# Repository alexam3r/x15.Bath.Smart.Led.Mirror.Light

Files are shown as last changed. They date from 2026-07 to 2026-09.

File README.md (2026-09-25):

# Проект "Умное зеркало" (интеграция HA, Yandex Алиса)








Умное зеркало в ванной на **ESP32-S3 Zero** с адресной лентой **SK6812-RGBW** (168 светодиодов), управляемое через **Home Assistant** и **Алису** (Yandex Smart Home).

Прошивка (v1.5.1, модульная архитектура — см. [ARCHITECTURE.md](ARCHITECTURE.md)) оптимизирована для
low-latency анимации на двух ядрах, с автодетекцией движения (PIR) и аппаратной кнопкой.

---

## Возможности

- **2 режима работы**: solid (RGB, тёплый оранжевый по умолчанию) и Макияж (белый канал W).
- **6 временных эффектов** (запускаются поверх текущего режима): тёмная змейка (`dark`), радужная змейка
  (`rainbow`; с v1.4.2 шесть её цветов при каждом запуске идут в случайном порядке), волна с затемнением (`wave`), «пламя» (`flame`, v1.4.0–1.4.1) — участки по 10–12 светодиодов
  с мягкими краями по 3–4, каждый в своё время, плавно гаснут до 30 % (для глаза) за 3–5 секунд и возвращаются, ~20 секунд,
  «угли» (`embers`, v1.2.0, переделан в v1.3.0–1.3.1) — отдельные пятна
  по очереди, каждое в своё время, мягко гаснут до 10–30 % с плавным краем по 2 светодиода и возвращаются, ~20 секунд,
  и «метеор» (`comet`, v1.2.0) — белая голова с гаснущим хвостом облетает кольцо за 6 секунд. «Свеча»
  (`candle`) была в v1.2.0 и убрана в v1.3.0: её мерцание было почти незаметно. «Дыхание» (`breathe`,
  v1.2.0–v1.3.2) гасило всё кольцо разом; в v1.4.0 его заменило «пламя».
- **JSON Light `effect`** — одно поле в команде `set` принимает `solid, makeup, random, dark, rainbow, wave, flame, embers, comet`:
  базовые режимы и запуск эффектов не требуют отдельных топиков.
- **Аппаратная кнопка** (триггер Шмитта SN74LVC2G14): 1 клик — вкл/выкл, 2 клика — toggle Макияж, 3 клика — случайный эффект, удержание — плавное диммирование при горящем свете, а при выключенном — ночной режим (v1.5.0).
- **Сброс настроек при выключении** — цвет возвращается к тёплому (255, 140, 50), яркость к 100%, режим — solid.
  Автоматика, ночной режим и глитч при этом не сбрасываются и переживают даже программную перезагрузку
  (watchdog, сбой) — но не отключение питания (v1.2.1).
- **Плавные переходы цвета и яркости** (v1.2.0) — смена цвета, яркости или режима из HA/Алисы, переключателем
  Макияжа или двойным кликом идёт плавно за 0,5 с; диммирование кнопкой — как прежде, сразу.
- **PIR с фиксированным кулдауном 15 секунд** — после ручного выключения автоматика «спит», чтобы свет не зажёгся в спину выходящему человеку.
- **Blackout-окно 2 секунды после любого OFF** — PIR полностью игнорируется в первые секунды, чтобы ложные импульсы от «отлипающего» датчика или отражений не запустили slide-IN поверх идущего slide-OUT.
- **«Глухое» отключение PIR через MQTT** — отдельная команда `motion_disable/set` для Node-RED: «на ночь отключить реакцию на PIR». Не выводится в HA — независимый флаг, отдельный от обычной автоматики `motion/set`. Если в момент команды зеркало горит, оно само гаснет. Снимается командой `OFF` или удержанием кнопки (≥0.5 с). Любое включение (кнопка / MQTT / makeup-on) автоматически снимает disable.
- **Автоматика PIR (`motion/set`) — постоянный переключатель.** Состояние держится до явной команды
  `motion/set ON`/`OFF` (в HA — `switch`), а не «отскакивает» самопроизвольно через 15 секунд.
- **Таймер автовыключения 15 минут**, а в режиме Макияж — **45 минут** (v1.2.0): красятся дольше, чем принимают душ.
  PIR, который час подряд показывает движение без единой паузы, считается неисправным и перестаёт держать
  свет, пока не «отпустит» (v1.2.1).
  Если в ванной никого нет, свет гаснет; любое движение сбрасывает таймер в ноль, смена режима — тоже.
- **Предупреждение за минуту до автовыключения** (v1.2.0) — свет плавно притухает вдвое (для глаза, с v1.3.0) за 2 с: махните рукой,
  и он вернётся к полной яркости за 1 с, а таймер начнётся заново. Настройка яркости в HA при этом не меняется.
- **Глитч «сбой неона»** (v1.1.0) — примерно раз в минуту (случайно 45–90 с) случайный участок из 3–6 соседних
  светодиодов на 300–600 мс мерцает, как барахлящая неоновая трубка: гаснет, тлеет, вспыхивает; по краям
  — по 4–6 светодиодов плавного перехода к обычному свету, равномерного для глаза (v1.3.0; в v1.1.1 было 2–3).
  Только в solid,
  когда зеркало горит в покое (без эффекта, анимации и зажатой кнопки) и автоматика включена; состояние в HA
  не меняет. Выключается переключателем «Зеркало: глитч» (`glitch/set`).
- **Автоэффект через 4-5 минут простоя** (рандом в этом диапазоне после каждого запуска) — только в solid-режиме. В Макияже автоэффекты не запускаются; ручные (3 клик / кнопка HA) работают в обоих режимах.
- **`availability`** (LWT, retained) — Home Assistant показывает зеркало «недоступно», если оно пропало из сети (потеря питания/WiFi/MQTT).
- **`pir/state`** — отдельный retained-топик с сырым уровнем PIR (реальное движение); не путать с `motion/state` (флаг автоматики).
- **Диагностика в Home Assistant** (v1.2.0) — отдельный топик `diag` раз в минуту: аптайм, уровень WiFi,
  причина последней перезагрузки, свободная и минимальная свободная память, крупнейший свободный блок
  (v1.2.1), последний запущенный эффект (v1.2.2, приходит сразу при запуске), версия прошивки. Шесть
  диагностических сенсоров; в основной статус светильника не попадает, чтобы не дёргать его каждую секунду.
- **Serial-логи** — PIR rising-edge (не спамит на каждом тике цикла), mode transitions, авто-выключение, эффекты, однократно — запас стека `NetworkTask` после первого подключения к MQTT. Включаются флагом сборки `DEBUG_LOG_ENABLED` — окружение `esp32-s3-zero-debug` (1) или `esp32-s3-zero` (0, продакшен), см. `platformio.ini`.
- **Разделённые MQTT-топики** — `set` (JSON Light), `motion/set`, `motion_disable/set`, `makeup/set`, `effect/set`.
- **Network watchdog** — если Wi-Fi недоступен **более 5 минут**, ESP перезагружается, но только когда зеркало уже 30 секунд тёмное и никто не двигается: горящее зеркало не гаснет посреди использования, а перезагрузка сразу после выключения не зажжёт свет в спину уходящему. Пропажа одного MQTT-брокера (HA обновляется) перезагрузку не вызывает; если брокер недоступен больше 30 минут при живом Wi-Fi, зеркало переподключается к Wi-Fi — это лечит протухший адрес после замены роутера (v1.2.1). Локальная работа зеркала (PIR, кнопка, эффекты) при отсутствии сети не страдает.
- **Yandex Smart Home** — голосовое управление через Алису: «включи зеркало», «поставь режим макияж», «поставь таймер 45 минут», «выключи автоматику».

---

## Аппаратная часть

| Компонент | Кол-во / модель |
|---|---|
| MCU | ESP32-S3 Zero (4 MB Flash, USB-CDC) |
| LED-лента | SK6812 RGBW, 60 LED/m |
| Лента слева | 66 LED (PIN 4) |
| Лента справа | 102 LED (PIN 5) |
| Status LED | 1 × WS2812B на PIN 21 |
| PIR-датчик | HC-SR501 / AM312 на PIN 6 |
| Кнопка | Тактовая на PIN 7 (через SN74LVC2G14) |

### Схема подключения

```
                         ┌─────────────────┐
                         │   ESP32-S3 Zero │
                         │                 │
   SK6812 (left, 66) ────┤ GPIO 4   GPIO 5 ├──── SK6812 (right, 102)
                         │                 │
   PIR (HC-SR501) ───────┤ GPIO 6   GPIO 7 ├──── Кнопка → SN74LVC2G14 → GND
                         │                 │
   Status LED (WS2812B) ─┤ GPIO 21  USB-CDC├──── Serial / питание
                         │                 │
                         │    3V3   GND    │
                         └─────────────────┘
```

### Питание

- Ленты 5 В, ток до ~3.5 А при 168 LED на полной яркости белого.
- Рекомендуется отдельный источник 5 В × 5 А, общая земля с ESP32.
- Питание лент через MOSFET или силовой ключ с управлением от GPIO, если хотите гарантированно снимать питание в OFF.

---

## Софт

### Требования

- [PlatformIO](https://platformio.org/) (CLI или IDE)
- Python 3 (для тулчейна)

### Сборка и прошивка

```bash
git clone git@github.com:alexam3r/x15.Bath.Smart.Led.Mirror.Light.git
cd x15.Bath.Smart.Led.Mirror.Light/firmware
pio run -e esp32-s3-zero -t upload
pio device monitor  # serial-лог (115200 бод)
```

Окружения (`firmware/platformio.ini`):

| env | Назначение |
|---|---|
| `esp32-s3-zero` | продакшен, `DEBUG_LOG_ENABLED=0` |
| `esp32-s3-zero-debug` | то же + `DEBUG_LOG_ENABLED=1` (Serial-логи PIR/режимов/эффектов через USB-CDC) |
| `native` | unit-тесты ядра (`firmware/lib/MirrorCore`) на ПК, без железа: `pio test -e native` |

Подробности сборки (закреплённые версии платформы/библиотек, флаги) — [ARCHITECTURE.md, §9](ARCHITECTURE.md).

### Конфигурация — `firmware/src/secrets.h`

Содержит только креды WiFi/MQTT и базовый MQTT-топик. **Не коммитится** (в `.gitignore`) — шаблон:
`firmware/src/secrets.h.sample`.

```cpp
#pragma once
#include <stdint.h>
// Copy to secrets.h (gitignored) and fill in. Included ONLY by Network.cpp.
constexpr char     WIFI_SSID[]   = "YOUR_WIFI_SSID";
constexpr char     WIFI_PASS[]   = "YOUR_WIFI_PASSWORD";
constexpr char     MQTT_SERVER[] = "YOUR_MQTT_HOST";
constexpr uint16_t MQTT_PORT     = 1883;
constexpr char     MQTT_USER[]   = "YOUR_MQTT_USER";
constexpr char     MQTT_PASS[]   = "YOUR_MQTT_PASSWORD";
constexpr char     MQTT_BASE[]   = "home/flat8/bath/mirror";   // no trailing slash
```

Все MQTT-топики строятся из `MQTT_BASE` при старте (`Topics::init`) — отдельных `TOPIC_*`-констант больше
нет. Флаг `DEBUG_LOG_ENABLED` (Serial-логи) переехал из `secrets.h` в `platformio.ini`
(`build_flags` окружений `esp32-s3-zero` / `esp32-s3-zero-debug`) — в `secrets.h` его больше нет.

> Старый `secrets.h` от v27 соберётся только если в нём остались имена `WIFI_SSID`, `WIFI_PASS`,
> `MQTT_SERVER`, `MQTT_PORT`, `MQTT_USER`, `MQTT_PASS`, `MQTT_BASE` — остальные v27-константы
> (`HA_DISCOVERY_PREFIX`, `TOPIC_*`) не мешают компиляции, но бесполезны. Рекомендуется пересоздать файл
> из нового `secrets.h.sample`.

---

## MQTT-интерфейс

Базовый топик — `MQTT_BASE` из `secrets.h` (в production `home/flat8/bath/mirror`). Полная спецификация
(JSON-схемы `set`/`state`, порядок применения полей, все топики) — в
[ARCHITECTURE.md, §5 «MQTT-протокол»](ARCHITECTURE.md). Коротко:

### Команды (вход)

| Топик | Payload | Назначение |
|---|---|---|
| `set` | JSON: `state`, `brightness`, `color`, `effect` | Полное управление (HA JSON Light). `effect` принимает `solid, makeup, random, dark, rainbow, wave, flame, embers, comet` |
| `+/set` | wildcard | Подписка на любой из разделённых топиков |
| `motion/set` | switch-payload (`ON`/`OFF`/`1`/`0`/`TRUE`/`FALSE`, регистр не важен) | Включить/выключить PIR-автоматику. Состояние **постоянное** — держится до следующей команды. Повторный `ON`, когда автоматика уже включена, не отменяет 15-секундную паузу PIR |
| `motion_disable/set` | switch-payload | «Глухое» отключение PIR. НЕ в HA, для Node-RED; с кнопки — удержанием при выключенном свете (v1.5.0). Снимается `OFF`, удержанием кнопки (≥0.5 с) или включением света. Повторный `OFF`, когда ночной режим уже снят, ничего не меняет и не отменяет 15-секундную паузу PIR |
| `makeup/set` | switch-payload | Toggle режима Макияж (белый канал). Если свет был выключен — включает его |
| `effect/set` | любой | Запустить случайный эффект (аналог тройного клика кнопки) |
| `glitch/set` | switch-payload | Включить/выключить глитч «сбой неона» (v1.1.0). После отключения питания снова включён; программную перезагрузку переживает (v1.2.1) |

Невалидный JSON или мусорный switch-payload — команда отбрасывается, пишется в лог (в debug-сборке).

### Пример (Node-RED): отключить PIR на ночь

```bash
# 23:00 — «глухо» отключить PIR. Если в этот момент свет горит — погаснет сам.
mosquitto_pub -h 10.0.0.1 -t home/flat8/bath/mirror/motion_disable/set -m 'ON'

# утром — включить обратно либо этой командой, либо удержанием кнопки (≥0.5 с)
mosquitto_pub -h 10.0.0.1 -t home/flat8/bath/mirror/motion_disable/set -m 'OFF'
```

### Пример: JSON-команда «включить на 50 %» (тёплый)

```bash
mosquitto_pub -h 10.0.0.1 -t home/flat8/bath/mirror/set -m '{
  "state": "ON",
  "brightness": 128
}'
```

### Телеметрия (выход)

| Топик | retain | Назначение |
|---|---|---|
| `state` | да | JSON-статус: `state`, `brightness`, `color`, `color_mode`, `effect`, `automation`, `night_mode`, `glitch`, `fw`, + устаревшие совместимые поля (`brightness_pct`, `moveDetection`, `makeup`) |
| `motion/state` | да | `ON`/`OFF` — флаг автоматики (`switch` в HA) |
| `motion_disable/state` | **нет** | `ON`/`OFF` — «глухой» ночной режим. Только для Node-RED, не в HA. После включения питания — `OFF`; программную перезагрузку (watchdog, сбой) переживает (v1.2.1) |
| `makeup/state` | да | `ON`/`OFF` — режим Макияж |
| `pir/state` | да | `ON`/`OFF` — сырой уровень PIR (реальное движение), для `binary_sensor` |
| `availability` | да | `online`/`offline` — LWT; HA показывает «недоступно», если зеркало пропало из сети |
| `glitch/state` | да | `ON`/`OFF` — флаг глитча (`switch` в HA) |
| `diag` | да | JSON-диагностика (v1.2.0), раз в минуту: `uptime_s`, `rssi`, `reset_reason`, `free_heap`, `min_free_heap`, `max_alloc_heap`, `last_effect`, `fw` |

Все `*/state` публикуются целиком при (пере)подключении к MQTT, далее — только изменившиеся; основной
`state` дополнительно раз в 10 секунд (heartbeat).

---

## Home Assistant

HA MQTT Discovery в v1.0.0 **удалён** — зеркало ничего не публикует в `homeassistant/…/config`. Интеграция
настраивается вручную через YAML: [`ha_mirror.yaml`](ha_mirror.yaml) в корне репозитория. Файл можно положить
в `packages/` (`homeassistant: packages: !include_dir_named packages`) или скопировать его блок `mqtt:` в
`configuration.yaml`. Он описывает:

| Сущность | unique_id | Топики |
|---|---|---|
| light «Зеркало в душевой» — JSON Light: `brightness_scale: 255`, `supported_color_modes: [rgb]`, `effect_list: solid, makeup, random, dark, rainbow, wave, flame, embers, comet` | `mirror_bath_flat8` | `set` / `state` |
| switch «Зеркало: автодетекция движения» | `mirror_motion_switch` | `motion/set` / `motion/state` |
| switch «Зеркало: режим Макияж» | `mirror_makeup_switch` | `makeup/set` / `makeup/state` |
| switch «Зеркало: глитч» (v1.1.0) | `mirror_glitch_switch` | `glitch/set` / `glitch/state` |
| binary_sensor «Движение ванная» (`device_class: motion`) | `mirror_motion_bath_flat8` | `pir/state` |
| button «Зеркало: эффект» | `mirror_effect_button` | `effect/set` |
| sensor «Зеркало: прошивка» (диагностика, поле `fw`) | `mirror_firmware_version` | `state` |
| sensor «Зеркало: аптайм» (v1.2.0) | `mirror_uptime` | `diag` |
| sensor «Зеркало: WiFi» — RSSI, дБм (v1.2.0) | `mirror_wifi_rssi` | `diag` |
| sensor «Зеркало: причина перезагрузки» (v1.2.0) | `mirror_reset_reason` | `diag` |
| sensor «Зеркало: свободная память» (v1.2.0) | `mirror_free_heap` | `diag` |
| sensor «Зеркало: крупнейший блок памяти» (v1.2.1) | `mirror_max_alloc_heap` | `diag` |
| sensor «Зеркало: последний эффект» (v1.2.2) | `mirror_last_effect` | `diag` |

Все сущности зависят от `availability` (LWT). `unique_id` совпадают с прежним конфигом, поэтому история и
привязки в УДЯ сохраняются; «Движение ванная» теперь показывает реальный PIR, а не флаг автоматики.
Команды публикуются **без retain**: прошивка переподписывается на `set` и `+/set` после каждого
переподключения, и retained-команда выполнилась бы повторно. `transition` и `flash` отключены — прошивка
их не поддерживает.

> **Важно:** топик `motion_disable/state` и команда `motion_disable/set` **не выносятся в HA** — они нужны
> для Node-RED (ночная автоматика); с v1.5.0 ночной режим ставится и снимается ещё и удержанием кнопки при
> выключенном свете. Обычный переключатель PIR-автоматики в HA/Алисе — через
> `motion/set`, теперь **постоянный** (не самовосстанавливается через 15 с, как в v27).

---

## Интеграция с Алисой

Сущности ниже описаны в `ha_mirror.yaml` (см. «Home Assistant» выше). Кастомизация capabilities и
добавление объектов делается **только через UI** (ярлыки в Yandex Smart Home):

```
Settings → Devices & Services → Yandex Smart Home → Configure
```

| HA-сущность | Capability Яндекса |
|---|---|
| `light.mirror_bath_flat8` | `on_off`, `brightness` (0..100), `color_setting.rgb` |
| `switch.mirror_motion_switch` | `on_off` (PIR-автоматика) |
| `switch.mirror_makeup_switch` | `on_off` (режим Макияж — белый канал) |
| `switch.mirror_glitch_switch` | `on_off` (глитч «сбой неона»; по желанию, если добавить в УДЯ) |
| `button.mirror_effect_button` | (кнопка — сценарий «запустить случайный эффект») |

Таймеры автовыключения (15 мин) и кулдауна PIR (15 сек) — фиксированные, в УДЯ не выносятся. Эффекты запускаются через кнопку «Эффект» — одна кнопка, случайный.

### Примеры голосовых команд

- «Алиса, включи зеркало»
- «Алиса, выключи зеркало»
- «Алиса, яркость зеркала 40 процентов»
- «Алиса, сделай зеркало жёлтым» / «Алиса, цвет зеркала синий»
- «Алиса, включи макияж» / «выключи макияж»
- «Алиса, включи автоматику» / «выключи автоматику»
- «Алиса, запусти эффект на зеркале»

---

## Архитектура прошивки

Два ядра ESP32-S3 общаются только через две очереди FreeRTOS (`cmdQueue`, `snapQueue`) — без мьютексов и
`volatile`-глобалов. **Core 0** (`NetworkTask`) владеет WiFi/MQTT/status LED и физически не может тронуть
ленту: `Network.cpp` даже не включает заголовки `Mirror`/`LedDriver`, так что вызвать отрисовку с сетевого
ядра невозможно на уровне компиляции. **Core 1** (`loop()`) владеет кнопкой, PIR, конечным автоматом
`Mirror` и выводом на ленту (`LedDriver`, две `Adafruit_NeoPixel`). Чистая логика — `Mirror`, эффекты
(`dark`/`rainbow`/`wave` + slide power-анимация), MQTT-протокол, автоматика PIR — живёт в
`firmware/lib/MirrorCore`: без Arduino/FreeRTOS, тестируется на ПК (`pio test -e native`, 257 тестов, включая симуляцию долгой работы `test_soak`).
Network watchdog перезагружает ESP после 5 минут без WiFi — только когда зеркало уже 30 секунд тёмное и PIR молчит; простой одного MQTT перезагрузку не вызывает, а через 30 минут переподключает WiFi.

Полное описание — двухядерная модель, конечный автомат зеркала, MQTT-протокол, кольцо светодиодов,
реестр эффектов, структура модулей, критические правила — в **[ARCHITECTURE.md](ARCHITECTURE.md)**.

---

## Управление кнопкой

| Действие | Эффект |
|---|---|
| 1 короткий клик | Вкл (со slide-анимацией) / Выкл. При включении снимается ночной режим и 15-сек кулдаун, а с v1.5.0 заодно включается автоматика (`motion/set ON`) — зеркало, включённое рукой, погаснет по таймеру, а не будет гореть бесконечно |
| 2 коротких клика | Toggle режима «Макияж» (белый канал W). Если свет выключен — включает сразу в Макияже (и, как клик, включает автоматику) |
| 3 коротких клика | Случайный эффект (работает в обоих режимах) |
| Удержание ≥ 0.5 с | **Свет выключен (или гаснет):** включает/выключает ночной режим (`motion_disable`, v1.5.0) — датчик движения перестаёт/снова начинает зажигать свет. Свет не загорается, яркость не меняется; тёмное кольцо подтверждает: **одна** мягкая вспышка — ночной режим включён, **две** — снят (после снятия PIR ещё 15 с молчит, чтобы не зажечь свет тому, кто держит кнопку). Вместе с ночным режимом переключается и «Зеркало: автодетекция движения» в HA (v1.5.1): выключается при включении ночного режима, включается при снятии — в HA видно, зажигает ли датчик свет. **Свет горит:** плавное диммирование (пила 5↔255, шаг 5 каждые 30 мс). До v1.5.0 удержание при выключенном свете включало его |

Антидребезг — аппаратный, через триггер Шмитта SN74LVC2G14 (инвертированная логика, `BTN_PRESSED = HIGH`).

Удержание дольше 60 секунд считается залипанием кнопки (например, от влаги): диммирование останавливается до
отпускания, и зеркало гаснет по обычному таймеру (v1.2.1).

---

## Проверка на железе после прошивки

Чек-лист ручной проверки (выполняет владелец после прошивки):

> **Результат для v1.0.0:** 22.09.2026 прошивка собрана, прошита в зеркало и работает так же, как v27.
> **Результат для v1.0.1:** 22.09.2026 прошита в зеркало; новая скорость анимации включения/выключения проверена
> вживую — отличная.
> **Результат для v1.3.1:** 23.09.2026 прошита в зеркало (вместе со всем из v1.2.0–v1.3.0); владелец посмотрел
> эффекты и работу зеркала — «вроде всё гуд, пока оставляем так». Тег `v1.3.1`.
> **Результат для v1.4.1:** 24.09.2026 прошита в зеркало; «пламя» — «теперь лучше, flame оставляем так».

1. Нет мерцания ленты при активном WiFi/MQTT трафике (статика и все эффекты).
2. 1/2/3 клика, удержание (диммирование), удержание в ночном режиме (свет не включается — в т.ч. от PIR
   в ближайшие 15 с, даже если стоять перед зеркалом).
3. PIR: автовключение; после ручного выкл — 15 с тишины; после auto-off — 2 с blackout.
4. HA: вкл/выкл, яркость, цвет, каждый эффект из `effect_list`, `availability` при отключении питания.
5. Алиса: «включи зеркало», «включи макияж», «выключи автоматику».
6. Во время эффектов и диммирования при мигании статус-светодиода (мигает только на heartbeat `state` раз
   в 10 с; публикации по событиям его не трогают) нет сбоев кадра и перезагрузок (известный риск R12
   библиотеки NeoPixel).
7. Глитч (v1.1.1, края — v1.3.0): в solid примерно раз в минуту на полсекунды мерцают 3–6 соседних светодиодов
   с мягкими краями по 4–6 светодиодов, заметно плавными; в Макияже,
   во время эффекта и при зажатой кнопке его нет; переключатель «Зеркало: глитч» его выключает.
8. Переходы (v1.2.0): смена цвета и яркости из HA и переключение Макияжа идут плавно за полсекунды, без
   рывка и без мигания; диммирование удержанием кнопки — сразу, как раньше; включение из выключенного
   состояния сразу показывает нужный цвет (проверить двойным кликом, пока зеркало гаснет).
9. Затухание перед автовыключением (v1.2.0): если не двигаться, за минуту до выключения свет плавно уходит
   на половину; взмах рукой возвращает полную яркость и перезапускает таймер.
10. Таймер Макияжа (v1.2.0): в режиме Макияж свет держится 45 минут, а не 15.
11. Новые эффекты (v1.2.0): `breathe` — дыхание кольца (с v1.4.0 — `flame`, п. 23), `embers` — тление
    отдельных светодиодов, `comet` — белая голова с хвостом делает круг (`candle` убран в v1.3.0). Проверить и в solid, и в Макияже.
12. Диагностика (v1.2.0): в HA появились сенсоры аптайма, уровня WiFi, причины перезагрузки и свободной
    памяти; обновляются раз в минуту, причина перезагрузки после прошивки по USB — обычно `SW` или `POWERON`.
13. Повтор кадра (v1.2.1): лента теперь переотправляет кадр раз в 2 с и в статике — пункт 1 (нет мерцания)
    повторить на статичном свете и на выключенном зеркале, в том числе ночью в темноте.
14. Загрузка (v1.2.1): после нажатия кнопки сброса на плате лента гаснет сразу, без 3-секундной задержки.
15. Сеть (v1.2.1): выключить роутер при горящем зеркале — свет не гаснет, пока зеркало не выключат; через
    30 с после выключения (и 5 мин без WiFi) зеркало перезагружается и само не загорается. Выключить только
    брокер (остановить Mosquitto) — зеркало не перезагружается, работает локально, после запуска брокера
    само переподключается, и в HA сначала приходит настоящее состояние, потом «доступно».
16. Флаги (v1.2.1): включить `motion_disable` из Node-RED, перезагрузить зеркало программно (например,
    выключить роутер на 6 минут при тёмном зеркале) — ночной режим остался; выдернуть питание — сброшен.
17. Команды (v1.2.1): во время предупреждающего затухания сказать Алисе «яркость зеркала 80 %» — затухание
    снимается, таймер начинается заново; выбор `solid` в списке эффектов HA во время `embers` сразу его
    останавливает.
18. Сенсоры (v1.2.1): «причина перезагрузки» и «крупнейший блок памяти» — понаблюдать неделю: блок памяти
    не должен падать при стабильной свободной памяти, а причины `TASK_WDT`/`BROWNOUT` говорят о проблеме.
19. «Угли» (v1.3.1): отдельные пятна по 5 светодиодов в разное время мягко гаснут почти до темноты (10–30 %)
    с плавным краем, а не всё кольцо рябит; не похоже на выпавшие пиксели.
20. Глитч (v1.3.0): края — плавный градиент на 4–6 светодиодов с каждой стороны.
21. Шкала CIE (v1.3.0): дыхание (`breathe`, с v1.4.0 — `flame`), хвост метеора и затухание перед выключением — плавные на глаз
    и заметно глубже, чем раньше; смена цвета из HA идёт ровно, без «проскакивания» тёмной части.
22. Анимация включения/выключения (v1.3.2): мягкий край заметно длиннее (15 светодиодов вместо 10) и ровный
    на глаз — без резкой ступеньки у полного цвета; вся анимация ≈ 3,4 с; скорость бегущего края прежняя.
23. «Пламя» (v1.4.0, шире и глубже в v1.4.1): сначала обновить `ha_mirror.yaml` в HA (в списке эффектов
    `flame` вместо `breathe`) и перезагрузить MQTT. `flame` — около 20 с в разных местах кольца по очереди
    плавно гаснут почти до трети яркости и возвращаются участки по 10–12 светодиодов с мягкими краями по 3–4,
    около 4 одновременно, каждый в своём ритме; эффект хорошо заметен, всё кольцо разом не гаснет. Проверить
    и в solid, и в Макияже.
24. Радуга (v1.4.2): запустить `rainbow` несколько раз подряд — порядок цветов каждый раз другой, переходы
    между ними плавные и насыщенные, без серых провалов; длина, скорость, появление и исчезание — как раньше.
25. Ночной режим с кнопки (v1.5.0–1.5.1): при выключенном свете подержать кнопку — одна мягкая вспышка, свет
    не включается, датчик движения больше не зажигает зеркало (проверить, пройдясь перед ним через 20 с), в HA
    «Зеркало: автодетекция движения» выключилась. Подержать ещё раз — две вспышки, выключатель в HA включился,
    через 15 с датчик снова работает. Подержать сразу после выключения
    кликом, пока кольцо гаснет, — вспышка после того, как оно погасло. При горящем свете удержание, как и
    раньше, меняет яркость. Выключить в HA «Зеркало: автодетекция движения», включить свет кликом —
    выключатель в HA сам включается, и зеркало гаснет по таймеру.

---

## Структура репозитория

```
.
├── README.md                          # ← вы здесь (титульная страница GitHub)
├── ARCHITECTURE.md                    # спецификация модульной архитектуры v1
├── firmware/                          # PlatformIO-проект (корень сборки)
│   ├── platformio.ini                 # 3 окружения: esp32-s3-zero(-debug), native
│   ├── lib/MirrorCore/src/            # чистая логика (C++17, без Arduino/FreeRTOS) — тестируется на ПК
│   ├── src/                           # железо и сеть (Arduino/FreeRTOS)
│   │   ├── main.cpp                   # setup/loop, очереди, static-объекты Core 1
│   │   ├── Network.{h,cpp}            # NetworkTask: WiFi, MQTT, watchdog, публикация
│   │   ├── LedDriver.{h,cpp}          # 2 × Adafruit_NeoPixel, вывод на ленты
│   │   ├── StatusLed.{h,cpp}          # статусный WS2812 (Core 0)
│   │   ├── secrets.h                  # WiFi/MQTT credentials, MQTT_BASE (в .gitignore)
│   │   └── secrets.h.sample           # шаблон secrets.h (коммитится в репо)
│   └── test/                          # Unity-тесты MirrorCore, env:native
└── ha_mirror.yaml                     # HA YAML: MQTT JSON Light + switch/binary_sensor/button/sensor
```

Каталог `firmware/` самодостаточен — это корень PlatformIO-проекта. Команды сборки/прошивки выполняются из него:

```bash
cd firmware
pio run -e esp32-s3-zero -t upload
```

Дополнительные каталоги проекта (например, `Altium/` для схем и PCB) добавляются в корень репозитория независимо.

---

## История версий

- **v1.5.1** (текущая) — ночной режим с кнопки переключает и «Зеркало: автодетекция движения» в HA: удержание,
  включающее ночной режим (одна вспышка), выключает её, снимающее (две вспышки) — включает. В HA видно,
  зажигает ли датчик свет. 257 тестов.
- **v1.5.0** — ночной режим с кнопки: при выключенном свете удержание включает и выключает его
  (датчик движения перестаёт или снова начинает зажигать свет), тёмное кольцо подтверждает одной мягкой
  вспышкой (включён) или двумя (снят); удержание во время гашения работает так же. Клик, включающий свет,
  заодно включает автоматику — зеркало, включённое рукой, больше не горит до ручного выключения. Раньше
  удержание при выключенном свете включало его. 257 тестов.
- **v1.4.2** (тег `v1.4.2`) — радужная змейка при каждом запуске перемешивает шесть своих цветов (красный, жёлтый,
  зелёный, голубой, синий, фиолетовый) в случайном порядке; между ними цвет перетекает кратчайшим путём по
  цветовому кругу, всегда насыщенный. Остальное в эффекте прежнее. 245 тестов.
- **v1.4.1** (проверена на зеркале 24.09.2026 — «теперь лучше») — «пламя» было почти незаметно: блоки шире — ровное ядро 10–12 светодиодов плюс
  градиент по 3–4 с каждой стороны пропорционально ядру (16–20 всего вместо 10–15), — и глубже: до 30 % для
  глаза вместо 60 %. Около 4 блоков одновременно. 242 теста.
- **v1.4.0** — эффект «дыхание» (`breathe`) заменён на «пламя» (`flame`): вместо всего кольца разом
  «дышат» отдельные участки по 10–15 светодиодов с мягкими краями по 3 светодиода, каждый на своих часах, 4–5
  одновременно, до той же глубины 60 % для глаза за 3–5 с; эффект длится ~20 с. В `ha_mirror.yaml` — `flame`
  вместо `breathe`. 242 теста.
- **v1.3.2** — мягкий край анимации включения/выключения в шкале яркости для глаза CIE 1931 и в
  полтора раза длиннее: 15 светодиодов вместо 10, ровный на глаз градиент без «пустой» тёмной половины;
  анимация ≈ 3,4 с вместо ≈ 3,2 с при той же скорости 33 мс на светодиод. 241 тест.
- **v1.3.1** (тег `v1.3.1`, проверена на зеркале 23.09.2026 — «вроде всё гуд») — «угли» глубже: центр уголька гаснет до 10–30 % для глаза, с градиентным краем по
  2 светодиода с каждой стороны; пятна реже и не ближе 5 светодиодов друг к другу. 239 тестов.
- **v1.3.0** — по отзыву с зеркала: все новые градиенты считаются в
  шкале яркости для глаза CIE 1931 — плавно и заметно, а не «почти незаметно»; «свеча» убрана; «угли»
  переделаны: около каждого восьмого светодиода в своё время мягко гаснет до 30–50 % вместе с соседями;
  края глитча — 4–6 светодиодов; дыхание, затухание перед выключением и хвост метеора стали глубже. 239 тестов.
- **v1.2.2** (на железе — в составе v1.3.1) — сенсор «Зеркало: последний эффект»: имя последнего
  запущенного эффекта приходит в HA сразу при запуске и остаётся после его окончания — чтобы понять, какой
  эффект только что был на зеркале. 237 unit-тестов.
- **v1.2.1** (на железе — в составе v1.3.1) — ревизия надёжности для круглосуточной работы. Медленный
  MQTT-брокер больше не перезагружает зеркало (таймаут сокета 3 с меньше watchdog); watchdog на ядре 1 —
  зависание перезагружает, а не замораживает; общая блокировка RMT для ленты и статус-светодиода и повтор кадра
  раз в 2 с; лента гасится сразу при загрузке; «умный» сетевой watchdog (без WiFi 5 мин — перезагрузка только
  после 30 с тишины, без MQTT — переподключение WiFi через 30 мин); автоматика, ночной режим и глитч
  переживают программную перезагрузку; защита от залипших кнопки и PIR; команды из HA/Алисы снимают
  затухание; выбор `solid`/`makeup` останавливает эффект; потокобезопасный поиск брокера; сенсор
  крупнейшего блока памяти. 233 unit-теста, включая симуляцию долгой работы `test_soak`.
- **v1.2.0** (на железе — в составе v1.3.1) — плавные переходы цвета и яркости (0,5 с); затухание до
  50 % за минуту до автовыключения; 45 минут таймера в режиме Макияж; четыре новых эффекта — `breathe`,
  `embers`, `candle`, `comet`; диагностический топик `diag` и четыре сенсора в HA. 191 unit-тест.
- **v1.1.1** — у глитча мягкие края: по 2–3 светодиода с каждой стороны плавно переходят от
  мерцающего ядра к обычному свету (весь участок 7–12 светодиодов). 147 unit-тестов.
- **v1.1.0** — глитч «сбой неона»: примерно раз в минуту (45–90 с) 3–6 соседних светодиодов на
  300–600 мс мерцают, как барахлящий неон; только в solid и в покое, не меняет состояние в HA; переключатель
  `glitch/set` / `glitch/state` («Зеркало: глитч» в `ha_mirror.yaml`), поле `glitch` в `state`. 146 unit-тестов.
- **v1.0.1** (тег `v1.0.1`; проверена на железе 22.09.2026 — скорость анимации отличная) —
  анимация включения/выключения на ~20% медленнее и мягче: шаг 33 мс вместо 28
  (≈3,2 с вместо ≈2,7 с), мягкий край кольца 11 светодиодов вместо 9. В HA сенсор прошивки покажет `1.0.1`.
- **v1.0.0** (проверена на железе 22.09.2026 — работает так же, как v27) — порт прошивки
  v27 с монолитного `main.cpp` на модульную архитектуру (`firmware/lib/MirrorCore` — чистая тестируемая
  логика, `firmware/src` — железо и сеть, две очереди FreeRTOS вместо мьютекса и `volatile`-глобалов,
  129 unit-тестов на ПК; в v1.0.1 — 130). Нумерация версий начата
  заново с 1; визуальное поведение (скорости, размеры, цвета) сохранено.
  Намеренные изменения поведения: `effect` в JSON Light (`solid, makeup, random, dark, rainbow, wave, breathe, embers, comet`);
  цвет из HA/Алисы переключает в `solid`; `motion/set OFF` теперь постоянный (раньше автоматика сама
  возвращалась через 15 с); `motion/state` — теперь только флаг автоматики, реальное движение — новый
  `pir/state`; LWT `availability`; удержание кнопки из `OFF` включает свет со slide-анимацией; включение
  во время slide-out разворачивает анимацию с текущего радиуса; единообразный switch-payload
  (`ON/OFF/1/0/TRUE/FALSE`); `brightness: 0` = выключение; HA MQTT Discovery удалён (ручной
  `ha_mirror.yaml`); стабильный MQTT client id по MAC; в `state` добавлены `effect`, `automation`,
  `night_mode`, `fw` (полный список — ARCHITECTURE.md §11.1).
  Исправленные баги v27: удержание для снятия ночного режима больше не «утекает» в диммирование и не
  включает свет; Discovery-пакет (не помещавшийся в 256-байтный буфер PubSubClient) убран вместе с
  Discovery, буфер увеличен до 512; `motion/state` теперь переопубликовывается при каждом подключении;
  таймеры переведены на разность `now − start` (переживают переполнение `millis()` через 49,7 сут);
  единственная точка переходов состояния — конечный автомат `Mirror`; повторные `motion_disable/set OFF` и
  `motion/set ON` (когда ночной режим уже снят / автоматика уже включена) больше не отменяют 15-секундную
  паузу PIR (полный список — ARCHITECTURE.md §11.2).
- **v27** — упрощения: PIR-защита (blackout + rising-edge, реакция только на `MODE_OFF`), команда `motion_disable/set` для Node-RED без авто-возврата (снимается командой `OFF` или удержанием кнопки), Serial-логи через `DEBUG_LOG_ENABLED`, `secrets.h.sample` как публичный шаблон, **network watchdog** (Wi-Fi + MQTT, ребут через 5 мин суммарного downtime), motion_disable-семантика по 5 сценариям, антиспам PIR-лога.
- **v26** — NVS-конфиг, расширенный JSON, разделённые топики, HA Discovery, support Алисы.
- **v25** — двухядерная архитектура, `show()` вне мьютекса, `volatile` для shared-флагов, `scale8()`.
- **v24** — JSON Light, mutex-защита AppState.

---

## Лицензия

MIT. См. [LICENSE](LICENSE).

---

## Благодарности

- [Adafruit NeoPixel](https://github.com/adafruit/Adafruit_NeoPixel) — управление SK6812.
- [PubSubClient](https://github.com/knolleary/pubsubclient) — MQTT-клиент.
- [ArduinoJson](https://arduinojson.org/) v7 — парсинг JSON.
- [Espressif ESP-IDF](https://github.com/espressif/esp-idf) — базовый тулчейн.

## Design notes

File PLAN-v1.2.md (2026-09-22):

# План реализации v1.2.0 — новые эффекты и автоматика

> **Для агентов:** ОБЯЗАТЕЛЬНЫЙ СКИЛЛ — superpowers:subagent-driven-development (рекомендуется) или
> superpowers:executing-plans, задача за задачей. Шаги отмечаются чекбоксами (`- [ ]`).
>
> **Режим работы (требование владельца):** каждая задача — отдельный коммит со своим сообщением (на русском).
> После коммита каждой задачи — **пауза**: следующая задача начинается только после «продолжай» владельца.

**Цель:** добавить в прошивку зеркала четыре эффекта (`breathe`, `embers`, `candle`, `comet`), плавные переходы
цвета и яркости, предупреждающее затухание за минуту до автовыключения, 45-минутный таймер в режиме Макияж и
топик диагностики для Home Assistant — версия прошивки 1.2.0.

**Архитектура:** вся логика остаётся в `firmware/lib/MirrorCore` (чистый C++17, тесты на ПК). Эффекты — новые
классы `Effect` в реестре (класс + строка реестра + `effect_list`). Переходы и предупреждение — внутри
конечного автомата `Mirror`, через новый примитив `Ramp` (линейная интерполяция `uint8_t` по времени, переживает
переполнение `millis()`). Диагностика — только Core 0 (`Network.cpp`) плюс сериализация в `Protocol`.

**Стек:** PlatformIO, Arduino-ESP32 2.0.17 (espressif32@7.1.3), Adafruit NeoPixel 1.15.5, PubSubClient 2.8,
ArduinoJson 7.4.3, Unity (`pio test -e native`).

**Спецификация:** `ARCHITECTURE.md` (текущая реализация, §3–§8) + раздел «Дизайн» ниже (что меняется).

## Global Constraints

- MCU ESP32-S3 Zero, Flash 4 MB, `default.csv`; OTA и NVS **не делаем** (решение владельца: прошивка по проводу,
  сброс к дефолтам при выключении — желаемое поведение).
- C++17 (`-std=gnu++17`); ArduinoJson — только API v7 (`JsonDocument`, `isNull()`, `is<T>()`, `to<JsonObject>()`).
- `lib/MirrorCore` — без Arduino/FreeRTOS/Adafruit (кроме `Log.h` под `#ifdef ARDUINO`). Время — параметром `uint32_t now`.
- На Core 1 в горячем пути — никаких `String`, `new`, `malloc`; экземпляры эффектов статические.
- Лента — только Core 1; WiFi/MQTT/Status LED — только Core 0; обмен — только `cmdQueue`/`snapQueue`.
- Все интервалы времени — через `(uint32_t)(now − start)`.
- Шесть критических правил `start_prompt.md` §4 неприкосновенны (в этом плане ни одно не затрагивается,
  но проверка «`pio test -e native` зелёный + обе сборки без предупреждений в наших файлах» — после каждой задачи).
- Сообщения коммитов — **на русском**, завершаются строкой `Co-Authored-By: Claude Fable 5.1 <noreply@anthropic.com>`.
  Push — только по команде владельца.
- TDD: сначала падающий тест (увидеть RED), затем минимальная реализация, затем зелёный прогон.
- Комментарии в коде — на английском (как во всём `MirrorCore`); документация — на русском.
- Команды сборки (из `/home/coe/Projects/mirror/firmware`):
  `export PLATFORMIO_CORE_DIR=/home/coe/Projects/mirror/.tools/pio-core; P=/home/coe/Projects/mirror/.tools/venv/bin/pio`
  тесты: `$P test -e native` (фокус: `-f test_mirror`), сборки: `$P run -e esp32-s3-zero`, `$P run -e esp32-s3-zero-debug`.

---

## Дизайн (что решено и почему)

| № владельца | Что | Решение |
|---|---|---|
| 6 | Плавный переход цвета/яркости | Любое изменение базового цвета, яркости или режима из команды (HA/Алиса), переключателя Макияжа или двойного клика — линейный переход за `TRANSITION_MS = 500` мс шагом 20 мс. Диммирование удержанием кнопки — мгновенное (оно и так ступенчатое каждые 30 мс). Включение из `OFF` — новый цвет сразу, без перехода (slide-анимация играет уже в нём). Эффекты видят текущий (переходный) цвет. В `state` отдаётся целевое значение сразу. |
| 9 | Затухание перед автовыключением | За `AUTO_OFF_WARN_MS = 60` с до автовыключения яркость рендера плавно (2 с) снижается до `WARN_DIM_LEVEL = 128` (50 %). Любая активность (PIR, кнопка, команда, которая и сейчас сбрасывает таймер) — возврат к полной за 1 с и таймер заново. Действует и во время эффекта (эффект рендерится притушенным). Только при включённой автоматике (как и само автовыключение). Настройка `brightness` и `state` в HA не меняются. |
| 8 | Макияж — 45 минут | `AUTO_OFF_MAKEUP_MS = 45` мин вместо 15. Предупреждение — за минуту до соответствующего лимита. Смена режима (solid ↔ makeup) считается активностью, иначе переключение из Макияжа на 30-й минуте в solid мгновенно выключило бы свет. |
| 1 | `breathe` — «дыхание» | Временный эффект: 3 цикла по 4 с (шаг 20 мс, 600 кадров), яркость всего кольца по косинусу от 100 % до 60 % (`BREATHE_MIN_LEVEL = 153`) и обратно. |
| 2 | `embers` — «угли» | Временный эффект ≈ 20 с (шаг 60 мс, 333 кадра, плавный вход/выход 2 с): у каждого светодиода свой уровень 40–100 %, каждый шаг 13 случайных светодиодов получают новую цель, движение к цели ≤ 6/шаг. |
| 3 | `candle` — «свеча» | Временный эффект ≈ 20 с (шаг 40 мс, 500 кадров, вход/выход 1 с): всё кольцо дрожит по яркости 89–100 % (`CANDLE_MIN_LEVEL = 227`), с вероятностью 1/20 — провал до 80–89 %, движение к цели ≤ 8/шаг. Владелец просил «в список эффектов» — поэтому временный, а не фоновый слой. |
| 5 | `comet` — «метеор» | Временный эффект: белая голова `{255,255,255,255}` с хвостом 40 светодиодов (квадратичное затухание), один оборот + хвост (208 шагов по 30 мс ≈ 6,2 с), вход/выход 20 шагов. Пиксель = `lerp(base, white, t)` — добавляет света и в solid, и в Макияже (там растёт RGB поверх W). |
| — | Реестр и `random` | Все четыре входят в `kEffects[]`, `effect_list` HA и в `random` (автоэффект раз в 4–5 мин выбирает из всех семи). |
| 13 | Диагностика | Отдельный retained-топик `<base>/diag` раз в `DIAG_PERIOD_MS = 60` с и при подключении: `{"uptime_s","rssi","reset_reason","free_heap","min_free_heap","fw"}`. Не в `state`: `uptime` меняется каждую секунду и не должен дёргать JSON Light. В `ha_mirror.yaml` — четыре диагностических сенсора. |
| — | Версия | `FW_VERSION = "1.2.0"` ставится в Задаче 1; тег `v1.2.0` — после проверки на железе, по команде владельца. |
| 12, 4, 7, 10, 11 | — | Не делаем (решение владельца). |

**Отклонённая альтернатива:** делать переходы и предупреждение через модификацию `brightness_`/`r_,g_,b_`. Нет —
это цели, которые уходят в HA; для рендера нужны отдельные «показанные» значения, иначе HA будет видеть промежуточные
цвета, а таймеры — путаться.

---

## Файлы

| Файл | Задачи | Ответственность |
|---|---|---|
| `firmware/lib/MirrorCore/src/Ramp.h` (новый) | 1 | Линейная интерполяция `uint8_t` по времени |
| `firmware/lib/MirrorCore/src/ColorMath.{h,cpp}` | 1 | `lerp8`, `lerp(Rgbw, Rgbw, t)` |
| `firmware/lib/MirrorCore/src/Config.h` | 1–8 | Константы `TRANSITION_*`, `AUTO_OFF_WARN_*`, `AUTO_OFF_MAKEUP_MS`, `BREATHE_*`, `EMBERS_*`, `CANDLE_*`, `COMET_*`, `DIAG_*`, `FW_VERSION` |
| `firmware/lib/MirrorCore/src/Mirror.{h,cpp}` | 1, 2, 3 | Переходы, предупреждение, лимит автовыключения по режиму |
| `firmware/lib/MirrorCore/src/Types.h` | 4–7 | Новые значения `EffectId` |
| `firmware/lib/MirrorCore/src/effects/{Breathe,Embers,Candle,Comet}.{h,cpp}` (новые) | 4–7 | Эффекты |
| `firmware/lib/MirrorCore/src/effects/EffectRegistry.cpp` | 4–7 | Строки реестра |
| `firmware/lib/MirrorCore/src/Topics.{h,cpp}`, `Protocol.{h,cpp}` | 8 | `diag`-топик, `DiagInfo`, `buildDiagJson`, `resetReasonName` |
| `firmware/src/Network.cpp` | 8 | Сбор и публикация диагностики |
| `firmware/test/test_ramp/test_main.cpp` (новый) | 1 | Ramp, lerp |
| `firmware/test/test_mirror/test_main.cpp` | 1–3 | Переходы, предупреждение, 45 мин |
| `firmware/test/test_effects/test_main.cpp` | 4–7 | Новые эффекты, реестр |
| `firmware/test/test_protocol/test_main.cpp` | 1, 4–8 | `fw`, имена эффектов, `diag` |
| `ha_mirror.yaml` | 4–8 | `effect_list`, сенсоры диагностики |
| `README.md`, `ARCHITECTURE.md` | каждая задача — свой абзац; 9 — сводка | Документация |

---

### Задача 1: `Ramp`, `lerp` и плавные переходы цвета/яркости (пункт 6)

**Файлы:**
- Создать: `firmware/lib/MirrorCore/src/Ramp.h`, `firmware/test/test_ramp/test_main.cpp`
- Изменить: `firmware/lib/MirrorCore/src/ColorMath.h`, `ColorMath.cpp`, `Config.h`, `Mirror.h`, `Mirror.cpp`,
  `firmware/test/test_mirror/test_main.cpp`, `firmware/test/test_protocol/test_main.cpp`, `README.md`, `ARCHITECTURE.md`

**Интерфейсы:**
- Производит: `struct Ramp { void start(uint8_t from, uint8_t to, uint32_t now, uint32_t durMs); void set(uint8_t v); uint8_t value(uint32_t now); bool running(uint32_t now) const; bool active; }`,
  `uint8_t lerp8(uint8_t a, uint8_t b, uint8_t t)`, `Rgbw lerp(Rgbw a, Rgbw b, uint8_t t)`,
  в `Mirror`: приватные `Rgbw targetColor() const`, `void retarget(uint32_t now, bool smooth)`, `void finishFrame()`,
  поля `shownColor_`, `shownBrightness_`, `fromColor_`, `fromBrightness_`, `Ramp trans_`, `lastTransStepMs_`.
  `baseColor()` теперь возвращает **показанный** цвет `shownColor_`.
- Константы: `cfg::TRANSITION_MS = 500`, `cfg::TRANSITION_STEP_MS = 20`, `cfg::FW_VERSION = "1.2.0"`.

- [ ] **Шаг 1: тесты `Ramp` и `lerp` (RED)**

`firmware/test/test_ramp/test_main.cpp`:

```cpp
// Ramp (linear uint8_t interpolation over time, overflow-safe) and lerp helpers.
#include <unity.h>

#include "ColorMath.h"
#include "Ramp.h"

void setUp(void) {}
void tearDown(void) {}

static void test_lerp8_endpoints_and_midpoint(void) {
    TEST_ASSERT_EQUAL_UINT8(10, lerp8(10, 200, 0));
    TEST_ASSERT_EQUAL_UINT8(200, lerp8(10, 200, 255));
    TEST_ASSERT_EQUAL_UINT8(105, lerp8(10, 200, 128));   // 10 + 190*128/255 = 105
    TEST_ASSERT_EQUAL_UINT8(100, lerp8(200, 0, 128));    // downwards: 200 - 200*128/255 = 100
}

static void test_lerp_rgbw_per_channel(void) {
    const Rgbw a{255, 140, 50, 0};
    const Rgbw b{0, 0, 255, 255};
    const Rgbw m = lerp(a, b, 255);
    TEST_ASSERT_TRUE(b == m);
    const Rgbw h = lerp(a, b, 128);
    TEST_ASSERT_EQUAL_UINT8(lerp8(255, 0, 128), h.r);
    TEST_ASSERT_EQUAL_UINT8(lerp8(0, 255, 128), h.w);
}

static void test_ramp_interpolates_linearly(void) {
    Ramp r;
    r.start(0, 200, 1000, 400);
    TEST_ASSERT_EQUAL_UINT8(0, r.value(1000));
    TEST_ASSERT_EQUAL_UINT8(100, r.value(1200));
    TEST_ASSERT_EQUAL_UINT8(150, r.value(1300));
    TEST_ASSERT_TRUE(r.running(1300));
}

static void test_ramp_retires_at_end_and_holds_target(void) {
    Ramp r;
    r.start(200, 50, 0, 100);
    TEST_ASSERT_EQUAL_UINT8(50, r.value(100));
    TEST_ASSERT_FALSE(r.active);
    TEST_ASSERT_EQUAL_UINT8(50, r.value(5000));
    r.set(77);
    TEST_ASSERT_EQUAL_UINT8(77, r.value(6000));
    TEST_ASSERT_FALSE(r.running(6000));
}

static void test_ramp_survives_millis_wraparound(void) {
    Ramp r;
    const uint32_t t0 = 0xFFFFFF00u;
    r.start(0, 100, t0, 512);
    TEST_ASSERT_EQUAL_UINT8(50, r.value(t0 + 256));  // crosses 0
    TEST_ASSERT_EQUAL_UINT8(100, r.value(t0 + 512));
}

int main(void) {
    UNITY_BEGIN();
    RUN_TEST(test_lerp8_endpoints_and_midpoint);
    RUN_TEST(test_lerp_rgbw_per_channel);
    RUN_TEST(test_ramp_interpolates_linearly);
    RUN_TEST(test_ramp_retires_at_end_and_holds_target);
    RUN_TEST(test_ramp_survives_millis_wraparound);
    return UNITY_END();
}
```

- [ ] **Шаг 2: убедиться, что RED** — `$P test -e native -f test_ramp` → ошибка компиляции `Ramp.h: No such file`.

- [ ] **Шаг 3: реализация `Ramp` и `lerp`**

`firmware/lib/MirrorCore/src/Ramp.h`:

```cpp
// Ramp — linear interpolation of a uint8_t value over a time span, using
// (now - startMs) so it survives the 49.7-day millis() wraparound. value()
// retires the ramp (active = false) once the span has elapsed and holds `to`
// from then on, like Countdown::update() (Ruling R7).
#pragma once

#include <cstdint>

struct Ramp {
    uint8_t  from = 0, to = 0;
    uint32_t startMs = 0, durMs = 0;
    bool     active = false;

    void start(uint8_t f, uint8_t t, uint32_t now, uint32_t dur) {
        from = f; to = t; startMs = now; durMs = dur; active = (dur > 0 && f != t);
        if (!active) from = t;
    }
    void set(uint8_t v) { from = to = v; active = false; }

    uint8_t value(uint32_t now) {
        if (!active) return to;
        const uint32_t elapsed = (uint32_t)(now - startMs);
        if (elapsed >= durMs) { active = false; return to; }
        return static_cast<uint8_t>(from + (static_cast<int32_t>(to) - from) * static_cast<int32_t>(elapsed) /
                                              static_cast<int32_t>(durMs));
    }
    bool running(uint32_t now) const { return active && (uint32_t)(now - startMs) < durMs; }
};
```

В `ColorMath.h` после `scale`:

```cpp
// a + (b - a) * t / 255: lerp8(a, b, 0) == a, lerp8(a, b, 255) == b.
uint8_t lerp8(uint8_t a, uint8_t b, uint8_t t);

// lerp8 applied independently to each of r, g, b, w.
Rgbw lerp(Rgbw a, Rgbw b, uint8_t t);
```

В `ColorMath.cpp`:

```cpp
uint8_t lerp8(uint8_t a, uint8_t b, uint8_t t) {
    return static_cast<uint8_t>(a + (static_cast<int32_t>(b) - a) * t / 255);
}

Rgbw lerp(Rgbw a, Rgbw b, uint8_t t) {
    return Rgbw{lerp8(a.r, b.r, t), lerp8(a.g, b.g, t), lerp8(a.b, b.b, t), lerp8(a.w, b.w, t)};
}
```

- [ ] **Шаг 4: GREEN** — `$P test -e native -f test_ramp` → 5/5.

- [ ] **Шаг 5: тесты переходов в `Mirror` (RED)**

В `firmware/test/test_mirror/test_main.cpp` (перед `int main`; `#include "Ramp.h"` не нужен):

```cpp
// --- Transitions (v1.2.0): colour/brightness/mode changes from commands
// fade over cfg::TRANSITION_MS; button dimming stays immediate. -------------

static bool channelBetween(uint8_t v, uint8_t lo, uint8_t hi) { return v >= lo && v <= hi; }

static void test_color_command_transitions_over_500ms(void) {
    Mirror m(zeroRandom);
    uint32_t now = 0;
    m.begin(now);
    powerOnSettled(m, now);

    m.apply(lightColor(0, 0, 255), now);
    TEST_ASSERT_EQUAL_UINT8(0, m.snapshot().r);  // state reports the target at once
    run(m, now, cfg::TRANSITION_MS / 2);
    const Rgbw mid = m.frame()[0];
    TEST_ASSERT_TRUE_MESSAGE(channelBetween(mid.r, 110, 145), "red did not fade halfway at 250 ms");
    TEST_ASSERT_TRUE_MESSAGE(channelBetween(mid.b, 110, 145), "blue did not rise halfway at 250 ms");
    run(m, now, cfg::TRANSITION_MS / 2 + 50);
    TEST_ASSERT_TRUE(allPixelsEqual(m.frame(), Rgbw{0, 0, 255, 0}));
}

static void test_brightness_command_transitions(void) {
    Mirror m(zeroRandom);
    uint32_t now = 0;
    m.begin(now);
    powerOnSettled(m, now);

    m.apply(lightBrightness(55), now);
    TEST_ASSERT_EQUAL_UINT8(55, m.snapshot().brightness);
    run(m, now, cfg::TRANSITION_MS / 2);
    TEST_ASSERT_TRUE(channelBetween(m.frame()[0].r, scale8(255, 140), scale8(255, 170)));
    run(m, now, cfg::TRANSITION_MS / 2 + 50);
    TEST_ASSERT_TRUE(allPixelsEqual(m.frame(), scale(kSolidDefault, 55)));
}

static void test_makeup_toggle_transitions(void) {
    Mirror m(zeroRandom);
    uint32_t now = 0;
    m.begin(now);
    powerOnSettled(m, now);

    m.onButton(click(2), now);  // solid -> makeup
    run(m, now, cfg::TRANSITION_MS / 2);
    const Rgbw mid = m.frame()[0];
    TEST_ASSERT_TRUE(channelBetween(mid.r, 110, 145));
    TEST_ASSERT_TRUE(channelBetween(mid.w, 110, 145));
    run(m, now, cfg::TRANSITION_MS / 2 + 50);
    TEST_ASSERT_TRUE(allPixelsEqual(m.frame(), kMakeupColor));
}

static void test_hold_dimming_stays_immediate(void) {
    Mirror m(zeroRandom);
    uint32_t now = 0;
    m.begin(now);
    powerOnSettled(m, now);

    m.onButton(holdStart(), now);
    now += 30;
    m.onButton(holdTick(), now);
    m.tick(now);
    TEST_ASSERT_EQUAL_UINT8(cfg::DEFAULT_BRIGHTNESS - cfg::DIM_STEP, m.frame()[0].r);
    m.onButton(holdEnd(), now);
}

static void test_power_on_from_off_uses_new_colour_at_once(void) {
    Mirror m(zeroRandom);
    uint32_t now = 0;
    m.begin(now);
    m.apply(makeupCmd(true), now);  // from OFF: base = makeup and power on, no fade
    run(m, now, cfg::SLIDE_STEP_MS * 12);
    bool sawLit = false;
    for (uint16_t i = 0; i < Frame::kSize; ++i) {
        const Rgbw p = m.frame()[i];
        if (p.w > 0) sawLit = true;
        TEST_ASSERT_EQUAL_UINT8_MESSAGE(0, p.r, "slide-in painted the old solid colour");
    }
    TEST_ASSERT_TRUE(sawLit);
}
```

И в `main()`: `RUN_TEST` для пяти тестов. Обновить существующие тесты, которые проверяют кадр сразу после
команды (теперь нужно дождаться перехода): в `test_click2_toggles_base_when_on`, `test_color_switches_to_solid`,
`test_frame_brightness_applied`, `test_glitch_cancelled_by_color_change` заменить `run(m, now, 10);` перед
`allPixelsEqual` на `run(m, now, cfg::TRANSITION_MS + 50);`. В `test_glitch_cancelled_by_color_change` также
оставить проверку `glitchSeenUntil(..., blue)` после перехода. Если после запуска упадут другие тесты с тем же
симптомом (кадр проверяется до 500 мс после команды/клика) — тот же приём.

В `firmware/test/test_protocol/test_main.cpp` заменить оба `\"fw\":\"1.1.1\"` на `\"fw\":\"1.2.0\"`.

- [ ] **Шаг 6: убедиться, что RED** — `$P test -e native -f test_mirror -f test_protocol` → новые тесты и `fw` падают.

- [ ] **Шаг 7: реализация в `Mirror`**

`Config.h` — в блок `// --- Timers (ms)` добавить:

```cpp
// --- Transitions (v1.2.0) ---------------------------------------------------
// Colour/brightness/mode changes from commands fade linearly; button dimming
// is applied at once (it is already stepped every DIM_PERIOD_MS).
constexpr uint32_t TRANSITION_MS      = 500;
constexpr uint32_t TRANSITION_STEP_MS = 20;
```

и `FW_VERSION[] = "1.2.0"`.

`Mirror.h`: `#include "Ramp.h"`; приватные методы `Rgbw targetColor() const; void retarget(uint32_t now, bool smooth); void finishFrame();`;
поля после `holdLocked_`:

```cpp
    // Shown (rendered) base colour/brightness — follow the targets r_/g_/b_/
    // base_/brightness_ through a TRANSITION_MS ramp (v1.2.0).
    Rgbw     shownColor_{cfg::DEFAULT_R, cfg::DEFAULT_G, cfg::DEFAULT_B, 0};
    uint8_t  shownBrightness_ = cfg::DEFAULT_BRIGHTNESS;
    Rgbw     fromColor_{cfg::DEFAULT_R, cfg::DEFAULT_G, cfg::DEFAULT_B, 0};
    uint8_t  fromBrightness_ = cfg::DEFAULT_BRIGHTNESS;
    Ramp     trans_;
    uint32_t lastTransStepMs_ = 0;
```

`Mirror.cpp`:

```cpp
Rgbw Mirror::targetColor() const {
    return base_ == BaseMode::Makeup ? Rgbw{0, 0, 0, 255} : Rgbw{r_, g_, b_, 0};
}

Rgbw Mirror::baseColor() const { return shownColor_; }

// Called after any change of the targets. smooth=true fades from the shown
// values while lit; otherwise (or when OFF/SLIDE_OFF) the targets apply at once.
void Mirror::retarget(uint32_t now, bool smooth) {
    const Rgbw target = targetColor();
    const bool lit = (power_ == PowerState::On || power_ == PowerState::SlideOn);
    if (smooth && lit && (!(target == shownColor_) || brightness_ != shownBrightness_)) {
        fromColor_ = shownColor_;
        fromBrightness_ = shownBrightness_;
        trans_.start(0, 255, now, cfg::TRANSITION_MS);
        lastTransStepMs_ = now;
    } else {
        shownColor_ = target;
        shownBrightness_ = brightness_;
        trans_.set(255);
    }
    staticDirty_ = true;
}

// Every render ends here: brightness applied to the whole frame, frame flagged.
void Mirror::finishFrame() {
    frame_.scale(shownBrightness_);
    frameDirty_ = true;
}
```

Правки по месту:
- удалить старое `baseColor()` (с тернарником) — его логика переехала в `targetColor()`;
- `applyDefaults()`: в конец добавить `shownColor_ = targetColor(); shownBrightness_ = brightness_; trans_.set(255);`;
- `powerOn()`: перед `power_ = PowerState::SlideOn;` добавить `if (power_ == PowerState::Off) retarget(now, false);`
  (из OFF — новый цвет сразу; из SLIDE_OFF показанный цвет уже актуален);
- `apply(Light)`: после трёх блоков (`brightness`, `color`, `effect Solid/Makeup`) и **до** `powerOff/powerOn` заменить
  три `staticDirty_ = true;` на одно `retarget(now, true);` (вызывать только если что-то из трёх изменилось —
  завести `bool changed = false;` и ставить `true` в каждом блоке);
- `apply(Makeup)`: вместо `staticDirty_ = true;` — `retarget(now, true);` (при `powerOn` из OFF `retarget(now,false)`
  внутри `powerOn` уже применит цвет; поэтому в ветке `flag` вызвать `retarget` **после** `powerOn`, он увидит `lit` и
  `target == shownColor_` → просто пометит `staticDirty_`);
- `onButton` `Click(2)` при включённом: вместо `staticDirty_ = true;` — `retarget(now, true);`;
- `onButton` `HoldTick`: вместо `staticDirty_ = true;` — `retarget(now, false);`;
- `tick()`: сразу после `gate_.tick(now);` добавить

```cpp
    if (trans_.active && (uint32_t)(now - lastTransStepMs_) >= cfg::TRANSITION_STEP_MS) {
        lastTransStepMs_ = now;
        const uint8_t t = trans_.value(now);  // retires itself at 255
        shownColor_ = lerp(fromColor_, targetColor(), t);
        shownBrightness_ = lerp8(fromBrightness_, brightness_, t);
        staticDirty_ = true;
    }
```

- все четыре места `frame_.scale(brightness_); frameDirty_ = true;` (slide, effect, static fill, `tickGlitch` ×2) заменить
  на `finishFrame();`.

- [ ] **Шаг 8: GREEN** — `$P test -e native` → все тесты зелёные (ожидается 147 + 10 новых = 157).
  Обе сборки `$P run -e esp32-s3-zero`, `-e esp32-s3-zero-debug` — без предупреждений в наших файлах.

- [ ] **Шаг 9: документация** — `ARCHITECTURE.md`: в §4.2 после таблицы абзац «Переходы (v1.2.0)» (текст из
  строки 6 таблицы «Дизайн»), в §8.1 упомянуть `Ramp.h`; `README.md`: в «Возможности» пункт «Плавные переходы цвета и
  яркости (0,5 с) при командах из HA/Алисы, переключении Макияжа и двойном клике; диммирование кнопкой — как прежде».

- [ ] **Шаг 10: коммит и пауза**

```bash
git add firmware/lib/MirrorCore/src/Ramp.h firmware/lib/MirrorCore/src/ColorMath.h firmware/lib/MirrorCore/src/ColorMath.cpp \
  firmware/lib/MirrorCore/src/Config.h firmware/lib/MirrorCore/src/Mirror.h firmware/lib/MirrorCore/src/Mirror.cpp \
  firmware/test/test_ramp/test_main.cpp firmware/test/test_mirror/test_main.cpp firmware/test/test_protocol/test_main.cpp \
  README.md ARCHITECTURE.md
git commit -m "feat: плавные переходы цвета и яркости (v1.2.0, п.6)

Изменение цвета, яркости или режима из команды HA/Алисы, переключателя
Макияжа или двойного клика теперь переходит плавно за 500 мс (шаг 20 мс).
Диммирование удержанием кнопки — мгновенное. Включение из OFF — новый цвет
сразу. Эффекты видят текущий переходный цвет; state отдаёт цель сразу.
Новый примитив Ramp (интерполяция по времени, переживает переполнение
millis) и lerp8/lerp в ColorMath. Версия прошивки 1.2.0.

Co-Authored-By: Claude Fable 5.1 <noreply@anthropic.com>"
```

**ПАУЗА — ждать «продолжай».**

---

### Задача 2: затухание за минуту до автовыключения (пункт 9)

**Файлы:**
- Изменить: `Config.h`, `Mirror.h`, `Mirror.cpp`, `firmware/test/test_mirror/test_main.cpp`, `README.md`, `ARCHITECTURE.md`

**Интерфейсы:**
- Потребляет: `Ramp`, `finishFrame()` из Задачи 1.
- Производит: константы `cfg::AUTO_OFF_WARN_MS = 60000`, `cfg::WARN_DIM_LEVEL = 128`, `cfg::WARN_FADE_IN_MS = 2000`,
  `cfg::WARN_FADE_OUT_MS = 1000`; в `Mirror`: `uint32_t autoOffLimit() const` (пока всегда `AUTO_OFF_MS`; Задача 3
  сделает его зависимым от режима), поля `bool warning_`, `Ramp warn_`, `uint8_t warnLevel_`, `uint32_t lastWarnStepMs_`;
  `finishFrame()` теперь масштабирует на `scale8(shownBrightness_, warnLevel_)`.

- [ ] **Шаг 1: тесты (RED)**

```cpp
// --- Pre-auto-off warning (v1.2.0): a minute before auto-off the rendered
// brightness fades to 50 %; any activity restores it and restarts the timer.

static void test_warning_dims_to_half_one_minute_before_auto_off(void) {
    Mirror m(zeroRandom);
    uint32_t now = 0;
    m.begin(now);
    powerOnSettled(m, now);  // activity at the click (t=0)

    run(m, now, cfg::AUTO_OFF_MS - cfg::AUTO_OFF_WARN_MS - 10 - now);
    TEST_ASSERT_TRUE_MESSAGE(allPixelsEqual(m.frame(), kSolidDefault), "dimmed too early");
    run(m, now, 10 + cfg::WARN_FADE_IN_MS + 100);
    TEST_ASSERT_TRUE_MESSAGE(allPixelsEqual(m.frame(), scale(kSolidDefault, cfg::WARN_DIM_LEVEL)),
                              "not dimmed to 50 % two seconds into the warning");
    TEST_ASSERT_EQUAL_UINT8(cfg::DEFAULT_BRIGHTNESS, m.snapshot().brightness);  // HA setting untouched
    TEST_ASSERT_TRUE(PowerState::On == m.power());
}

static void test_activity_during_warning_restores_and_postpones(void) {
    Mirror m(zeroRandom);
    uint32_t now = 0;
    m.begin(now);
    powerOnSettled(m, now);
    run(m, now, cfg::AUTO_OFF_MS - cfg::AUTO_OFF_WARN_MS + 5000 - now);
    TEST_ASSERT_FALSE(allPixelsEqual(m.frame(), kSolidDefault));  // warning running

    const uint32_t pirAt = now;
    m.onPir(true, now);
    m.onPir(false, now);
    run(m, now, cfg::WARN_FADE_OUT_MS + 100);
    TEST_ASSERT_TRUE_MESSAGE(allPixelsEqual(m.frame(), kSolidDefault), "brightness not restored after activity");

    run(m, now, cfg::AUTO_OFF_MS - cfg::AUTO_OFF_WARN_MS - 5000);  // well past the old auto-off moment
    TEST_ASSERT_TRUE_MESSAGE(PowerState::On == m.power(), "auto-off timer was not restarted");
    TEST_ASSERT_TRUE(allPixelsEqual(m.frame(), kSolidDefault));
    (void)pirAt;
}

static void test_no_warning_when_automation_off(void) {
    Mirror m(zeroRandom);
    uint32_t now = 0;
    m.begin(now);
    powerOnSettled(m, now);
    m.apply(automationCmd(false), now);
    run(m, now, cfg::AUTO_OFF_MS + 60000);
    TEST_ASSERT_TRUE(PowerState::On == m.power());
    TEST_ASSERT_TRUE(allPixelsEqual(m.frame(), kSolidDefault));
}

static void test_warning_scales_a_running_effect(void) {
    Mirror m(zeroRandom);
    uint32_t now = 0;
    m.begin(now);
    powerOnSettled(m, now);
    run(m, now, cfg::AUTO_OFF_MS - cfg::AUTO_OFF_WARN_MS + cfg::WARN_FADE_IN_MS + 500 - now);
    m.apply(randomEffectCmd(), now);  // zeroRandom: dark snake, head at 0 moving +1
    run(m, now, cfg::SNAKE_STEP_MS + 5);
    // Pixel 100 is >= 60 LEDs behind the head for the first ~40 steps -> plain base, dimmed.
    TEST_ASSERT_TRUE(scale(kSolidDefault, cfg::WARN_DIM_LEVEL) == m.frame()[100]);
}
```

`RUN_TEST` ×4.

- [ ] **Шаг 2: убедиться, что RED** — `$P test -e native -f test_mirror`: 4 падения (кадр не притушен).

- [ ] **Шаг 3: реализация**

`Config.h` рядом с `AUTO_OFF_MS`:

```cpp
// --- Pre-auto-off warning (v1.2.0) ----------------------------------------
// AUTO_OFF_WARN_MS before auto-off the rendered brightness ramps to
// WARN_DIM_LEVEL (50 %) over WARN_FADE_IN_MS; activity ramps it back over
// WARN_FADE_OUT_MS and restarts the timer.
constexpr uint32_t AUTO_OFF_WARN_MS = 60UL * 1000;
constexpr uint8_t  WARN_DIM_LEVEL   = 128;
constexpr uint32_t WARN_FADE_IN_MS  = 2000;
constexpr uint32_t WARN_FADE_OUT_MS = 1000;
```

`Mirror.h`: метод `uint32_t autoOffLimit() const;` и поля

```cpp
    bool     warning_       = false;  // inside the last AUTO_OFF_WARN_MS before auto-off
    Ramp     warn_;
    uint8_t  warnLevel_     = 255;    // render multiplier (255 = no warning)
    uint32_t lastWarnStepMs_ = 0;
```

`Mirror.cpp`:

```cpp
uint32_t Mirror::autoOffLimit() const { return cfg::AUTO_OFF_MS; }

void Mirror::markActivity(uint32_t now) {
    lastActivity_ = lastIdle_ = now;
    if (warning_) {
        warning_ = false;
        warn_.start(warn_.value(now), 255, now, cfg::WARN_FADE_OUT_MS);
        lastWarnStepMs_ = now;
    }
}

void Mirror::finishFrame() {
    frame_.scale(scale8(shownBrightness_, warnLevel_));
    frameDirty_ = true;
}
```

В `applyDefaults()` добавить `warning_ = false; warn_.set(255); warnLevel_ = 255;`.
В `tick()` блок автоматики заменить на:

```cpp
    if (gate_.automationActive() && power_ == PowerState::On) {
        const uint32_t idle = (uint32_t)(now - lastActivity_);
        const uint32_t limit = autoOffLimit();
        if (idle > limit) {
            MLOG("[%lu] AUTO-OFF (idle %lu ms)\n", (unsigned long)now, (unsigned long)idle);
            powerOff(false, now);
        } else {
            if (!warning_ && idle > limit - cfg::AUTO_OFF_WARN_MS) {
                warning_ = true;
                warn_.start(warnLevel_, cfg::WARN_DIM_LEVEL, now, cfg::WARN_FADE_IN_MS);
                lastWarnStepMs_ = now;
                MLOG("[%lu] AUTO-OFF WARNING (dim to 50%%)\n", (unsigned long)now);
            }
            if (effect_ == EffectId::None && base_ == BaseMode::Solid &&
                (uint32_t)(now - lastIdle_) > nextAutoEffectMs_) {
                startRandomEffect(now);
            }
        }
    }
    if (warn_.active && (uint32_t)(now - lastWarnStepMs_) >= cfg::TRANSITION_STEP_MS) {
        lastWarnStepMs_ = now;
        warnLevel_ = warn_.value(now);
        staticDirty_ = true;
    }
```

(Внимание: `warnLevel_` обновляется только пока `warn_.active`; когда ramp закончился, `value()` уже вернул конечное
значение на последнем шаге — но последний шаг мог не совпасть с концом. Поэтому после `if` добавить
`if (!warn_.active) warnLevel_ = warn_.to;` — гарантирует точные 128/255.)

- [ ] **Шаг 4: GREEN** — `$P test -e native` (все), обе сборки.

- [ ] **Шаг 5: документация** — `ARCHITECTURE.md` §4.4: пункт «Предупреждение перед автовыключением (v1.2.0)»;
  `README.md` «Возможности»: «За минуту до автовыключения свет плавно притухает до 50 % — махни рукой, и он вернётся,
  а таймер начнётся заново».

- [ ] **Шаг 6: коммит и пауза**

```bash
git add firmware/lib/MirrorCore/src/Config.h firmware/lib/MirrorCore/src/Mirror.h firmware/lib/MirrorCore/src/Mirror.cpp \
  firmware/test/test_mirror/test_main.cpp README.md ARCHITECTURE.md
git commit -m "feat: затухание за минуту до автовыключения (п.9)

За 60 с до автовыключения яркость плавно (2 с) снижается до 50 %. Любая
активность (PIR, кнопка, команда) возвращает полную яркость за 1 с и
запускает таймер заново. Действует и во время эффектов; только при
включённой автоматике. Настройка brightness в HA не меняется.

Co-Authored-By: Claude Fable 5.1 <noreply@anthropic.com>"
```

**ПАУЗА — ждать «продолжай».**

---

### Задача 3: 45 минут до автовыключения в режиме Макияж (пункт 8)

**Файлы:** `Config.h`, `Mirror.cpp`, `firmware/test/test_mirror/test_main.cpp`, `README.md`, `ARCHITECTURE.md`

**Интерфейсы:** `cfg::AUTO_OFF_MAKEUP_MS = 45 * 60 * 1000`; `autoOffLimit()` возвращает его при `base_ == Makeup`;
любое изменение `base_` вызывает `markActivity(now)`.

- [ ] **Шаг 1: тесты (RED)**

```cpp
// --- Makeup keeps the light for 45 min (v1.2.0) ------------------------------

static void test_makeup_auto_off_after_45_minutes(void) {
    Mirror m(zeroRandom);
    uint32_t now = 0;
    m.begin(now);
    powerOnSettled(m, now);
    m.apply(makeupCmd(true), now);
    run(m, now, cfg::AUTO_OFF_MS + 5UL * 60 * 1000);          // 20 min: solid would be off by now
    TEST_ASSERT_TRUE_MESSAGE(PowerState::On == m.power(), "makeup switched off before 45 min");
    run(m, now, cfg::AUTO_OFF_MAKEUP_MS - (cfg::AUTO_OFF_MS + 5UL * 60 * 1000) - 60000);
    TEST_ASSERT_TRUE(PowerState::On == m.power());            // 44 min
    run(m, now, 60000 + 100 + kSlideMs);
    TEST_ASSERT_TRUE_MESSAGE(PowerState::Off == m.power(), "makeup did not auto-off after 45 min");
}

static void test_makeup_warning_at_44_minutes(void) {
    Mirror m(zeroRandom);
    uint32_t now = 0;
    m.begin(now);
    powerOnSettled(m, now);
    m.apply(makeupCmd(true), now);
    run(m, now, cfg::AUTO_OFF_MAKEUP_MS - cfg::AUTO_OFF_WARN_MS - 10 - now);
    TEST_ASSERT_TRUE(allPixelsEqual(m.frame(), kMakeupColor));
    run(m, now, 10 + cfg::WARN_FADE_IN_MS + 100);
    TEST_ASSERT_TRUE(allPixelsEqual(m.frame(), scale(kMakeupColor, cfg::WARN_DIM_LEVEL)));
}

static void test_leaving_makeup_restarts_the_idle_timer(void) {
    Mirror m(zeroRandom);
    uint32_t now = 0;
    m.begin(now);
    powerOnSettled(m, now);
    m.apply(makeupCmd(true), now);
    run(m, now, 30UL * 60 * 1000);                              // 30 min idle in makeup
    m.apply(makeupCmd(false), now);                             // back to solid (15 min limit)
    run(m, now, cfg::AUTO_OFF_MS - 60000);
    TEST_ASSERT_TRUE_MESSAGE(PowerState::On == m.power(), "mode change did not count as activity");
    run(m, now, 60000 + 100 + kSlideMs);
    TEST_ASSERT_TRUE(PowerState::Off == m.power());
}
```

- [ ] **Шаг 2: RED** — первый и третий тесты падают (выключается через 15 мин / сразу).

- [ ] **Шаг 3: реализация** — `Config.h`: `constexpr uint32_t AUTO_OFF_MAKEUP_MS = 45UL * 60 * 1000;  // 45 min in makeup`
  под `AUTO_OFF_MS`. `Mirror.cpp`: `uint32_t Mirror::autoOffLimit() const { return base_ == BaseMode::Makeup ? cfg::AUTO_OFF_MAKEUP_MS : cfg::AUTO_OFF_MS; }`.
  В `apply(Light)` (ветки `effect Solid/Makeup` и `color` — там, где `base_` присваивается), `apply(Makeup)` и
  `onButton Click(2)` — если `base_` реально изменился, вызвать `markActivity(now);` (в `Click(2)` `onButton` уже
  вызывает `markActivity` в начале — там ничего не добавлять).

- [ ] **Шаг 4: GREEN** — все тесты, обе сборки.

- [ ] **Шаг 5: документация** — `ARCHITECTURE.md` §4.4 «Автовыключение: 15 мин в solid, **45 мин в Макияже**;
  смена режима — активность»; `README.md` «Возможности» и таблица кнопки/таймеров.

- [ ] **Шаг 6: коммит и пауза**

```bash
git add firmware/lib/MirrorCore/src/Config.h firmware/lib/MirrorCore/src/Mirror.cpp \
  firmware/test/test_mirror/test_main.cpp README.md ARCHITECTURE.md
git commit -m "feat: в режиме Макияж свет держится 45 минут (п.8)

Таймер автовыключения в Макияже — 45 мин вместо 15 (предупреждение за
минуту до него). Смена режима solid <-> makeup считается активностью,
чтобы переход в solid после долгого Макияжа не гасил свет мгновенно.

Co-Authored-By: Claude Fable 5.1 <noreply@anthropic.com>"
```

**ПАУЗА — ждать «продолжай».**

---

### Задача 4: эффект `breathe` — «дыхание» (пункт 1)

**Файлы:**
- Создать: `firmware/lib/MirrorCore/src/effects/Breathe.h`, `Breathe.cpp`
- Изменить: `Config.h`, `Types.h`, `effects/EffectRegistry.cpp`, `firmware/test/test_effects/test_main.cpp`,
  `firmware/test/test_protocol/test_main.cpp`, `ha_mirror.yaml`, `README.md`, `ARCHITECTURE.md`

**Интерфейсы:**
- Производит: `class Breathe : public Effect`, `EffectId::Breathe`, имя `"breathe"`,
  `cfg::BREATHE_STEP_MS = 20`, `cfg::BREATHE_CYCLE_STEPS = 200`, `cfg::BREATHE_CYCLES = 3`, `cfg::BREATHE_MIN_LEVEL = 153`.
- Правило реестра (§7): новый эффект = класс + строка `kEffects[]` + значение `EffectId` + имя в `effect_list`.

- [ ] **Шаг 1: тесты (RED)** — в `firmware/test/test_effects/test_main.cpp` добавить `#include "effects/Breathe.h"` и:

```cpp
// --- Breathe (v1.2.0): whole ring, cosine 100 % -> 60 % -> 100 %, 3 cycles ---

static bool ringUniform(const Frame& f) {
    for (uint16_t i = 1; i < Frame::kSize; ++i) {
        if (!(f[i] == f[0])) return false;
    }
    return true;
}

static void test_breathe_finishes_after_600_steps(void) {
    Breathe fx;
    Frame f;
    EffectContext ctx{kSolid, zeroRandom};
    fx.begin(ctx);
    TEST_ASSERT_EQUAL_UINT16(cfg::BREATHE_STEP_MS, fx.stepIntervalMs());
    int calls = 0;
    while (fx.step(f, ctx)) {
        ++calls;
        TEST_ASSERT_TRUE_MESSAGE(calls < 1000, "breathe did not finish");
    }
    TEST_ASSERT_EQUAL_INT(cfg::BREATHE_CYCLE_STEPS * cfg::BREATHE_CYCLES, calls + 1);
}

static void test_breathe_starts_full_and_dips_to_60_percent_at_half_cycle(void) {
    Breathe fx;
    Frame f;
    EffectContext ctx{kSolid, zeroRandom};
    fx.begin(ctx);
    fx.step(f, ctx);  // step 0
    TEST_ASSERT_TRUE(ringUniform(f));
    TEST_ASSERT_TRUE(kSolid == f[0]);
    for (int i = 0; i < cfg::BREATHE_CYCLE_STEPS / 2; ++i) fx.step(f, ctx);  // renders step 100
    TEST_ASSERT_TRUE(scale(kSolid, cfg::BREATHE_MIN_LEVEL) == f[0]);
    for (int i = 0; i < cfg::BREATHE_CYCLE_STEPS / 2; ++i) fx.step(f, ctx);  // renders step 200: full again
    TEST_ASSERT_TRUE(kSolid == f[0]);
}

static void test_breathe_never_below_60_percent(void) {
    Breathe fx;
    Frame f;
    EffectContext ctx{kMakeup, zeroRandom};
    fx.begin(ctx);
    const uint8_t floorW = scale8(255, cfg::BREATHE_MIN_LEVEL);
    while (fx.step(f, ctx)) {
        TEST_ASSERT_TRUE(f[0].w >= floorW);
        TEST_ASSERT_EQUAL_UINT8(0, f[0].r);
    }
}
```

В `test_registry_names_roundtrip` расширить массивы: `ids[] = {Dark, Rainbow, Wave, Breathe}`,
`expectedNames[] = {"dark","rainbow","wave","breathe"}`, цикл до 4. В `test_random_effect_covers_all` —
`cyclingRandom` уже берёт `% bound`, менять его не надо; поднять число итераций цикла с 3 до **4** (число записей
реестра) и добавить флаг `sawBreathe` с проверкой. `RUN_TEST` ×3. В `test_protocol` `test_light_effect_names` добавить блок
`{"effect": "breathe"}` → `Temporary` + `EffectId::Breathe`.

- [ ] **Шаг 2: RED** — ошибка компиляции `effects/Breathe.h`.

- [ ] **Шаг 3: реализация**

`Config.h` (после блока Wave):

```cpp
// --- Breathe effect (v1.2.0) -------------------------------------------------
// Whole ring, cosine brightness 100 % -> BREATHE_MIN_LEVEL -> 100 %,
// BREATHE_CYCLES cycles of BREATHE_CYCLE_STEPS steps.
constexpr uint32_t BREATHE_STEP_MS     = 20;
constexpr uint16_t BREATHE_CYCLE_STEPS = 200;  // 4 s
constexpr uint8_t  BREATHE_CYCLES      = 3;
constexpr uint8_t  BREATHE_MIN_LEVEL   = 153;  // 60 %
```

`Types.h`: `enum class EffectId : uint8_t { None = 0, Dark, Rainbow, Wave, Breathe };`

`effects/Breathe.h`:

```cpp
// Breathe (v1.2.0): the whole ring slowly dims to 60 % and back, three times.
#pragma once

#include <cstdint>

#include "Effect.h"

class Breathe : public Effect {
public:
    void begin(const EffectContext& ctx) override;
    uint16_t stepIntervalMs() const override;
    bool step(Frame& out, const EffectContext& ctx) override;

private:
    uint16_t step_ = 0;
};
```

`effects/Breathe.cpp`:

```cpp
#include "Breathe.h"

#include <cmath>

#include "../ColorMath.h"
#include "../Config.h"
#include "../Frame.h"

namespace {
constexpr uint16_t kTotalSteps = cfg::BREATHE_CYCLE_STEPS * cfg::BREATHE_CYCLES;
constexpr float kTwoPi = 6.28318530718f;
}  // namespace

void Breathe::begin(const EffectContext&) { step_ = 0; }

uint16_t Breathe::stepIntervalMs() const { return static_cast<uint16_t>(cfg::BREATHE_STEP_MS); }

bool Breathe::step(Frame& out, const EffectContext& ctx) {
    const float phase = kTwoPi * static_cast<float>(step_ % cfg::BREATHE_CYCLE_STEPS) /
                        static_cast<float>(cfg::BREATHE_CYCLE_STEPS);
    const float k = (1.0f + std::cos(phase)) * 0.5f;  // 1 at the cycle start, 0 halfway
    const uint8_t level = static_cast<uint8_t>(cfg::BREATHE_MIN_LEVEL + (255 - cfg::BREATHE_MIN_LEVEL) * k + 0.5f);
    out.fill(scale(ctx.base, level));
    ++step_;
    return step_ < kTotalSteps;
}
```

`EffectRegistry.cpp`: `#include "Breathe.h"`, `Breathe s_breathe;`, строка `{EffectId::Breathe, "breathe", &s_breathe},`.

`ha_mirror.yaml`: в `effect_list` добавить `- breathe`.

- [ ] **Шаг 4: GREEN** — `$P test -e native`, обе сборки.

- [ ] **Шаг 5: документация** — `ARCHITECTURE.md` §4.2 таблица эффектов: строка `breathe`; `README.md`: «4 временных
  эффекта» → перечислить; `effect_list` в описании MQTT.

- [ ] **Шаг 6: коммит и пауза**

```bash
git add firmware/lib/MirrorCore/src/effects/Breathe.h firmware/lib/MirrorCore/src/effects/Breathe.cpp \
  firmware/lib/MirrorCore/src/effects/EffectRegistry.cpp firmware/lib/MirrorCore/src/Config.h firmware/lib/MirrorCore/src/Types.h \
  firmware/test/test_effects/test_main.cpp firmware/test/test_protocol/test_main.cpp ha_mirror.yaml README.md ARCHITECTURE.md
git commit -m "feat: эффект breathe — «дыхание» (п.1)

Всё кольцо плавно (по косинусу) притухает до 60 % и возвращается, три
цикла по 4 с. Временный эффект: в реестре, в effect_list и в random.

Co-Authored-By: Claude Fable 5.1 <noreply@anthropic.com>"
```

**ПАУЗА — ждать «продолжай».**

---

### Задача 5: эффект `embers` — «угли» (пункт 2)

**Файлы:** создать `effects/Embers.{h,cpp}`; изменить `Config.h`, `Types.h`, `EffectRegistry.cpp`,
`test_effects`, `test_protocol`, `ha_mirror.yaml`, `README.md`, `ARCHITECTURE.md`.

**Интерфейсы:** `class Embers : public Effect`, `EffectId::Embers`, `"embers"`,
`cfg::EMBERS_STEP_MS = 60`, `cfg::EMBERS_STEPS = 333`, `cfg::EMBERS_FADE_STEPS = 33`, `cfg::EMBERS_CHANGES_PER_STEP = 13`,
`cfg::EMBERS_MIN_LEVEL = 102`, `cfg::EMBERS_SLEW = 6`.

- [ ] **Шаг 1: тесты (RED)**

```cpp
// --- Embers (v1.2.0): per-pixel smouldering 40..100 %, ~20 s -----------------

// rnd(TOTAL_LEDS) walks 0,1,2,... so every pixel gets a target eventually;
// rnd(level range) is always 0 -> target = EMBERS_MIN_LEVEL.
static uint32_t s_emberIdx = 0;
static uint32_t emberRandom(uint32_t bound) {
    if (bound == cfg::TOTAL_LEDS) return (s_emberIdx++) % cfg::TOTAL_LEDS;
    return 0;
}

static void test_embers_finishes_after_333_steps_and_starts_on_base(void) {
    Embers fx;
    Frame f;
    EffectContext ctx{kSolid, zeroRandom};
    fx.begin(ctx);
    TEST_ASSERT_EQUAL_UINT16(cfg::EMBERS_STEP_MS, fx.stepIntervalMs());
    TEST_ASSERT_TRUE(fx.step(f, ctx));                       // step 0: alpha 0 -> plain base
    for (uint16_t i = 0; i < Frame::kSize; ++i) TEST_ASSERT_TRUE(kSolid == f[i]);
    int calls = 1;
    while (fx.step(f, ctx)) {
        ++calls;
        TEST_ASSERT_TRUE_MESSAGE(calls < 1000, "embers did not finish");
    }
    TEST_ASSERT_EQUAL_INT(cfg::EMBERS_STEPS, calls + 1);
}

static void test_embers_pixel_slews_toward_its_target(void) {
    Embers fx;
    Frame f;
    EffectContext ctx{kSolid, zeroRandom};  // only pixel 0 ever gets a target (102)
    fx.begin(ctx);
    for (int i = 0; i <= cfg::EMBERS_FADE_STEPS; ++i) fx.step(f, ctx);  // full alpha from here
    uint8_t prev = f[0].r;
    for (int i = 0; i < 40; ++i) {
        fx.step(f, ctx);
        TEST_ASSERT_TRUE_MESSAGE(f[0].r <= prev && prev - f[0].r <= cfg::EMBERS_SLEW,
                                  "pixel 0 did not move down smoothly (<= EMBERS_SLEW per step)");
        prev = f[0].r;
        TEST_ASSERT_TRUE(kSolid == f[1]);  // untouched pixels stay base
    }
    TEST_ASSERT_TRUE(scale(kSolid, cfg::EMBERS_MIN_LEVEL) == f[0]);  // reached 40 %
}

static void test_embers_levels_stay_within_40_and_100_percent(void) {
    s_emberIdx = 0;
    Embers fx;
    Frame f;
    EffectContext ctx{kMakeup, emberRandom};
    fx.begin(ctx);
    const uint8_t floorW = scale8(255, cfg::EMBERS_MIN_LEVEL);
    while (fx.step(f, ctx)) {
        for (uint16_t i = 0; i < Frame::kSize; ++i) {
            TEST_ASSERT_TRUE(f[i].w >= floorW && f[i].w <= 255);
        }
    }
}
```

Реестр/протокол: `Embers` в `ids`/`expectedNames`, `sawEmbers`, `% 5`; `{"effect": "embers"}` в `test_light_effect_names`.

- [ ] **Шаг 2: RED.**

- [ ] **Шаг 3: реализация**

`Config.h`:

```cpp
// --- Embers effect (v1.2.0) --------------------------------------------------
// Each pixel smoulders at its own level in [EMBERS_MIN_LEVEL, 255]; every
// step EMBERS_CHANGES_PER_STEP random pixels get a new target and all move
// toward theirs by at most EMBERS_SLEW. ~20 s with a 2 s fade in/out.
constexpr uint32_t EMBERS_STEP_MS          = 60;
constexpr uint16_t EMBERS_STEPS            = 333;
constexpr uint16_t EMBERS_FADE_STEPS       = 33;
constexpr uint8_t  EMBERS_CHANGES_PER_STEP = 13;
constexpr uint8_t  EMBERS_MIN_LEVEL        = 102;  // 40 %
constexpr uint8_t  EMBERS_SLEW             = 6;
```

`Types.h`: `..., Breathe, Embers };`

`effects/Embers.h`:

```cpp
// Embers (v1.2.0): the ring smoulders — each pixel drifts between 40 % and
// 100 % of the base colour at its own pace.
#pragma once

#include <cstdint>

#include "../Config.h"
#include "Effect.h"

class Embers : public Effect {
public:
    void begin(const EffectContext& ctx) override;
    uint16_t stepIntervalMs() const override;
    bool step(Frame& out, const EffectContext& ctx) override;

private:
    uint16_t step_ = 0;
    uint8_t  level_[cfg::TOTAL_LEDS];
    uint8_t  target_[cfg::TOTAL_LEDS];
};
```

`effects/Embers.cpp`:

```cpp
#include "Embers.h"

#include "../ColorMath.h"
#include "../Frame.h"

namespace {
// Fade-in/out weight of the effect for this step, 0..255.
uint8_t fadeAlpha(uint16_t step, uint16_t total, uint16_t fade) {
    if (step < fade) return static_cast<uint8_t>(step * 255 / fade);
    if (step > total - fade) return static_cast<uint8_t>((total - step) * 255 / fade);
    return 255;
}
}  // namespace

void Embers::begin(const EffectContext&) {
    step_ = 0;
    for (uint16_t i = 0; i < cfg::TOTAL_LEDS; ++i) level_[i] = target_[i] = 255;
}

uint16_t Embers::stepIntervalMs() const { return static_cast<uint16_t>(cfg::EMBERS_STEP_MS); }

bool Embers::step(Frame& out, const EffectContext& ctx) {
    const uint8_t alpha = fadeAlpha(step_, cfg::EMBERS_STEPS, cfg::EMBERS_FADE_STEPS);

    for (uint8_t n = 0; n < cfg::EMBERS_CHANGES_PER_STEP; ++n) {
        const uint16_t i = static_cast<uint16_t>(ctx.random(cfg::TOTAL_LEDS));
        target_[i] = static_cast<uint8_t>(cfg::EMBERS_MIN_LEVEL + ctx.random(255 - cfg::EMBERS_MIN_LEVEL + 1));
    }
    for (uint16_t i = 0; i < cfg::TOTAL_LEDS; ++i) {
        if (level_[i] < target_[i]) level_[i] = static_cast<uint8_t>(level_[i] + ((target_[i] - level_[i] < cfg::EMBERS_SLEW) ? (target_[i] - level_[i]) : cfg::EMBERS_SLEW));
        else if (level_[i] > target_[i]) level_[i] = static_cast<uint8_t>(level_[i] - ((level_[i] - target_[i] < cfg::EMBERS_SLEW) ? (level_[i] - target_[i]) : cfg::EMBERS_SLEW));
        out[i] = scale(ctx.base, lerp8(255, level_[i], alpha));
    }
    ++step_;
    return step_ < cfg::EMBERS_STEPS;
}
```

Реестр: `Embers s_embers;`, `{EffectId::Embers, "embers", &s_embers},`. `ha_mirror.yaml`: `- embers`.

- [ ] **Шаг 4: GREEN** — все тесты, обе сборки (RAM +336 Б статически — ожидаемо, зафиксировать в отчёте).

- [ ] **Шаг 5: документация** — таблица эффектов в `ARCHITECTURE.md` §4.2, README.

- [ ] **Шаг 6: коммит и пауза**

```bash
git add firmware/lib/MirrorCore/src/effects/Embers.h firmware/lib/MirrorCore/src/effects/Embers.cpp \
  firmware/lib/MirrorCore/src/effects/EffectRegistry.cpp firmware/lib/MirrorCore/src/Config.h firmware/lib/MirrorCore/src/Types.h \
  firmware/test/test_effects/test_main.cpp firmware/test/test_protocol/test_main.cpp ha_mirror.yaml README.md ARCHITECTURE.md
git commit -m "feat: эффект embers — «угли» (п.2)

Каждый светодиод тлеет на своём уровне 40–100 % своего цвета: каждые 60 мс
13 случайных получают новую цель и все плавно к ней движутся; ~20 с с
плавным входом и выходом по 2 с. В реестре, effect_list и random.

Co-Authored-By: Claude Fable 5.1 <noreply@anthropic.com>"
```

**ПАУЗА — ждать «продолжай».**

---

### Задача 6: эффект `candle` — «свеча» (пункт 3)

**Файлы:** создать `effects/Candle.{h,cpp}`; изменить `Config.h`, `Types.h`, `EffectRegistry.cpp`, `test_effects`,
`test_protocol`, `ha_mirror.yaml`, `README.md`, `ARCHITECTURE.md`.

**Интерфейсы:** `class Candle : public Effect`, `EffectId::Candle`, `"candle"`,
`cfg::CANDLE_STEP_MS = 40`, `cfg::CANDLE_STEPS = 500`, `cfg::CANDLE_FADE_STEPS = 25`, `cfg::CANDLE_MIN_LEVEL = 227`,
`cfg::CANDLE_DIP_LEVEL = 204`, `cfg::CANDLE_DIP_CHANCE = 20`, `cfg::CANDLE_SLEW = 8`, `cfg::CANDLE_RETARGET_STEPS = 3`.

- [ ] **Шаг 1: тесты (RED)**

```cpp
// --- Candle (v1.2.0): the whole ring trembles 89..100 %, rare dips to 80 % ---

static void test_candle_finishes_after_500_steps_on_base(void) {
    Candle fx;
    Frame f;
    EffectContext ctx{kSolid, zeroRandom};
    fx.begin(ctx);
    TEST_ASSERT_EQUAL_UINT16(cfg::CANDLE_STEP_MS, fx.stepIntervalMs());
    TEST_ASSERT_TRUE(fx.step(f, ctx));
    TEST_ASSERT_TRUE(kSolid == f[0]);  // alpha 0 at step 0
    int calls = 1;
    while (fx.step(f, ctx)) ++calls;
    TEST_ASSERT_EQUAL_INT(cfg::CANDLE_STEPS, calls + 1);
}

// zeroRandom: rnd(CANDLE_DIP_CHANCE) == 0 -> every retarget is a dip to
// CANDLE_DIP_LEVEL, so the ring settles at 80 % and stays there.
static void test_candle_dips_smoothly_and_uniformly(void) {
    Candle fx;
    Frame f;
    EffectContext ctx{kSolid, zeroRandom};
    fx.begin(ctx);
    for (int i = 0; i <= cfg::CANDLE_FADE_STEPS; ++i) fx.step(f, ctx);  // full alpha
    uint8_t prev = f[0].r;
    for (int i = 0; i < 20; ++i) {
        fx.step(f, ctx);
        TEST_ASSERT_TRUE(ringUniform(f));
        TEST_ASSERT_TRUE_MESSAGE(f[0].r <= prev && prev - f[0].r <= cfg::CANDLE_SLEW, "dip is not smooth");
        prev = f[0].r;
    }
    TEST_ASSERT_TRUE(scale(kSolid, cfg::CANDLE_DIP_LEVEL) == f[0]);
}

// rnd(CANDLE_DIP_CHANCE) == 1 -> never a dip: level stays within 89..100 %.
static uint32_t noDipRandom(uint32_t bound) { return bound == cfg::CANDLE_DIP_CHANCE ? 1 : 0; }

static void test_candle_without_dips_stays_above_89_percent(void) {
    Candle fx;
    Frame f;
    EffectContext ctx{kMakeup, noDipRandom};
    fx.begin(ctx);
    const uint8_t floorW = scale8(255, cfg::CANDLE_MIN_LEVEL);
    while (fx.step(f, ctx)) {
        TEST_ASSERT_TRUE(f[0].w >= floorW);
        TEST_ASSERT_TRUE(ringUniform(f));
    }
}
```

Реестр/протокол: `Candle`, `"candle"`, `sawCandle`, `% 6`; `{"effect": "candle"}`.

- [ ] **Шаг 2: RED.**

- [ ] **Шаг 3: реализация**

`Config.h`:

```cpp
// --- Candle effect (v1.2.0) --------------------------------------------------
// The whole ring trembles between CANDLE_MIN_LEVEL and 255; every
// CANDLE_RETARGET_STEPS a new target, with a 1/CANDLE_DIP_CHANCE chance of a
// dip down to CANDLE_DIP_LEVEL; movement <= CANDLE_SLEW per step.
constexpr uint32_t CANDLE_STEP_MS        = 40;
constexpr uint16_t CANDLE_STEPS          = 500;  // ~20 s
constexpr uint16_t CANDLE_FADE_STEPS     = 25;   // 1 s
constexpr uint8_t  CANDLE_MIN_LEVEL      = 227;  // 89 %
constexpr uint8_t  CANDLE_DIP_LEVEL      = 204;  // 80 %
constexpr uint8_t  CANDLE_DIP_CHANCE     = 20;
constexpr uint8_t  CANDLE_SLEW           = 8;
constexpr uint8_t  CANDLE_RETARGET_STEPS = 3;
```

`Types.h`: `..., Embers, Candle };`

`effects/Candle.h`:

```cpp
// Candle (v1.2.0): the whole ring trembles like a candle flame — mostly
// 89..100 % of the base colour, with rare dips towards 80 %.
#pragma once

#include <cstdint>

#include "Effect.h"

class Candle : public Effect {
public:
    void begin(const EffectContext& ctx) override;
    uint16_t stepIntervalMs() const override;
    bool step(Frame& out, const EffectContext& ctx) override;

private:
    uint16_t step_   = 0;
    uint8_t  level_  = 255;
    uint8_t  target_ = 255;
};
```

`effects/Candle.cpp`:

```cpp
#include "Candle.h"

#include "../ColorMath.h"
#include "../Config.h"
#include "../Frame.h"

namespace {
uint8_t fadeAlpha(uint16_t step, uint16_t total, uint16_t fade) {
    if (step < fade) return static_cast<uint8_t>(step * 255 / fade);
    if (step > total - fade) return static_cast<uint8_t>((total - step) * 255 / fade);
    return 255;
}
}  // namespace

void Candle::begin(const EffectContext&) {
    step_ = 0;
    level_ = target_ = 255;
}

uint16_t Candle::stepIntervalMs() const { return static_cast<uint16_t>(cfg::CANDLE_STEP_MS); }

bool Candle::step(Frame& out, const EffectContext& ctx) {
    const uint8_t alpha = fadeAlpha(step_, cfg::CANDLE_STEPS, cfg::CANDLE_FADE_STEPS);

    if (step_ % cfg::CANDLE_RETARGET_STEPS == 0) {
        if (ctx.random(cfg::CANDLE_DIP_CHANCE) == 0) {
            target_ = static_cast<uint8_t>(cfg::CANDLE_DIP_LEVEL + ctx.random(cfg::CANDLE_MIN_LEVEL - cfg::CANDLE_DIP_LEVEL));
        } else {
            target_ = static_cast<uint8_t>(cfg::CANDLE_MIN_LEVEL + ctx.random(255 - cfg::CANDLE_MIN_LEVEL + 1));
        }
    }
    if (level_ < target_) level_ = static_cast<uint8_t>(level_ + ((target_ - level_ < cfg::CANDLE_SLEW) ? (target_ - level_) : cfg::CANDLE_SLEW));
    else if (level_ > target_) level_ = static_cast<uint8_t>(level_ - ((level_ - target_ < cfg::CANDLE_SLEW) ? (level_ - target_) : cfg::CANDLE_SLEW));

    out.fill(scale(ctx.base, lerp8(255, level_, alpha)));
    ++step_;
    return step_ < cfg::CANDLE_STEPS;
}
```

(Дублирование `fadeAlpha` с `Embers.cpp` — после GREEN вынести в `effects/Effect.h` как `inline uint8_t fadeAlpha(...)`
и использовать из обоих файлов; это рефакторинг при зелёных тестах.)

Реестр: `Candle s_candle;`, `{EffectId::Candle, "candle", &s_candle},`. `ha_mirror.yaml`: `- candle`.

- [ ] **Шаг 4: GREEN**, рефакторинг `fadeAlpha`, снова GREEN, обе сборки.

- [ ] **Шаг 5: документация.**

- [ ] **Шаг 6: коммит и пауза**

```bash
git add firmware/lib/MirrorCore/src/effects/Candle.h firmware/lib/MirrorCore/src/effects/Candle.cpp \
  firmware/lib/MirrorCore/src/effects/Embers.cpp firmware/lib/MirrorCore/src/effects/Effect.h \
  firmware/lib/MirrorCore/src/effects/EffectRegistry.cpp firmware/lib/MirrorCore/src/Config.h firmware/lib/MirrorCore/src/Types.h \
  firmware/test/test_effects/test_main.cpp firmware/test/test_protocol/test_main.cpp ha_mirror.yaml README.md ARCHITECTURE.md
git commit -m "feat: эффект candle — «свеча» (п.3)

Всё кольцо дрожит по яркости 89–100 %, изредка (1/20) проваливаясь до
80–89 %, движение к цели ≤ 8 за шаг 40 мс; ~20 с с плавным входом и
выходом. Общий fadeAlpha вынесен в Effect.h. В реестре, effect_list и random.

Co-Authored-By: Claude Fable 5.1 <noreply@anthropic.com>"
```

**ПАУЗА — ждать «продолжай».**

---

### Задача 7: эффект `comet` — «метеор» (пункт 5)

**Файлы:** создать `effects/Comet.{h,cpp}`; изменить `Config.h`, `Types.h`, `EffectRegistry.cpp`, `test_effects`,
`test_protocol`, `ha_mirror.yaml`, `README.md`, `ARCHITECTURE.md`.

**Интерфейсы:** `class Comet : public Effect`, `EffectId::Comet`, `"comet"`,
`cfg::COMET_STEP_MS = 30`, `cfg::COMET_TAIL = 40`, `cfg::COMET_FADE_STEPS = 20`. Использует `lerp` из Задачи 1 и
`fadeAlpha` из Задачи 6.

- [ ] **Шаг 1: тесты (RED)**

```cpp
// --- Comet (v1.2.0): white head, 40-LED quadratic tail, one lap ---------------

static const Rgbw kWhite{255, 255, 255, 255};

static void test_comet_finishes_after_209_steps_and_starts_on_base(void) {
    Comet fx;
    Frame f;
    EffectContext ctx{kSolid, zeroRandom};  // start 0, direction +1
    fx.begin(ctx);
    TEST_ASSERT_EQUAL_UINT16(cfg::COMET_STEP_MS, fx.stepIntervalMs());
    TEST_ASSERT_TRUE(fx.step(f, ctx));
    for (uint16_t i = 0; i < Frame::kSize; ++i) TEST_ASSERT_TRUE(kSolid == f[i]);  // alpha 0
    int calls = 1;
    while (fx.step(f, ctx)) ++calls;
    TEST_ASSERT_EQUAL_INT(cfg::TOTAL_LEDS + cfg::COMET_TAIL + 1, calls);
}

static void test_comet_head_is_white_with_quadratic_tail(void) {
    Comet fx;
    Frame f;
    EffectContext ctx{kSolid, zeroRandom};
    fx.begin(ctx);
    for (int i = 0; i <= 100; ++i) fx.step(f, ctx);  // renders step 100: head at pixel 100, full alpha
    TEST_ASSERT_TRUE(kWhite == f[100]);
    // 20 LEDs behind the head: t = ((40-20)/40)^2 = 0.25 -> lerp(base, white, 64)
    TEST_ASSERT_TRUE(lerp(kSolid, kWhite, 64) == f[80]);
    TEST_ASSERT_TRUE(kSolid == f[60]);   // 40 behind: tail end
    TEST_ASSERT_TRUE(kSolid == f[101]);  // ahead of the head
}

static void test_comet_adds_light_in_makeup(void) {
    Comet fx;
    Frame f;
    EffectContext ctx{kMakeup, zeroRandom};
    fx.begin(ctx);
    for (int i = 0; i <= 100; ++i) fx.step(f, ctx);
    TEST_ASSERT_TRUE(kWhite == f[100]);
    TEST_ASSERT_TRUE(f[90].r > 0 && f[90].w == 255);  // RGB rises on top of the white channel
}
```

Реестр/протокол: `Comet`, `"comet"`, `sawComet`, `% 7`; `{"effect": "comet"}`.

- [ ] **Шаг 2: RED.**

- [ ] **Шаг 3: реализация**

`Config.h`:

```cpp
// --- Comet effect (v1.2.0) ---------------------------------------------------
// A white head with a COMET_TAIL-LED quadratic tail travels once around the
// ring (TOTAL_LEDS + COMET_TAIL steps), fading in/out over COMET_FADE_STEPS.
constexpr uint32_t COMET_STEP_MS    = 30;
constexpr uint16_t COMET_TAIL       = 40;
constexpr uint16_t COMET_FADE_STEPS = 20;
```

`Types.h`: `..., Candle, Comet };`

`effects/Comet.h`:

```cpp
// Comet (v1.2.0): a bright white head with a fading tail flies once around
// the ring. Pixels are lerped from the base towards white, so it adds light
// in solid and in makeup alike.
#pragma once

#include <cstdint>

#include "Effect.h"

class Comet : public Effect {
public:
    void begin(const EffectContext& ctx) override;
    uint16_t stepIntervalMs() const override;
    bool step(Frame& out, const EffectContext& ctx) override;

private:
    uint16_t step_     = 0;
    uint16_t startPos_ = 0;
    int8_t   direction_ = 1;
};
```

`effects/Comet.cpp`:

```cpp
#include "Comet.h"

#include "../ColorMath.h"
#include "../Config.h"
#include "../Frame.h"

namespace {
constexpr uint16_t kTotalSteps = cfg::TOTAL_LEDS + cfg::COMET_TAIL;  // 208
constexpr Rgbw kWhite{255, 255, 255, 255};
}  // namespace

void Comet::begin(const EffectContext& ctx) {
    startPos_  = static_cast<uint16_t>(ctx.random(cfg::TOTAL_LEDS));
    direction_ = (ctx.random(2) == 0) ? 1 : -1;
    step_      = 0;
}

uint16_t Comet::stepIntervalMs() const { return static_cast<uint16_t>(cfg::COMET_STEP_MS); }

bool Comet::step(Frame& out, const EffectContext& ctx) {
    const uint8_t alpha = fadeAlpha(step_, kTotalSteps, cfg::COMET_FADE_STEPS);

    int head = static_cast<int>(startPos_) + static_cast<int>(step_) * direction_;
    while (head < 0) head += cfg::TOTAL_LEDS;
    while (head >= static_cast<int>(cfg::TOTAL_LEDS)) head -= cfg::TOTAL_LEDS;

    for (uint16_t i = 0; i < cfg::TOTAL_LEDS; ++i) {
        int dist = (direction_ == 1) ? (head - static_cast<int>(i)) : (static_cast<int>(i) - head);
        if (dist < 0) dist += cfg::TOTAL_LEDS;
        if (dist >= static_cast<int>(cfg::COMET_TAIL)) {
            out[i] = ctx.base;
            continue;
        }
        const uint16_t back = static_cast<uint16_t>(cfg::COMET_TAIL - dist);         // TAIL at the head, 1 at the end
        const uint8_t t = static_cast<uint8_t>(255UL * back * back / (cfg::COMET_TAIL * cfg::COMET_TAIL));
        out[i] = lerp(ctx.base, kWhite, scale8(t, alpha));
    }
    ++step_;
    return step_ <= kTotalSteps;
}
```

Реестр: `Comet s_comet;`, `{EffectId::Comet, "comet", &s_comet},`. `ha_mirror.yaml`: `- comet`.

- [ ] **Шаг 4: GREEN**, обе сборки.

- [ ] **Шаг 5: документация.**

- [ ] **Шаг 6: коммит и пауза**

```bash
git add firmware/lib/MirrorCore/src/effects/Comet.h firmware/lib/MirrorCore/src/effects/Comet.cpp \
  firmware/lib/MirrorCore/src/effects/EffectRegistry.cpp firmware/lib/MirrorCore/src/Config.h firmware/lib/MirrorCore/src/Types.h \
  firmware/test/test_effects/test_main.cpp firmware/test/test_protocol/test_main.cpp ha_mirror.yaml README.md ARCHITECTURE.md
git commit -m "feat: эффект comet — «метеор» (п.5)

Белая голова с хвостом из 40 светодиодов (квадратичное затухание) один
раз облетает кольцо (~6 с, шаг 30 мс). Пиксели смешиваются к белому,
поэтому эффект добавляет свет и в solid, и в Макияже.
В реестре, effect_list и random.

Co-Authored-By: Claude Fable 5.1 <noreply@anthropic.com>"
```

**ПАУЗА — ждать «продолжай».**

---

### Задача 8: диагностика в HA (пункт 13)

**Файлы:**
- Изменить: `Config.h`, `Topics.h`, `Topics.cpp`, `Protocol.h`, `Protocol.cpp`, `firmware/src/Network.cpp`,
  `firmware/test/test_protocol/test_main.cpp`, `ha_mirror.yaml`, `README.md`, `ARCHITECTURE.md`

**Интерфейсы:**
- Производит: `struct DiagInfo { uint32_t uptimeS; int8_t rssi; uint8_t resetReason; uint32_t freeHeap; uint32_t minFreeHeap; };`,
  `const char* resetReasonName(uint8_t code)`, `size_t buildDiagJson(const DiagInfo&, char* buf, size_t cap)`,
  `Topics::diag`, `cfg::DIAG_PERIOD_MS = 60000`, `cfg::DIAG_JSON_CAP = 192`.
- Network: `publishDiag()` при подключении и раз в `DIAG_PERIOD_MS`; `uptimeS` считается по секундам.

- [ ] **Шаг 1: тесты (RED)** — в `test_protocol`:

```cpp
// --- Diagnostics topic (v1.2.0) ---------------------------------------------

static void test_diag_topic_built_from_base(void) {
    Topics t;
    t.init(kBase);
    TEST_ASSERT_EQUAL_STRING("home/flat8/bath/mirror/diag", t.diag);
    TEST_ASSERT_TRUE(Route::Unknown == routeTopic("home/flat8/bath/mirror/diag", kBase));
}

static void test_reset_reason_names(void) {
    TEST_ASSERT_EQUAL_STRING("POWERON", resetReasonName(1));
    TEST_ASSERT_EQUAL_STRING("SW", resetReasonName(3));
    TEST_ASSERT_EQUAL_STRING("PANIC", resetReasonName(4));
    TEST_ASSERT_EQUAL_STRING("TASK_WDT", resetReasonName(6));
    TEST_ASSERT_EQUAL_STRING("BROWNOUT", resetReasonName(9));
    TEST_ASSERT_EQUAL_STRING("UNKNOWN", resetReasonName(0));
    TEST_ASSERT_EQUAL_STRING("UNKNOWN", resetReasonName(99));
}

static void test_diag_json(void) {
    DiagInfo d;
    d.uptimeS = 3723;
    d.rssi = -61;
    d.resetReason = 1;
    d.freeHeap = 231000;
    d.minFreeHeap = 198000;
    char buf[cfg::DIAG_JSON_CAP];
    const size_t n = buildDiagJson(d, buf, sizeof(buf));
    TEST_ASSERT_TRUE(n > 0);
    TEST_ASSERT_EQUAL_STRING(
        "{\"uptime_s\":3723,\"rssi\":-61,\"reset_reason\":\"POWERON\","
        "\"free_heap\":231000,\"min_free_heap\":198000,\"fw\":\"1.2.0\"}",
        buf);
    char small[16];
    TEST_ASSERT_EQUAL_UINT32(0, buildDiagJson(d, small, sizeof(small)));
}
```

- [ ] **Шаг 2: RED** — ошибки компиляции (`DiagInfo`, `diag`).

- [ ] **Шаг 3: реализация**

`Config.h` (блок Network): `constexpr uint32_t DIAG_PERIOD_MS = 60UL * 1000;` и `constexpr size_t DIAG_JSON_CAP = 192;`.
`Topics.h`: поле `char diag[96];`; `Topics.cpp`: `std::snprintf(diag, sizeof(diag), "%s/diag", base);`.
`Protocol.h`:

```cpp
// Diagnostics published on <base>/diag (v1.2.0), gathered on Core 0 only.
struct DiagInfo {
    uint32_t uptimeS = 0;
    int8_t   rssi = 0;
    uint8_t  resetReason = 0;  // esp_reset_reason_t value
    uint32_t freeHeap = 0;
    uint32_t minFreeHeap = 0;
};
const char* resetReasonName(uint8_t code);  // "POWERON", "SW", "PANIC", ... "UNKNOWN"
size_t buildDiagJson(const DiagInfo& d, char* buf, size_t cap);  // 0 if it doesn't fit
```

`Protocol.cpp`:

```cpp
const char* resetReasonName(uint8_t code) {
    switch (code) {  // esp_reset_reason_t (ESP-IDF 4.4)
        case 1: return "POWERON";
        case 2: return "EXT";
        case 3: return "SW";
        case 4: return "PANIC";
        case 5: return "INT_WDT";
        case 6: return "TASK_WDT";
        case 7: return "WDT";
        case 8: return "DEEPSLEEP";
        case 9: return "BROWNOUT";
        case 10: return "SDIO";
        default: return "UNKNOWN";
    }
}

size_t buildDiagJson(const DiagInfo& d, char* buf, size_t cap) {
    JsonDocument doc;
    doc["uptime_s"] = d.uptimeS;
    doc["rssi"] = d.rssi;
    doc["reset_reason"] = resetReasonName(d.resetReason);
    doc["free_heap"] = d.freeHeap;
    doc["min_free_heap"] = d.minFreeHeap;
    doc["fw"] = cfg::FW_VERSION;
    if (measureJson(doc) >= cap) return 0;
    return serializeJson(doc, buf, cap);
}
```

`Network.cpp` (анонимное пространство имён): переменные `uint32_t uptimeS = 0, lastUptimeTick = 0, lastDiagPublish = 0;`;

```cpp
void publishDiag() {
    DiagInfo d;
    d.uptimeS = uptimeS;
    d.rssi = static_cast<int8_t>(WiFi.RSSI());
    d.resetReason = static_cast<uint8_t>(esp_reset_reason());
    d.freeHeap = ESP.getFreeHeap();
    d.minFreeHeap = ESP.getMinFreeHeap();
    char buf[cfg::DIAG_JSON_CAP];
    if (buildDiagJson(d, buf, sizeof(buf)) == 0) {
        MLOG("diag json did not fit\n");
        return;
    }
    mqtt.publish(topics.diag, buf, true);
}
```

В цикле задачи, сразу после `const uint32_t now = millis();`: `while ((uint32_t)(now - lastUptimeTick) >= 1000) { lastUptimeTick += 1000; ++uptimeS; }`
(инициализировать `lastUptimeTick = millis()` перед циклом). После `publishAll(latest);` при подключении —
`publishDiag(); lastDiagPublish = connectedAt;`. В ветке «connected» после heartbeat:
`if ((uint32_t)(now - lastDiagPublish) >= cfg::DIAG_PERIOD_MS) { publishDiag(); lastDiagPublish = now; }`.
Заголовок `#include <esp_system.h>` для `esp_reset_reason()`.

`ha_mirror.yaml` — в `sensor:` добавить:

```yaml
    # --- Диагностика (топик diag, раз в минуту и при подключении) ---
    - name: "Зеркало: аптайм"
      unique_id: mirror_uptime
      state_topic: "home/flat8/bath/mirror/diag"
      value_template: "{{ value_json.uptime_s }}"
      availability_topic: "home/flat8/bath/mirror/availability"
      device_class: duration
      unit_of_measurement: "s"
      state_class: measurement
      entity_category: diagnostic
      icon: "mdi:timer-outline"
      device: *mirror_device

    - name: "Зеркало: WiFi"
      unique_id: mirror_wifi_rssi
      state_topic: "home/flat8/bath/mirror/diag"
      value_template: "{{ value_json.rssi }}"
      availability_topic: "home/flat8/bath/mirror/availability"
      device_class: signal_strength
      unit_of_measurement: "dBm"
      state_class: measurement
      entity_category: diagnostic
      device: *mirror_device

    - name: "Зеркало: причина перезагрузки"
      unique_id: mirror_reset_reason
      state_topic: "home/flat8/bath/mirror/diag"
      value_template: "{{ value_json.reset_reason }}"
      availability_topic: "home/flat8/bath/mirror/availability"
      entity_category: diagnostic
      icon: "mdi:restart-alert"
      device: *mirror_device

    - name: "Зеркало: свободная память"
      unique_id: mirror_free_heap
      state_topic: "home/flat8/bath/mirror/diag"
      value_template: "{{ value_json.free_heap }}"
      availability_topic: "home/flat8/bath/mirror/availability"
      device_class: data_size
      unit_of_measurement: "B"
      state_class: measurement
      entity_category: diagnostic
      icon: "mdi:memory"
      device: *mirror_device
```

Проверить YAML: `python3 -c "import yaml;yaml.safe_load(open('ha_mirror.yaml',encoding='utf-8'))"`.

- [ ] **Шаг 4: GREEN** — все тесты, обе сборки (Network.cpp — без предупреждений).

- [ ] **Шаг 5: документация** — `ARCHITECTURE.md` §5.1 строка `<base>/diag`, §5.4 «Диагностика» с JSON; `README.md`:
  таблица телеметрии, таблица HA (4 сенсора), «Возможности».

- [ ] **Шаг 6: коммит и пауза**

```bash
git add firmware/lib/MirrorCore/src/Config.h firmware/lib/MirrorCore/src/Topics.h firmware/lib/MirrorCore/src/Topics.cpp \
  firmware/lib/MirrorCore/src/Protocol.h firmware/lib/MirrorCore/src/Protocol.cpp firmware/src/Network.cpp \
  firmware/test/test_protocol/test_main.cpp ha_mirror.yaml README.md ARCHITECTURE.md
git commit -m "feat: диагностика в Home Assistant (п.13)

Новый retained-топик <base>/diag (при подключении и раз в минуту):
аптайм, уровень WiFi (RSSI), причина последней перезагрузки, свободная
и минимальная свободная куча, версия прошивки. Четыре диагностических
сенсора в ha_mirror.yaml. Собирается только на Core 0.

Co-Authored-By: Claude Fable 5.1 <noreply@anthropic.com>"
```

**ПАУЗА — ждать «продолжай».**

---

### Задача 9: сводная документация и релиз v1.2.0

**Файлы:** `ARCHITECTURE.md` (шапка: статус v1.2.0; §4.2 итоговая таблица из 7 эффектов; §9.1 таблица размеров;
§11.1 пункты 15–20), `README.md` (история версий v1.2.0, чек-лист проверки на железе: пункты 8–12 — переходы,
затухание перед автовыключением, 45 мин в Макияже, каждый новый эффект, сенсоры диагностики), `ha_mirror.yaml`
(шапка «прошивка v1.2.0»).

- [ ] **Шаг 1:** обновить документы, снять размеры Flash/RAM с обеих сборок, `$P test -e native` — итоговое число тестов
  в README.
- [ ] **Шаг 2: коммит**

```bash
git add ARCHITECTURE.md README.md ha_mirror.yaml
git commit -m "docs: сводка v1.2.0 — эффекты, переходы, автоматика, диагностика

Co-Authored-By: Claude Fable 5.1 <noreply@anthropic.com>"
```

- [ ] **Шаг 3:** слияние в `main`, push и тег `v1.2.0` — **только по команде владельца**, после проверки на железе
  (чек-лист README).

---

## Самопроверка плана

- **Покрытие:** пункты владельца 1 (Задача 4), 2 (5), 3 (6), 5 (7), 6 (1), 8 (3), 9 (2), 13 (8); 12 — уже реализовано
  (сброс к дефолтам при выключении, §4.1); 4, 7, 10, 11 — отклонены.
- **Согласованность имён:** `finishFrame()` вводится в Задаче 1 и меняется в Задаче 2; `autoOffLimit()` — Задача 2,
  уточняется в 3; `fadeAlpha` — дублируется в 5, выносится в `Effect.h` в 6, используется в 7; `lerp`/`lerp8` — Задача 1,
  используются в 5, 6, 7; `powerOnSettled`, `run`, `allPixelsEqual`, `kSolidDefault`, `kMakeupColor` — уже есть в
  `test_mirror`; `ringUniform` вводится в Задаче 4 и используется в 6; `kWhite` — Задача 7.
- **Тесты реестра:** `cyclingRandom` в `test_effects` берёт `% bound`, поэтому сам подстраивается; в
  `test_random_effect_covers_all` после каждой задачи 4–7 растёт число итераций (4, 5, 6, 7) и флагов `saw*`.
- **Плейсхолдеров нет.**

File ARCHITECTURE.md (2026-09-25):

# ARCHITECTURE — Smart Mirror RGBW, прошивка v1.5.1

> Статус: **реализован и проверен на железе.** Ветка `refactor/v1` слита в `main` 21.09.2026; 22.09.2026 прошивка
> v1.0.0 собрана, прошита в зеркало и работает так же, как v27.
>
> v1.0.1 (22.09.2026): анимация включения/выключения на ~20% медленнее и с мягким краем на ~20% длиннее (§4.1).
>
> v1.1.0 (22.09.2026): глитч «сбой неона» — короткое мерцание 3–6 светодиодов примерно раз в минуту (§4.6).
>
> v1.1.1 (22.09.2026): у глитча мягкие края — по 2–3 светодиода плавного перехода к обычному свету (§4.6).
>
> v1.2.0 (22.09.2026; на железе — в составе v1.3.1): плавные переходы цвета и яркости (§4.2), затухание за
> минуту до автовыключения и 45 мин в Макияже (§4.4), четыре новых эффекта `breathe`, `embers`, `candle`,
> `comet` (§4.2) и диагностический топик `<base>/diag` (§5.4).
>
> v1.2.1 (23.09.2026; на железе — в составе v1.3.1): ревизия надёжности для круглосуточной работы — watchdog
> на Core 1, общая блокировка RMT и повтор кадра (§3.3, §3.5), «умный» сетевой watchdog и потокобезопасный
> поиск брокера (§3.4), флаги в RTC-памяти, защита от залипших кнопки и PIR, команды как активность (§4.3,
> §4.4) и ряд мелких исправлений; постоянная симуляция долгой работы `test_soak` (§9.1).
>
> v1.2.2 (23.09.2026): в диагностике — последний запущенный эффект (`last_effect`, §5.4), чтобы владелец мог
> понять, какой из новых эффектов что показывает, и решить, править их или убрать.
>
> v1.3.0 (23.09.2026; на железе — в составе v1.3.1): по отзыву владельца — все новые градиенты считаются в
> шкале восприятия CIE 1931 (§6.1), `candle` убран, `embers` переделан в редкие угольки с мягкими соседями,
> края глитча 4–6 светодиодов (§4.2, §4.6).
>
> v1.3.1 (23.09.2026, **проверена на железе**, тег `v1.3.1`): угольки `embers` глубже — до 10–30 % для глаза — и с
> градиентным краем по 2 светодиода. Прошита вместе со всем из v1.2.0–v1.3.0; владелец: «вроде всё гуд, пока
> оставляем так».
>
> v1.3.2 (23.09.2026): мягкий край анимации включения/выключения — в шкале восприятия CIE 1931 и в полтора
> раза длиннее: 15 светодиодов вместо 10 (`SLIDE_EDGE` = 16 вместо 11), анимация ≈ 3,4 с вместо ≈ 3,2 с
> (§4.1, §6.1).
>
> v1.4.0 (24.09.2026): эффект `breathe` заменён на `flame` — вместо всего кольца разом «дышат» отдельные участки
> по 10–15 светодиодов с мягкими краями, каждый на своих часах, до той же глубины 60 % для глаза, ≈ 20 с
> (§4.2). В `effect_list` HA — `flame` вместо `breathe`.
>
> v1.4.1 (24.09.2026, **проверена на железе**): `flame` был почти незаметен — блоки шире и глубже: ровное ядро
> 10–12 светодиодов и градиент по 3–4 с каждой стороны пропорционально ядру (16–20 всего), ядро гаснет до 30 %
> для глаза вместо 60 % (§4.2). Владелец: «теперь лучше, flame оставляем так».
>
> v1.4.2 (24.09.2026): радужная змейка `rainbow` при каждом запуске перемешивает шесть опорных цветов в случайном
> порядке; между ними цвет идёт кратчайшим путём по цветовому кругу. Остальное — как в v27 (§4.2).
>
> v1.5.0 (25.09.2026): ночной режим с кнопки — удержание при выключенном свете включает и выключает его, тёмное
> кольцо подтверждает одной или двумя вспышками; включение света кликом заодно включает автоматику, чтобы
> зеркало, включённое рукой, не горело бесконечно (§4.3, §4.4).
>
> v1.5.1 (25.09.2026): ночной режим с кнопки переключает и автоматику — выключает её вместе с ним и включает
> при снятии, чтобы выключатель «автодетекция движения» в HA показывал, зажигает ли датчик свет (§4.3).
>
> v1.0.0 — порт прошивки v27 (Gemini-эпоха) с монолитного `main.cpp` на модульную архитектуру.
> Нумерация версий начинается заново с 1. Визуальное поведение (скорости, размеры, цвета) сохраняется,
> все намеренные изменения поведения перечислены в разделе 11.

---

## 1. Цели

1. **Потокобезопасность by design.** Ядро 0 физически не имеет доступа к ленте и к состоянию зеркала.
2. **Новый эффект = 3 декларативные правки** (класс, строка реестра, строка в `effect_list` HA).
3. **Логика тестируется на ПК** (`pio test -e native`) без железа.
4. **Исправить баги v27** (раздел 11.2), не потеряв ни одного пункта из «Критических правил».

Вне рамок v1: OTA, HA MQTT Discovery, runtime-настройка параметров, NVS.

---

## 2. Железо и пины

| GPIO | Назначение | Примечание |
|---|---|---|
| 4 | `PIN_LED_LEFT` — лента малой (левой) двери, 66 LED | SK6812 GRBW через SN74AHCT125 |
| 5 | `PIN_LED_RIGHT` — лента большой (правой) двери, 102 LED | SK6812 GRBW через SN74AHCT125 |
| 6 | `PIN_PIR` — PIR, активный `HIGH` | `INPUT_PULLDOWN` |
| 7 | `PIN_BUTTON` — кнопка через SN74LVC2G14 | нажата = `HIGH`, аппаратный антидребезг |
| 21 | `PIN_STATUS_LED` — встроенный WS2812 | только Core 0 |

MCU: ESP32-S3 Zero, **Flash 4 MB**, USB-CDC. Разметка `default.csv` (без изменений).

---

## 3. Двухядерная модель

### 3.1 Владение ресурсами

```
┌──────────────── Core 0: NetworkTask ────────────────┐      ┌──────────────── Core 1: loop() ─────────────────┐
│ WiFi, PubSubClient, Status LED (GPIO 21), watchdog  │      │ Button, PIR, Mirror (state machine), Effects,   │
│                                                     │      │ LedDriver (GPIO 4/5)                            │
│ MQTT msg ─► Protocol::toCommand() ─► Command ───────┼─────►│ cmdQueue (xQueue, 8) ─► Mirror::apply()         │
│                                                     │      │                                                 │
│ publish ◄── Protocol::buildStateJson() ◄── Snapshot ◄┼──────┤ snapQueue (xQueue, 1, xQueueOverwrite)          │
└─────────────────────────────────────────────────────┘      └─────────────────────────────────────────────────┘
```

| Ресурс | Владелец | Кто ещё может трогать |
|---|---|---|
| `Mirror`, `Button`, `LedDriver` (объекты `static` в `main.cpp`) | Core 1 | никто — они не видны из других единиц трансляции |
| `stripL`, `stripR` (Adafruit_NeoPixel) | Core 1 (`LedDriver`) | никто |
| WiFi, `PubSubClient`, `StatusLed` | Core 0 (`Network.cpp`) | никто |
| периферия RMT (через Adafruit NeoPixel) | `LedDriver` (Core 1) и `StatusLed` (Core 0) по очереди | только под `RmtLock` (§3.5, v1.2.1) |
| `cmdQueue` | пишет Core 0, читает Core 1 | — |
| `snapQueue` (mailbox из 1 элемента) | пишет Core 1 (`xQueueOverwrite`), читает Core 0 | — |

**Общего состояния под мьютексом и `volatile`-глобалов нет.** `Command` и `StateSnapshot` — POD-структуры,
копируются очередью FreeRTOS по значению. Единственный мьютекс — `RmtLock` (v1.2.1): он защищает не
данные, а одну железку, модуль RMT, который оба ядра используют для вывода на светодиоды (§3.5).

### 3.2 Почему так (правило №2)

В v27 `mqttCallback` на Core 0 сам вызывал `triggerPowerOn/Off`, `startRandomEffect` под `stateMutex`.
Безопасность держалась на комментарии «не вызывай отсюда `setGlobalColor()`». В v1 `Network.cpp`
не включает ни `Mirror.h`, ни `LedDriver.h` и не видит их объектов — вызвать отрисовку с Core 0 невозможно
на уровне компиляции.

### 3.3 Цикл Core 1 (`loop()`)

```cpp
void loop() {
    const uint32_t now = millis();

    Command cmd;
    while (xQueueReceive(cmdQueue, &cmd, 0) == pdTRUE) mirror.apply(cmd, now);   // 1. команды из сети

    ButtonEvent ev = button.update(digitalRead(PIN_BUTTON) == BTN_PRESSED, now);  // 2. кнопка
    if (ev.type != ButtonEventType::None) mirror.onButton(ev, now);

    mirror.onPir(digitalRead(PIN_PIR) == HIGH, now);                               // 3. PIR
    mirror.tick(now);                                                              // 4. таймеры + шаг анимации

    // 5. вывод: кадр изменился, прошлый не взял RmtLock, или прошло FRAME_REFRESH_MS (v1.2.1)
    if (mirror.takeFrameDirty() || redrawPending || refreshDue) {
        if (leds.show(mirror.frame())) { redrawPending = false; lastShowMs = now; }
        else { /* повтор на следующем проходе; блокировка занята > 2 с -> esp_restart() */ }
    }

    StateSnapshot s = mirror.snapshot();                                           // 6. снимок для сети
    if (!(s == lastSnapshot)) { xQueueOverwrite(snapQueue, &s); lastSnapshot = s; }

    vTaskDelay(pdMS_TO_TICKS(cfg::LOOP_IDLE_DELAY_MS));                            // 5 мс
}
```

Бюджет кадра: вывод 168 LED × 32 бита × 1,25 мкс ≈ **6,7 мс** (обе ленты последовательно).
Тик цикла ≈ 5 мс + работа. Кадры выводятся только когда изменились: slide — шаг 33 мс (с v1.0.1; в v27 — 28 мс),
змейка — 40 мс, волна — 45 мс (≈30/25/22 FPS). В статике кадр переотправляется раз в `FRAME_REFRESH_MS` = 2 с
(v1.2.1): SK6812 держат то, что последним защёлкнули, и кадр, испорченный помехой, иначе оставался бы до
следующего изменения — на тёмном зеркале хоть всю ночь. Повтор того же кадра невидим.

**Watchdog на Core 1 (v1.2.1).** В конце `setup()` вызывается `enableLoopWDT()`: ядро Arduino кормит task
watchdog перед каждым проходом `loop()` (каждые 5–12 мс), и проход дольше 5 с — например, зависший `show()`
— вызывает панику и перезагрузку. По умолчанию ядро Arduino задачу `loop()` на watchdog не подписывает, а
sdkconfig следит только за задачей простоя ядра 0. На Core 0 `NetworkTask` на watchdog не подписана: все её
ожидания ограничены таймаутами (сокет MQTT — 3 с, поиск адреса, WiFi — циклы с `vTaskDelay`), а зависание
`show()` статус-светодиода под `RmtLock` ловит `loop()` на Core 1 (см. §3.5).

### 3.4 Цикл Core 0 (`NetworkTask`)

1. **Watchdog** (`NetWatchdog`, v1.2.1) — на каждом проходе меряет простой:
   - WiFi нет > 5 мин → `ESP.restart()` (как в v27: зависший стек WiFi лечится перезагрузкой);
   - WiFi есть, MQTT нет > 30 мин → **переподключение к WiFi**, а не перезагрузка: мёртвый брокер (HA
     обновляется) перезагрузка не лечит, а протухшую аренду DHCP или конфликт IP после замены роутера
     переподключение лечит;
   - оба действия ждут, пока зеркало **30 с подряд** тёмное и PIR молчит (`RESTART_QUIET_MS`, больше
     slide-out + кулдауна PIR + blackout — проверяется `static_assert`). Горящее зеркало не гаснет посреди
     использования, а перезагрузка сразу после выключения не стирает 15-секундный кулдаун PIR и не зажигает
     свет в спину уходящему. Окно тишины начинается с первого тихого наблюдения: без WiFi проходы идут раз
     в ~10 с, и промежуток до него мог быть «горящим».

   В v1.2.0 и v27 правило было «WiFi или MQTT > 5 мин суммарно → сразу», и при долгом простое брокера зеркало
   гасло каждые ~5,5 мин прямо во время использования. Простой считается между проходами, поэтому «моргающий»
   WiFi засчитывается только за реальное время без связи. Почтовый ящик снимков читается в начале каждого
   прохода, в том числе без сети, — иначе `latest.on`/`latest.pir` устаревали бы.
2. **WiFi** — при старте задачи: `WiFi.setHostname("SmartMirror")` вызывается **до** `WiFi.mode(WIFI_STA)`
   (Ruling R11) — на Arduino-ESP32 2.0.17 `setHostname()` только кладёт имя в локальный кэш, а в сетевой стек
   его передаёт `mode()`, причём лишь когда режим действительно меняется; в обратном порядке DHCP увидел бы
   автосгенерированное `esp32s3-XXXXXX`. При потере связи: `disconnect()`/`begin()`, до 20 × 500 мс — кроме случая, когда мы уже подключены к точке доступа и ждём адрес от DHCP (биты `STA_CONNECTED_BIT` без `STA_HAS_IP_BIT`): такую попытку не рвём до 60 с (`WIFI_DHCP_WAIT_MAX_MS`, v1.2.1; после перезагрузки роутера DHCP бывает медленнее 10 с). По `WL_IDLE_STATUS` это не определить: ядро ставит его и после `LOST_IP`, когда связи с точкой доступа уже нет;
   после `WL_CONNECTED` — **`WiFi.setSleep(false)`**.
3. **MQTT** — `setBufferSize(512)`, `setSocketTimeout(3)`, `setKeepAlive(15)`, стабильный client id `ESP32S3-Mirror-<MAC[3..5]>`,
   LWT `<base>/availability = "offline"` (retain). После connect: подписка `<base>/set` и `<base>/+/set`,
   публикация **всех** state-топиков из последнего снимка и `diag`, и только потом `availability = "online"`
   (v1.2.1: при появлении доступности HA показывает закешированное состояние до следующего сообщения, и
   обратный порядок давал секундный ложный фронт, например «вкл» → «выкл»). В debug-сборке после первого
   connect один раз логируется запас стека задачи (`uxTaskGetStackHighWaterMark`, байты из 10000).
   Адрес брокера (v1.2.1) перед каждой попыткой ищется через `getaddrinfo()` lwIP, и подключение идёт уже по
   IP: `WiFi.hostByName()` в Arduino 2.0.17 зовёт резолвер без блокировки ядра lwIP и бросает ожидание по
   своему таймауту, после чего запоздалый ответ DNS пишет в уже несуществующий кадр стека. Таймаут сокета MQTT
   — 3 с, меньше task watchdog (5 с): PubSubClient ждёт CONNACK в пустом цикле.
4. **Снимок** — `xQueueReceive(snapQueue, &snap, 0)`; при новом снимке — публикация изменившегося, но не чаще
   1 раза в 250 мс (mailbox всегда хранит последнее состояние, поэтому финальное значение гарантированно уйдёт).
   Основной `state` при этом переопубликовывается, только если изменилось поле, входящее в его JSON
   (`stateJsonDiffers()`, Ruling R16): изменение одного `pir` уходит только в `pir/state`.
   Периодический heartbeat основного `state` — раз в 10 с.
5. **Status LED**: жёлтый — подключение WiFi, синий — подключение MQTT, зелёная вспышка 1 с — MQTT подключён,
   короткое (50 мс) тусклое зелёное мигание — **только** heartbeat `state` раз в 10 с (Ruling R16); публикации
   по событиям (PIR, эффекты, диммирование) статус-светодиод не трогают.

Переполнение `cmdQueue` (8 элементов) практически невозможно (Core 1 опустошает её каждые ~5 мс);
если `xQueueSend(..., 0)` вернул `errQUEUE_FULL` — команда отбрасывается с записью в лог.

### 3.5 Известные риски

**Питание лент (не исправлялось, нужно измерение).** Ограничителя тока в прошивке нет. Дефолтный тёплый цвет
(255, 140, 50) на полной яркости — ≈ 1,75 канала на светодиод, чистый белый RGB из HA — ≈ 3 канала, голова
`comet` — все четыре. Если блок питания или провода не тянут, возможны просадки и сброс по brownout; это видно
в HA по сенсору «причина перезагрузки» (`BROWNOUT`). Решение — измерить ток на дефолтном цвете и на белом и,
если нужно, добавить в `LedDriver::show` масштабирование кадра по суммарному бюджету.

**Длительность эффектов на железе ~7–15 % больше расчётной (сознательно).** Шаг анимации начинается на первом
проходе `loop()` после интервала (`lastStepMs_ = now`), и опоздание прохода (5 мс задержки + ~7 мс вывода)
накапливается. Так было и в v27, а скорость slide с v1.0.1 владелец проверил вживую, поэтому менять не стали.

**Гонка в Adafruit NeoPixel на RMT (унаследовано от v27, Ruling R12) — закрыта в v1.2.1.** На ESP-IDF 4.4
(ядро Arduino-ESP32 2.0.17) `Adafruit_NeoPixel::show()` при каждом вызове заново настраивает канал RMT,
устанавливает драйвер, передаёт кадр с ожиданием конца передачи и снимает драйвер. `StatusLed::set()` (Core 0)
и `LedDriver::show()` (Core 1) делали это независимо. Ревизия v1.2.1 показала, что окно гонки — не «несколько
инструкций», а десятки микросекунд: снятие последнего установленного драйвера выключает и сбрасывает модуль
RMT, стирая только что записанные настройки канала другого ядра. Итог — искажённый кадр, а если потеряно
прерывание конца передачи, `show()` ждёт вечно. Кроме того, прерывание RMT могло оказаться на ядре WiFi.

Решение: **`RmtLock`** (`src/RmtLock.{h,cpp}`) — один мьютекс FreeRTOS вокруг каждого `show()` на обоих
ядрах. Это блокировка периферии, а не общего состояния: логика ядер по-прежнему связана только очередями.
Ожидание ограничено `RMT_LOCK_TIMEOUT_MS` = 50 мс (кадр ленты держит блокировку ≈ 7 мс, статус-светодиод —
меньше 1 мс); при таймауте кадр пропускается, и `loop()` рисует его снова на следующем проходе
(`redrawPending`), а мигание статус-светодиода просто пропускается.
Если лента не может взять блокировку `SHOW_STALL_RESTART_MS` = 2 с подряд, значит её держатель завис внутри
`show()` (например, статус-светодиод на Core 0 ждёт потерянное прерывание) — watchdog этого не видит,
потому что `loop()` продолжает крутиться, и `loop()` сам делает `esp_restart()`.

---

## 4. Конечный автомат зеркала

Состояние зеркала — это четыре независимых измерения:

| Измерение | Значения | Где хранится |
|---|---|---|
| **Питание** | `OFF`, `SLIDE_ON`, `ON`, `SLIDE_OFF` | `Mirror::power_` |
| **Базовый режим** | `Solid` (RGB), `Makeup` (только W) | `Mirror::base_` |
| **Временный эффект** | `None`, `Dark`, `Rainbow`, `Wave` (+ отложенный `pending_`) | `Mirror::effect_` |
| **Автоматика/PIR** | флаги `automation`, `nightMode` + таймеры `cooldown`, `blackout` | `MotionGate` |

Плюс параметры: `brightness` (0..255), цвет `r,g,b`, направление диммирования, таймеры активности.

### 4.1 Питание

```mermaid
stateDiagram-v2
    [*] --> OFF
    OFF --> SLIDE_ON: powerOn
    SLIDE_ON --> ON: радиус достиг max
    SLIDE_ON --> SLIDE_OFF: powerOff (с текущего радиуса)
    ON --> SLIDE_OFF: powerOff / auto-off (с max радиуса)
    SLIDE_OFF --> SLIDE_ON: powerOn (с текущего радиуса)
    SLIDE_OFF --> OFF: радиус < 0 → applyDefaults(), blackout 2 с
```

| Событие \ Состояние | `OFF` | `SLIDE_ON` | `ON` | `SLIDE_OFF` |
|---|---|---|---|---|
| `powerOn()` | → `SLIDE_ON`, радиус 0 | — | — | → `SLIDE_ON`, радиус текущий |
| `powerOff(manual)` | — | → `SLIDE_OFF`, радиус текущий (в т.ч. 0) | → `SLIDE_OFF`, радиус max; эффект отменяется | — |
| slide завершён | | → `ON`; если есть `pending_` — старт эффекта | | → `OFF`; `applyDefaults()`; `blackout.start()` |
| `startEffect(id)` | игнор | `pending_ = id` | `effect_ = id` (заменяет текущий) | игнор |
| эффект завершён | | | `effect_ = None`, статическая заливка, `lastIdle = now` | |

Побочные эффекты:
- `powerOn()` — снимает `nightMode`, сбрасывает `cooldown`, сбрасывает таймеры активности. **Не** трогает `automation`.
- `powerOff(manual=true)` — запускает `cooldown` 15 с. `powerOff(manual=false)` (auto-off) — без cooldown.
- `applyDefaults()` — цвет (255, 140, 50), `base = Solid`, `brightness = 255`, `effect_ = pending_ = None`.
  Вызывается **только** в момент `SLIDE_OFF → OFF`, когда лента уже погашена — смена цвета незаметна (как v27).
- Слайд рисует базовый цвет с мягким краем `SLIDE_EDGE = 16` — 15 светодиодов между тёмным и полным
  цветом: яркость для глаза растёт по краю линейно и переводится в ШИМ через `cie8()` (§6.1).
  `maxRadius = 168/2 + 16 + 2 = 102`, шаг 33 мс → 102 × 33 ≈ 3,4 с. Так с v1.3.2; в v1.0.1 край был
  `SLIDE_EDGE = 11` (10 светодиодов) и линейный в ШИМ — его тёмная половина почти не видна глазу, 97 × 33 ≈
  3,2 с; в v27 — `SLIDE_EDGE = 9`, 95 шагов × 28 мс ≈ 2,7 с. Центр слайда при включении из `OFF` — случайный из `CENTERS = {9, 51, 93, 134}`.
- Выключение до первого шага slide-in (радиус ещё 0, т.е. в пределах ≈ 33 мс после включения) продолжает
  slide-out с радиуса 0: лента остаётся тёмной, `OFF` наступает через один шаг. С max радиуса slide-out
  стартует, только если slide-in уже завершён (`ON`) (Ruling R17; v27 в этом случае прыгал на max —
  всё кольцо вспыхивало и гасло полным slide-out).

`state` в телеметрии: `"ON"` для `SLIDE_ON`/`ON`, `"OFF"` для `SLIDE_OFF`/`OFF`.

### 4.2 Базовый режим и эффекты

| Имя (`effect`) | Тип | Действие |
|---|---|---|
| `solid` | базовый | `base = Solid` — цвет `r,g,b`, W = 0; выбор в HA останавливает идущий эффект (v1.2.1) |
| `makeup` | базовый | `base = Makeup` — RGB = 0, W = 255; выбор в HA останавливает идущий эффект (v1.2.1) |
| `dark` | временный | тёмная змейка: тёмный хвост 60 LED с твёрдой головой 4 LED, fade-in/out 30 шагов; 229 шагов × 40 мс ≈ 9,2 с |
| `rainbow` | временный (порядок цветов — v1.4.2) | радужная змейка той же геометрии, смешивание с базой по альфе. Шесть опорных цветов — красный, жёлтый, зелёный, голубой, синий, фиолетовый — стоят через 10 светодиодов от головы; с v1.4.2 при каждом запуске они перемешиваются в случайном порядке (Фишер — Йетс, все 720 порядков равновероятны), между соседними опорными цвет идёт кратчайшим путём по цветовому кругу (для противоположных — по часовой), хвост возвращается к цвету головы. В v27 порядок всегда был красный → жёлтый → … → фиолетовый; `RandomFn`, возвращающий 0, сохраняет его |
| `wave` | временный | тёмный пульс из случайного центра, две волны CW/CCW встречаются на `168/2`, `max(darkCW, darkCCW) × fadeOut`; 103 шага × 45 мс ≈ 4,6 с |
| `flame` | временный (v1.4.0, заменил `breathe`; шире и глубже в v1.4.1) | «пламя»: «дышат» отдельные участки — блок из ровного ядра `FLAME_CORE_MIN..MAX` = 10–12 светодиодов и мягкого края с каждой стороны, пропорционального ядру (`flameEdge(core)` = треть ядра с округлением: 10 → 3, 11 → 4, 12 → 4; равные для глаза шаги, у края 3 — ¼, ½, ¾ глубины), всего 16–20 светодиодов; ядро по косинусу гаснет до `FLAME_FLOOR` = 77 (30 % **для глаза**, CIE 1931) и возвращается за 3–5 с. Каждый блок на своих часах: новый — с вероятностью 15 % за шаг в случайном месте, не ближе 2 светодиодов к другим (большинство попыток попадает на занятое место), не больше 8 разом, в среднем видно около 4. В v1.4.0 блоки были 10–15 светодиодов вместе с краем 3 и гасли до 60 % — на зеркале почти незаметно. 667 шагов × 30 мс ≈ 20 с; в последние 5 с новых нет — эффект затихает сам. `breathe` (v1.2.0–v1.3.2) гасил всё кольцо разом: 3 цикла по 4 с до той же глубины, ≈ 12 с |
| `embers` | временный (v1.2.0, переделан в v1.3.0, углублён в v1.3.1) | «угли»: около одного пятна на 12 светодиодов — «уголёк», центр которого по косинусу уходит до 10–30 % **для глаза** (CIE 1931; в v1.3.0 — 30–50 %) и возвращается за 1–2,5 с, с градиентным краем `EMBERS_EDGE` = 2 светодиода с каждой стороны (2/3 и 1/3 глубины, равные для глаза шаги; в v1.3.0 — один сосед на половину глубины); каждый уголёк на своих часах (новый — с вероятностью 25 % за шаг, не ближе 5 светодиодов к другим, не больше 24 разом). 667 шагов × 30 мс ≈ 20 с; в первые секунды угольки разгораются, в последние 2,5 с новых нет — эффект сходит на нет сам. В v1.2.0 все 168 светодиодов понемногу дрожали разом в 40–100 % ШИМ (70–100 % для глаза) — получалась почти незаметная рябь |
| `comet` | временный (v1.2.0) | «метеор»: белая голова с хвостом 40 LED из случайной точки в случайную сторону, один оборот + хвост; 209 шагов × 30 мс ≈ 6,3 с. Хвост с v1.3.0 гаснет равномерно для глаза (`lerpPerceptual`, CIE 1931), в v1.2.0 — квадратично в ШИМ |
| `random` | действие | случайный из временных эффектов реестра; в `state` отражается реально запущенный |

Временные эффекты рисуются **поверх** базового режима (база передаётся в эффект каждый шаг) и после
завершения возвращают зеркало в статическую заливку. В `state.effect` отдаётся имя идущего временного
эффекта, иначе — имя базового режима.

**Переходы (v1.2.0).** `r,g,b`, `base` и `brightness` — это *цели*: их отдаёт `state`, и меняются они сразу.
На экране — *показанные* значения (`shownColor_`, `shownBrightness_`), которые догоняют цель:

- изменение цвета, яркости или режима командой (`set`, `makeup/set`) или двойным кликом при горящем
  зеркале — переход за `TRANSITION_MS` = 500 мс шагом `TRANSITION_STEP_MS` = 20 мс (примитив `Ramp`); с v1.3.0
  он равномерен для глаза (`lerpPerceptual`/`lerp8Perceptual`, CIE 1931, точно в начальном и конечном
  цвете), в v1.2.0 был линейным в ШИМ и «проскакивал» тёмную часть; новая команда посреди перехода начинает
  новый переход от текущего показанного цвета;
- диммирование удержанием кнопки — сразу (оно и так ступенчатое, шаг 30 мс);
- включение из `OFF`/`SLIDE_OFF` — новые значения сразу, slide-in играет уже в них (иначе двойной клик во
  время slide-out показал бы старый solid);
- при выключенном зеркале — сразу; `applyDefaults()` сбрасывает и показанные значения.

Эффекты, slide и глитч берут цвет через `baseColor()` = показанный цвет и видят переход; каждый кадр
заканчивается `finishFrame()` — умножением на показанную яркость.

### 4.3 Кнопка

`Button` превращает сырой уровень в события. Аппаратный антидребезг — программного нет (как v27).

| Жест | Событие | Реакция `Mirror` |
|---|---|---|
| 1 клик | `Click(1)` | `OFF`/`SLIDE_OFF` → `automation = true` (v1.5.0), `powerOn()`; иначе `powerOff(manual)` |
| 2 клика | `Click(2)` | `OFF`/`SLIDE_OFF` → `base = Makeup`, `automation = true` (v1.5.0), `powerOn()`; иначе переключить `Solid ↔ Makeup` |
| 3 клика | `Click(3)` | `startEffect(random)` (в `OFF` игнорируется) |
| ≥ 4 клика | `Click(n)` | игнор |
| удержание ≥ 500 мс | `HoldStart` | `OFF`/`SLIDE_OFF` (v1.5.0) → переключить `nightMode`, а `automation` — вслед за ним: `false` при включении ночного режима, `true` при снятии (v1.5.1, чтобы HA видел, работает ли датчик); **заблокировать диммирование до конца удержания**, свет не включается. Включение ночного режима подтверждается одной вспышкой тёмного кольца, снятие — двумя (см. ниже); при снятии ещё и `cooldown` 15 с — PIR не зажжёт свет ни во время удержания, ни сразу после (Ruling R14); запускается после `automation = true`, чей переход `false → true` паузу сбрасывает. В `SLIDE_ON`/`ON` — ничего, яркость меняют `HoldTick`. До v1.5.0 удержание из `OFF` включало свет (§11.1 п. 6), а ночной режим снимало в любом состоянии |
| удержание, каждые 30 мс | `HoldTick` | если не заблокировано и `power == ON` → отменить эффект, `brightness ± 5` с отскоком в границах 5..255 |
| отпускание после удержания | `HoldEnd` | снять блокировку; **клик не засчитывается** (правило №5) |

**Подтверждение ночного режима (v1.5.0).** Флаг переключается сразу, а тёмное кольцо показывает результат
тёплым цветом по умолчанию: включение — одна вспышка `SIGNAL_ON_FLASH_MS` = 1 с, снятие — две по
`SIGNAL_OFF_FLASH_MS` = 400 мс через 200 мс. Каждая вспышка — косинус до `SIGNAL_LEVEL` = 77 (30 % **для глаза**,
CIE 1931), кадр раз в 20 мс (`Blink` — только тайминг, кадр рисует `Mirror::tickConfirmation`). Сигнал
фиксированный: цвет и яркость, пришедшие из HA при выключенном свете, его не меняют. Удержание во время
slide-out откладывает вспышку до `OFF`. Любое включение света обрывает вспышку и отбрасывает отложенную.
**Клик, включающий свет, включает и автоматику (v1.5.0):** иначе зеркало, включённое рукой при выключенной
в HA автодетекции, горело бы до ручного выключения. Включение из HA, Алисы и PIR флаг не трогает.

Параметры: окно между кликами 400 мс (последовательность разрешается через 400 мс после последнего отпускания),
порог удержания 500 мс. Любое событие кнопки сбрасывает таймеры активности.

**Залипшая кнопка (v1.2.1).** Удержание дольше `HOLD_STUCK_MS` = 60 с считается залипанием (влага на кнопке
или на триггере Шмитта): `Button` перестаёт выдавать `HoldTick` до отпускания. Без этого яркость бесконечно
гуляла бы 5↔255, каждый тик считался бы активностью (зеркало не гасло бы никогда), а `state` уходил бы
в MQTT четыре раза в секунду. Флаг залипания защёлкивается, поэтому переполнение разности времени через
49,7 суток тики не вернёт. При отпускании `HoldEnd` приходит как обычно, и кнопка снова работает.
Кнопка, **нажатая уже при загрузке**, нажатием не считается, пока её не отпустят: первый опрос только задаёт
исходный уровень. Иначе после каждой перезагрузки залипшая кнопка снова давала бы `HoldStart` — включала свет
или снимала восстановленный из RTC-памяти ночной режим.

### 4.4 Автоматика и PIR (`MotionGate`)

| Флаг / таймер | Кто меняет | Смысл |
|---|---|---|
| `automation` (по умолчанию `true`) | `motion/set`; клик, включающий свет (v1.5.0); удержание кнопки при выключенном свете — вместе с ночным режимом (v1.5.1) | Главный выключатель автоматики. `false` → нет автовключения, автовыключения и автоэффектов. Держится до `motion/set ON` или кнопки. |
| `nightMode` (по умолчанию `false`) | `motion_disable/set`, удержание кнопки при выключенном свете (вкл/выкл, v1.5.0), любое `powerOn()` | «Глухое» отключение PIR (Node-RED или кнопка, ночь). При включении — если свет горит, гасится. |
| `cooldown` 15 с | `powerOff(manual=true)`, снятие `nightMode` удержанием кнопки | PIR игнорируется после ручного выключения («не включать свет в спину уходящему») и после снятия ночного режима удержанием (Ruling R14). Внутренний, в HA не виден. |
| `blackout` 2 с | вход в `OFF` после slide-out | Защита от ложного срабатывания «отлипающего» датчика сразу после гашения. |

Правила:
- **Автовключение:** `pir == HIGH && power == OFF && automation && !nightMode && !cooldown.running(now) && !blackout.running(now)` → `powerOn()`.
  Срабатывание по **уровню** (как фактически работает v27), не по фронту.
- **Активность:** `pir == HIGH && power ∈ {SLIDE_ON, ON}` → `lastActivity = lastIdle = now` (независимо от `automation`).
- **Залипший PIR (v1.2.1):** если уровень HIGH держится без единого LOW дольше `PIR_STUCK_MS` = 60 мин, это
  неисправный датчик, а не человек: PIR перестаёт считаться активностью и перестаёт включать свет до первого
  LOW (флаг защёлкивается). Сырой уровень по-прежнему уходит в `pir/state`, так что HA может заметить
  неисправность. Отсчёт идёт от последнего фронта, поэтому занятая ванная с короткими паузами датчика под
  правило не попадает.
- **Команда при горящем зеркале — тоже активность (v1.2.1):** любая команда `set` (яркость, цвет, режим,
  эффект), `makeup/set` и `effect/set`, пришедшая при `power ∈ {SLIDE_ON, ON}`, вызывает `markActivity` —
  тот, кто её отправил, в ванной, даже если PIR его не видит (душ). Она же снимает предупреждающее затухание.
  Автоэффект по таймеру активностью **не** считается, иначе зеркало не гасло бы никогда.
- **`motion/set ON` также отмечает активность** (`lastActivity = lastIdle = now`) — иначе повторное включение
  автоматики после длительного простоя тут же вызвало бы автовыключение (Ruling R9).
- **Автовыключение:** `power == ON && automation && !nightMode && now − lastActivity > autoOffLimit()` → `powerOff(manual=false)`.
  Лимит зависит от базового режима (v1.2.0): `AUTO_OFF_MS` = 15 мин в solid, `AUTO_OFF_MAKEUP_MS` = **45 мин в Макияже**.
  Смена режима (solid ↔ makeup — командой `set`, переключателем `makeup/set` или двойным кликом) считается
  активностью и перезапускает таймер: иначе переход из Макияжа в solid на 30-й минуте погасил бы свет мгновенно.
  Условие не проверяет `effect_` — автовыключение может прервать идущий временный эффект (Ruling R10):
  эффекты короткие (≤ 9 с), прерывание — это просто slide-out от базового цвета.
- **Автоэффект:** `power == ON && effect_ == None && base == Solid && automation && !nightMode && now − lastIdle ≥ nextAutoEffect` → `startEffect(random)`;
  `nextAutoEffect` — случайное в [4, 5) мин, перевыбирается при каждом запуске случайного эффекта.
- **Предупреждение перед автовыключением (v1.2.0):** за `AUTO_OFF_WARN_MS` = 60 с до автовыключения
  (`now − lastActivity > лимит − 60 с`) рендер плавно (`WARN_FADE_IN_MS` = 2 с) затемняется до
  `WARN_DIM_LEVEL` = 128 — с v1.3.0 это 50 % **для глаза** (CIE 1931, ~18 % ШИМ; `finishFrame()` умножает кадр
  на `cie8(warnLevel_)`), в v1.2.0 было 50 % ШИМ — на глаз 76 %, затухание было едва заметно. Любая активность (PIR, кнопка, команда — всё, что вызывает `markActivity`)
  возвращает полную яркость за `WARN_FADE_OUT_MS` = 1 с и перезапускает таймер. Выключение автоматики посреди
  предупреждения тоже возвращает яркость (иначе свет остался бы на 50 % навсегда). Затемнение действует и во
  время эффекта: `finishFrame()` умножает кадр на `scale8(shownBrightness_, warnLevel_)`. Цели `brightness`
  и `state` не меняются — HA видит прежние значения.
- **Флаги переживают программную перезагрузку (v1.2.1).** `automation`, `nightMode` и `glitch` хранятся в
  RTC-памяти (`RTC_NOINIT_ATTR`, запись `PersistedFlags` с магическим числом и контрольной суммой FNV-1a) и
  восстанавливаются в `setup()` после сброса программой или сбоем — `SW` (сетевой watchdog), `PANIC`,
  `INT_WDT`, `TASK_WDT`, `WDT`, `BROWNOUT`. После включения питания и кнопки сброса — умолчания, даже если
  RTC-память случайно уцелела. Иначе ночная перезагрузка по watchdog снимала бы `motion_disable`, и PIR
  зажигал бы зеркало. Цвет, яркость и режим по-прежнему сбрасываются при каждом выключении (решение владельца).
- Все таймеры — через разность `now − start` (`uint32_t`), корректно переживают переполнение `millis()` (49,7 сут).
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

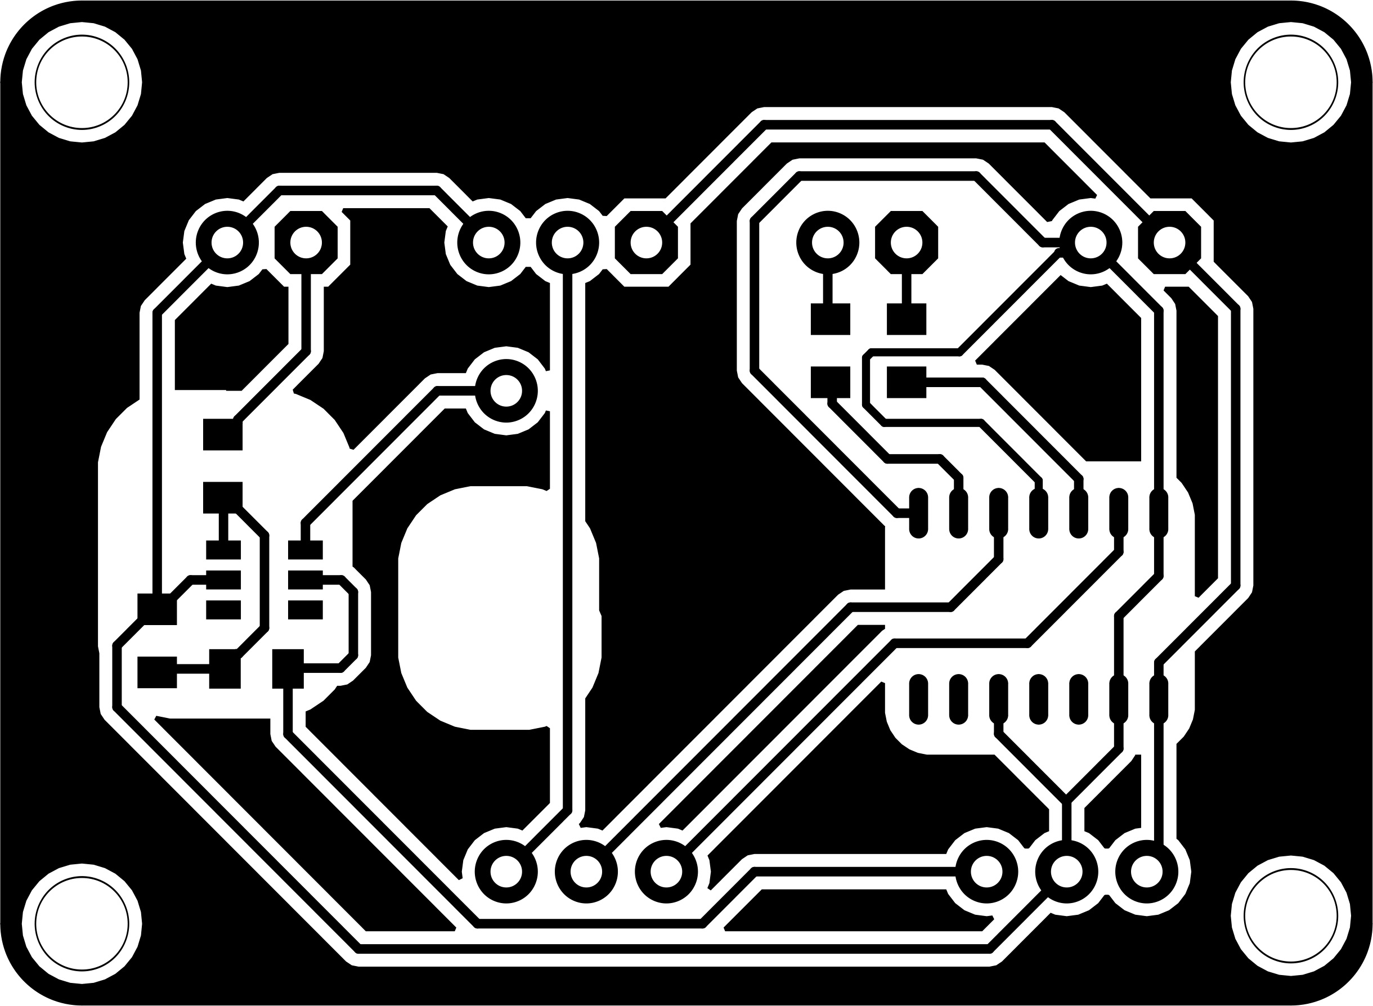
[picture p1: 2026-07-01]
Altium/Job1.jpg

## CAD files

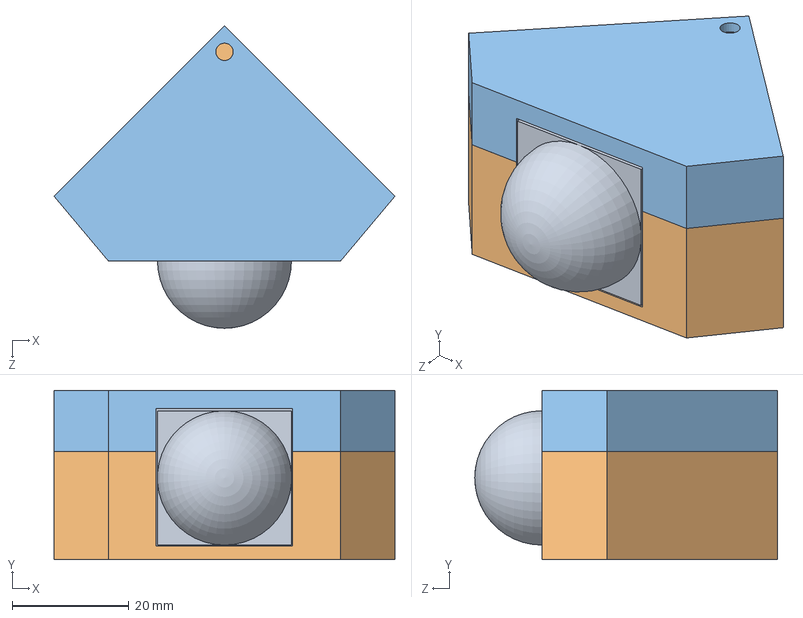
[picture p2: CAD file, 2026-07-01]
3D/PIR.SLDASM
58.4 x 29.0 x 51.8 mm
PIR
Деталь2^PIR
Деталь3^PIR

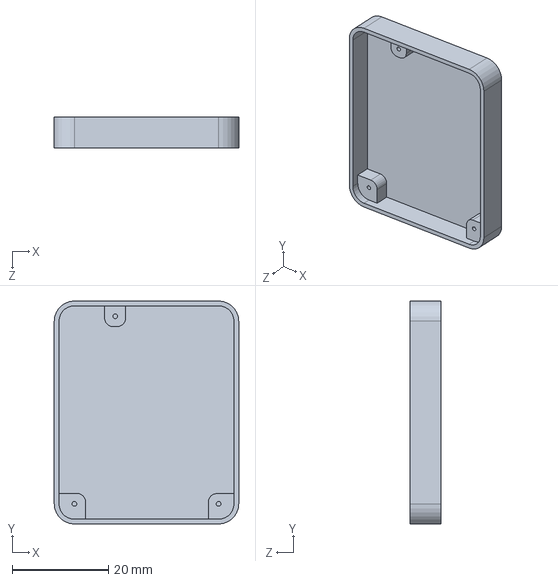
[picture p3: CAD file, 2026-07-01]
3D/PСB_box.SLDPRT
38.4 x 46.4 x 6.50 mm

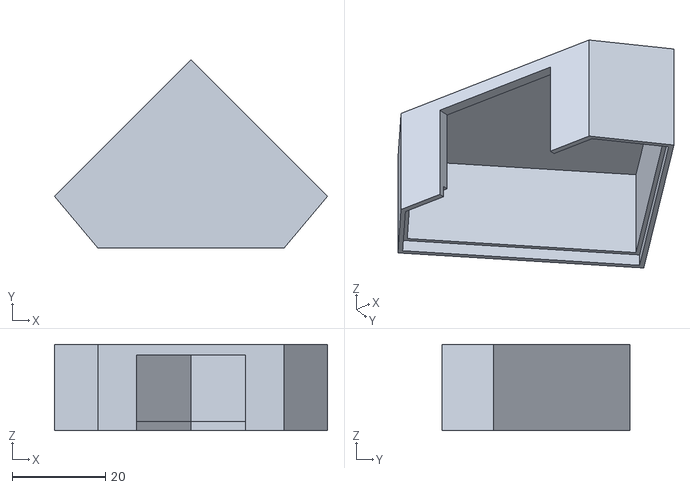
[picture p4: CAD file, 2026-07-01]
3D/Деталь2^PIR.STL
58.4 x 40.3 x 18.5

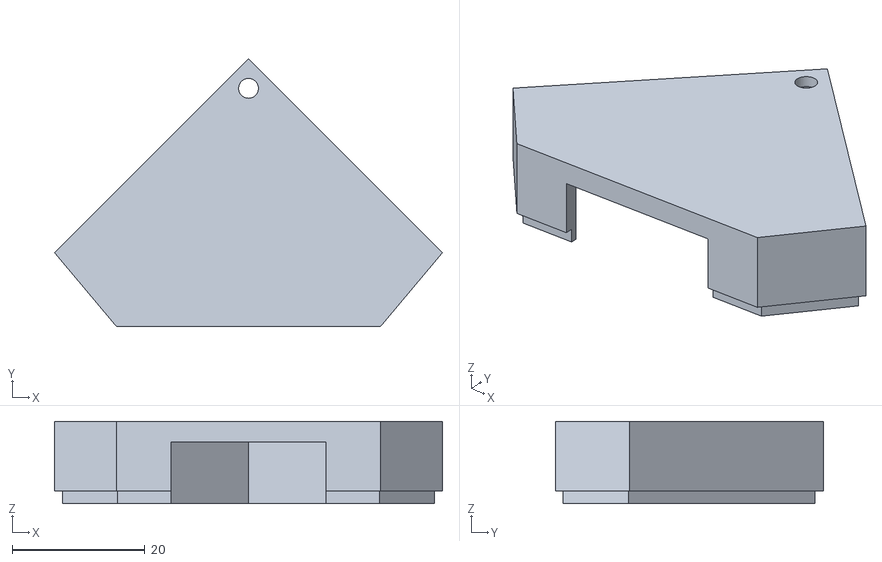
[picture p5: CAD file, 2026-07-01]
3D/Деталь3^PIR.STL
58.4 x 40.3 x 12.4

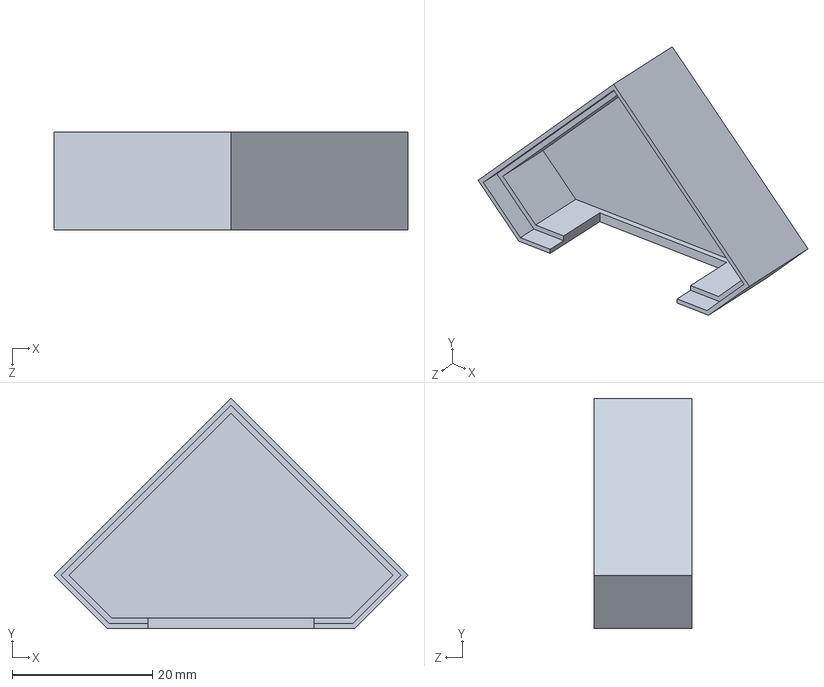
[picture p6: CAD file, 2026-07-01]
3D/PIR_box2.SLDPRT
50.4 x 32.8 x 13.9 mm

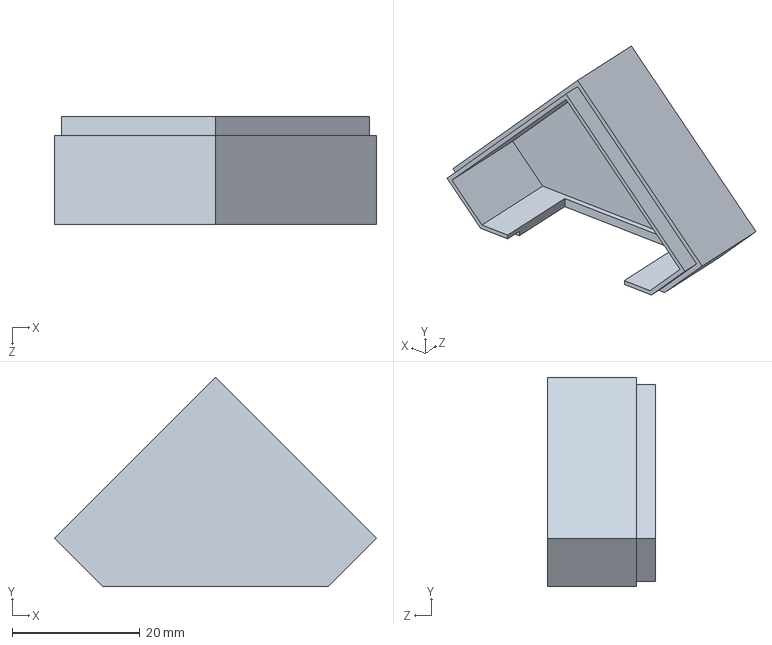
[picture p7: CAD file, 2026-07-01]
3D/PIR_box1.SLDPRT
50.4 x 32.8 x 16.9 mm

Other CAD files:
3D/PCB_box.STL
3D/PIR_box.SLDPRT
3D/PIR.SLDPRT
3D/PIR_box1.STL
3D/PIR_box2.STL

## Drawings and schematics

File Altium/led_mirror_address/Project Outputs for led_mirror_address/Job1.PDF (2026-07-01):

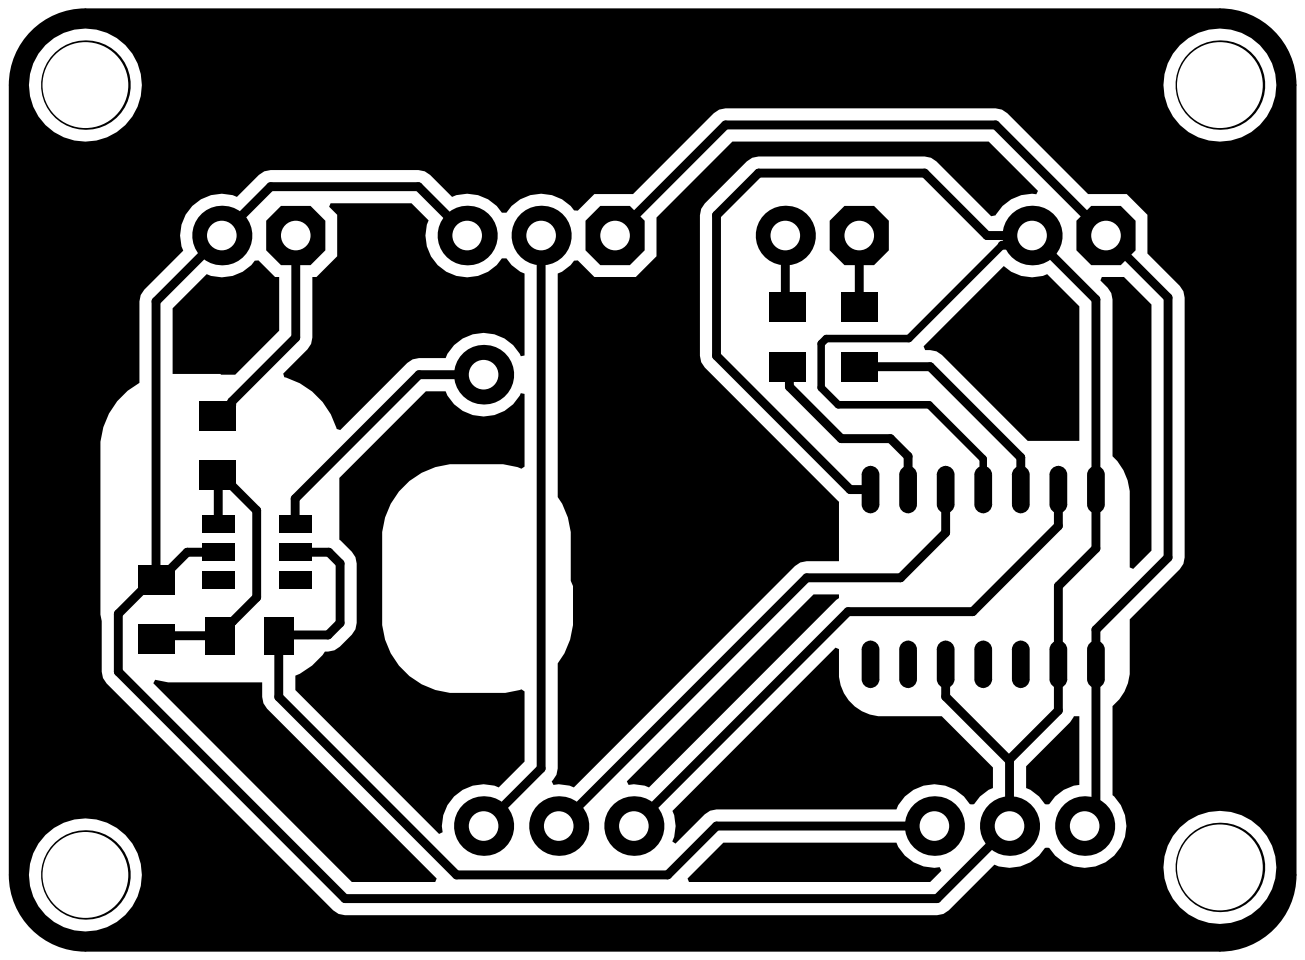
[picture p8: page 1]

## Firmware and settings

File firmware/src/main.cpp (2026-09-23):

// Smart Mirror firmware, v1.0.0. Core 1: setup()/loop() below — button, PIR,
// Mirror state machine, LedDriver (ARCHITECTURE.md 3.1, 3.3). Core 0:
// Network.cpp (WiFi/MQTT/watchdog). The two sides talk only through
// cmdQueue and snapQueue; neither core touches the other's objects.
#include <Arduino.h>
#include <esp_attr.h>
#include <esp_system.h>

#include <freertos/FreeRTOS.h>
#include <freertos/queue.h>

#include "Button.h"
#include "Config.h"
#include "LedDriver.h"
#include "Log.h"
#include "Mirror.h"
#include "Network.h"
#include "PersistedFlags.h"
#include "RmtLock.h"
#include "Types.h"

static uint32_t espRandom(uint32_t bound) { return bound ? esp_random() % bound : 0; }

// Automation, night mode and glitch kept across software restarts (network
// watchdog, panic, task watchdog, brownout) — RTC memory is not cleared by
// those, and is not initialised at power-on (PersistedFlags.h validates it).
RTC_NOINIT_ATTR static PersistedFlags rtcFlags;

static Mirror    mirror(espRandom);
static Button    button;
static LedDriver leds;

static QueueHandle_t cmdQueue  = nullptr;
static QueueHandle_t snapQueue = nullptr;

static StateSnapshot lastSnapshot;
static bool          redrawPending = false;  // last show() lost the RMT lock: draw again
static uint32_t      lastShowMs    = 0;      // last frame actually sent to the strips
static uint32_t      showFailingSince = 0;   // first show() that lost the RMT lock in a row

static void applyFlag(CommandType type, bool flag) {
    Command c;
    c.type = type;
    c.flag = flag;
    mirror.apply(c, millis());
}

// After a software restart, put back the switches HA/Node-RED had set: a
// watchdog reboot at night must not turn motion_disable off and let the PIR
// light the mirror. Only the non-default values need applying.
static void restoreFlags() {
    bool automation = true, nightMode = false, glitch = true;
    if (!shouldRestoreFlags(static_cast<uint8_t>(esp_reset_reason()))) return;
    if (!unpackFlags(rtcFlags, automation, nightMode, glitch)) return;
    if (!automation) applyFlag(CommandType::Automation, false);
    if (nightMode) applyFlag(CommandType::NightMode, true);
    if (!glitch) applyFlag(CommandType::Glitch, false);
    MLOG("restored after restart: automation=%d night=%d glitch=%d\n", (int)automation, (int)nightMode, (int)glitch);
}

void setup() {
    // First thing: SK6812s keep their last frame across an ESP reset (network
    // watchdog, panic, brownout), and their data lines float until begin().
    // Clearing them here keeps a reboot from leaving the old frame — or noise
    // picked up by the floating lines — on the ring for seconds. The RMT lock
    // (shared with the status LED on Core 0) must exist before the first show().
    if (!rmt_lock::init()) esp_restart();
    leds.begin();

    Serial.begin(115200);
#if DEBUG_LOG_ENABLED
    // Wait for a USB host only when there is someone to read the logs; in
    // the bathroom there is no USB host and the wait would just add 3 s.
    const uint32_t t0 = millis();
    while (!Serial && millis() - t0 < cfg::SERIAL_WAIT_MS) {}
#endif

    Serial.printf("\n\n=== Smart Mirror v%s ===\n", cfg::FW_VERSION);

    pinMode(cfg::PIN_BUTTON, INPUT_PULLDOWN);
    pinMode(cfg::PIN_PIR, INPUT_PULLDOWN);

    cmdQueue  = xQueueCreate(cfg::CMD_QUEUE_LEN, sizeof(Command));
    snapQueue = xQueueCreate(1, sizeof(StateSnapshot));
    // Out of memory at boot: a restart is the only sane answer — running on
    // would crash on a null queue or leave the mirror offline for good.
    if (cmdQueue == nullptr || snapQueue == nullptr) esp_restart();

    mirror.begin(millis());
    restoreFlags();

    lastSnapshot = mirror.snapshot();
    rtcFlags = packFlags(lastSnapshot.automation, lastSnapshot.nightMode, lastSnapshot.glitch);
    xQueueOverwrite(snapQueue, &lastSnapshot);

    if (!network::start(cmdQueue, snapQueue)) esp_restart();

    // Core 1 has no watchdog by default (the Arduino core leaves the loop
    // task unsubscribed and sdkconfig only watches the Core 0 idle task). A
    // hung show() or loop() would freeze the mirror for good while Core 0
    // kept reporting it healthy. With this the Arduino core feeds the task
    // watchdog before every loop() pass (every 5..12 ms); a pass that takes
    // longer than CONFIG_ESP_TASK_WDT_TIMEOUT_S (5 s) panics and reboots.
    enableLoopWDT();
}

void loop() {
    const uint32_t now = millis();

    Command cmd;
    while (xQueueReceive(cmdQueue, &cmd, 0) == pdTRUE) mirror.apply(cmd, now);  // 1. commands from network

    ButtonEvent ev = button.update(digitalRead(cfg::PIN_BUTTON) == cfg::BTN_PRESSED, now);  // 2. button
    if (ev.type != ButtonEventType::None) mirror.onButton(ev, now);

    mirror.onPir(digitalRead(cfg::PIN_PIR) == HIGH, now);  // 3. PIR
    mirror.tick(now);                                      // 4. timers + animation step

    // 5. output: when the frame changed, when the last attempt lost the RMT
    // lock and drew nothing, and every FRAME_REFRESH_MS regardless, so a
    // frame corrupted on the wire heals itself.
    const bool refreshDue = (uint32_t)(now - lastShowMs) >= cfg::FRAME_REFRESH_MS;
    if (mirror.takeFrameDirty() || redrawPending || refreshDue) {
        if (leds.show(mirror.frame())) {
            redrawPending = false;
            lastShowMs = now;
        } else {
            if (!redrawPending) showFailingSince = now;
            redrawPending = true;
            // The lock has been held for seconds: its holder hung in show().
            // loop() still feeds the task watchdog, so restart ourselves.
            if ((uint32_t)(now - showFailingSince) > cfg::SHOW_STALL_RESTART_MS) {
                MLOG("[%lu] RMT lock held for %lu ms -> restart\n", (unsigned long)now,
                     (unsigned long)(now - showFailingSince));
                esp_restart();
            }
        }
    }

    StateSnapshot s = mirror.snapshot();  // 6. snapshot for the network
    if (!(s == lastSnapshot)) {
        xQueueOverwrite(snapQueue, &s);
        lastSnapshot = s;
        rtcFlags = packFlags(s.automation, s.nightMode, s.glitch);  // kept for a software restart
    }

    vTaskDelay(pdMS_TO_TICKS(cfg::LOOP_IDLE_DELAY_MS));  // 5 ms
}

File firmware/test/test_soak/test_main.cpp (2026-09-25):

// Soak test for Mirror + Button (ARCHITECTURE.md section 4).
//
// Mirror and the real Button class are driven in the main.cpp loop order
// (commands, button, PIR, tick, frame, snapshot) by pseudo-random command,
// button and PIR streams, with irregular loop intervals and a millis() clock
// that crosses the 2^32 ms wraparound. After every loop iteration the state
// is checked against invariants and against a reference model of the timers
// that the harness keeps in 64-bit time, which never wraps: the auto-off
// moment, the pre-auto-off warning, the auto-effect deadline, the PIR
// cooldown/blackout and the stuck button/PIR limits must agree with it to
// the loop. Fixed long scenarios (a button or PIR stuck for weeks, a button
// stuck across a reboot, weeks on or off across the wrap, colour and warning
// fades vs the glitch, commands ending the warning) run through the same
// checker.
//
// Deterministic: fixed seeds and clocks. SOAK_DAYS=<days> lengthens the long
// random runs for a local soak. On a violation the run stops; the failure
// message names the run and the invariant, and `pio test -v` also shows the
// state and the tail of the event log (t = simulated seconds since the run
// started, ms = the millis() value Mirror saw).
#include <unity.h>

#include <cstdarg>
#include <cstddef>
#include <cstdint>
#include <cstdio>
#include <cstdlib>
#include <cstring>
#include <type_traits>

// The invariants read Mirror's internals (timers, ramps, glitch). Every
// standard header the firmware headers use is already included above, so
// the redefinition only opens up the firmware classes.
#define private public
#include "Button.h"
#include "Config.h"
#include "Mirror.h"
#include "Types.h"
#include "effects/EffectRegistry.h"
#undef private

void setUp(void) {}
void tearDown(void) {}

namespace {

constexpr uint64_t kMinute = 60ULL * 1000;
constexpr uint64_t kHour = 60 * kMinute;
constexpr uint64_t kDay = 24 * kHour;

// ----------------------------------------------------------------- random

struct XorShift {
    uint64_t s = 1;

    void seed(uint64_t v) {
        s = v * 0x9E3779B97F4A7C15ULL + 0x632BE59BD9B4E019ULL;
        if (s == 0) s = 1;
    }
    uint64_t next() {
        s ^= s << 13;
        s ^= s >> 7;
        s ^= s << 17;
        return s;
    }
    uint32_t below(uint32_t n) { return n ? static_cast<uint32_t>(next() % n) : 0; }
    uint32_t range(uint32_t lo, uint32_t hi) { return lo + below(hi - lo + 1); }
    bool chance(uint32_t perMillion) { return below(1000000) < perMillion; }
};

XorShift g_mirrorRng;  // behind Mirror's RandomFn: effects, glitch, delays
uint32_t mirrorRandom(uint32_t bound) { return g_mirrorRng.below(bound); }

// ----------------------------------------------------------------- event log

constexpr int kLogLines = 48;
constexpr int kLogWidth = 176;
char g_log[kLogLines][kLogWidth];
int g_logNext = 0;
int g_logCount = 0;

void logReset() {
    g_logNext = 0;
    g_logCount = 0;
}

void logDump() {
    const int first = (g_logNext - g_logCount + kLogLines) % kLogLines;
    for (int i = 0; i < g_logCount; ++i) printf("  %s\n", g_log[(first + i) % kLogLines]);
}

// The first violation, for the Unity failure message; the state and the
// event log tail go to stdout, which `pio test -v` shows.
char g_violation[320] = "";
#define RIG_OK(expr) TEST_ASSERT_TRUE_MESSAGE((expr), g_violation)

// ----------------------------------------------------------------- helpers

const char* powerName(PowerState p) {
    switch (p) {
        case PowerState::Off: return "OFF";
        case PowerState::SlideOn: return "SLIDE_ON";
        case PowerState::On: return "ON";
        case PowerState::SlideOff: return "SLIDE_OFF";
    }
    return "?";
}

const char* fxName(EffectId id) {
    const char* n = effectName(id);
    return n ? n : "none";
}

const char* buttonName(ButtonEventType t) {
    switch (t) {
        case ButtonEventType::None: return "none";
        case ButtonEventType::Click: return "click";
        case ButtonEventType::HoldStart: return "hold-start";
        case ButtonEventType::HoldTick: return "hold-tick";
        case ButtonEventType::HoldEnd: return "hold-end";
    }
    return "?";
}

bool isLit(PowerState p) { return p == PowerState::SlideOn || p == PowerState::On; }

uint32_t autoOffLimit(BaseMode b) { return b == BaseMode::Makeup ? cfg::AUTO_OFF_MAKEUP_MS : cfg::AUTO_OFF_MS; }

// The base colour the snapshot asks for (section 4.2).
Rgbw baseColour(const StateSnapshot& s) {
    return s.base == BaseMode::Makeup ? Rgbw{0, 0, 0, 255} : Rgbw{s.r, s.g, s.b, 0};
}

bool isDark(const Frame& f) {
    for (uint16_t i = 0; i < Frame::kSize; ++i) {
        const Rgbw& px = f[i];
        if (px.r || px.g || px.b || px.w) return false;
    }
    return true;
}

// v1.5.0: the night-mode confirmation on the dark ring — the default warm
// colour over the whole ring, no brighter than the SIGNAL_LEVEL peak.
bool isConfirmationFrame(const Frame& f) {
    const Rgbw peak = scale(Rgbw{cfg::DEFAULT_R, cfg::DEFAULT_G, cfg::DEFAULT_B, 0}, cie8(cfg::SIGNAL_LEVEL));
    const Rgbw& px = f[0];
    if (px.r > peak.r || px.g > peak.g || px.b > peak.b || px.w != 0) return false;
    for (uint16_t i = 1; i < Frame::kSize; ++i) {
        if (!(f[i] == px)) return false;
    }
    return true;
}

// Longest run of each temporary effect in steps (section 4.2 table).
uint32_t effectMaxSteps(EffectId id) {
    switch (id) {
        case EffectId::Dark:
        case EffectId::Rainbow: return cfg::TOTAL_LEDS + cfg::SNAKE_SIZE + 1;
        case EffectId::Wave: return cfg::TOTAL_LEDS / 2 + cfg::WAVE_RADIUS + 1;
        case EffectId::Flame: return cfg::FLAME_STEPS;
        case EffectId::Embers: return cfg::EMBERS_STEPS;
        case EffectId::Comet: return cfg::TOTAL_LEDS + cfg::COMET_TAIL + 1;
        case EffectId::None: break;
    }
    return 0;
}
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

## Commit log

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2026-07-02 firmware: защита PIR от ложных включений + Serial-логирование
    Проблема: при горящем свете иногда запускается анимация включения
    (slide-on от slideCenter). Корневая причина — ветка PIR в loop()
    реагирует на MODE_ANIM_OFF (идёт slide-out ~2.6 сек). Если в это окно
    PIR-сенсор дёрнет HIGH (отражение, отлипание, подстроечные крутилки),
    triggerPowerOn() перезаписывает slideRadius=0/slideMaxRadius — пользователь
    видит новое включение посреди выклю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
2026-07-02 firmware: команда motion_disable + кнопка-реактивация PIR (re=false)
    Node-RED-сценарий: «на ночь выключить реакцию на PIR». Сейчас эта
    семантика не выделена из motionDetection — отключение может быть
    снято либо повторной командой motion/set, либо авто-возвратом через
    15 сек (pirCooldownUntil). Для ночного режима нужно «глухое» отключение,
    которое держится, пока пользователь сам не вернёт.
    Новая подсистема:
    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
2026-09-21 build: pin toolchain, add native test env
    Set up the Task 0 project skeleton for the v27 -> modular v1.0.0 refactor:
    - platformio.ini: [platformio] default_envs, shared [esp32_base] section
    (board/flash/partitions/USB flags/monitor/lib_deps from ARCHITECTURE.md
    section 9), env:esp32-s3-zero (-DDEBUG_LOG_ENABLED=0) and
    env:esp32-s3-zero-debug (=1) extending it, plus env:native (platform =
    native, test_framework = unity, gnu++17) for lib/MirrorCore unit tests.
    Versions pinned exactly to what v27 resolved to on an unpinned
    `platform = espressif32` build: espressif32@7.1.3
    (framework-arduinoespressif32@4.20017.260907+sha.dcc1105b,
    toolchain-xtensa-esp32s3@8.4.0+2021r2-patch5), A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
    [test_main.cpp]
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2026-09-21 core: ColorMath, Frame, ring mapping with tests
    Task 1 (foundation headers of MirrorCore, part 2/2):
    - ColorMath.{h,cpp}: Rgbw (+ operator==), scale8 (v27-exact
    ((x*(1+k))>>8)), scale(Rgbw,k), hsv(hue) — bit-exact port of
    Adafruit_NeoPixel::ColorHSV(hue, 255, 255), packColor (Adafruit
    NEO_GRBW layout: w<<24 | r<<16 | g<<8 | b).
    - Frame.{h,cpp}: 168-pixel virtual ring buffer (fill/clear/scale,
    operator[]), ringDist (shortest wrap-around distance), PhysicalPixel
    + mapVirtual (virtual ring index -> physical strip/index, per
    ARCHITECTURE.md section 6; v27 setVirtualPixel semantics).
    - test/test_color_frame: adds scale8_bounds, pack_color_grbw_layout,
    hsv_primary_hues, map_virtual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
    [test_main.cpp]
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2026-09-21 core: Countdown and MotionGate with tests
    Task 3: overflow-safe Countdown (Ruling R7 update()) and MotionGate PIR
    automation gating (automation switch, night mode, 15s manual-off cooldown,
    2s slide-out blackout). TDD: test_motion RED (missing headers) then GREEN
    (10/10), full native suite 31/31 green, -Wall -Wextra clean.
    [test_main.cpp]
2026-09-21 test: cover Countdown/MotionGate R7 selectivity
    Review fix round 1: the R7 tests only ever called update()/tick() after
    expiry, so a broken update() that unconditionally clears `active` would
    have passed. Add the missing half of the contract — update()/tick() must
    leave a still-running countdown active/running — plus a concrete
    before/after refire-hazard demonstration.
    [test_main.cpp]
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2026-09-21 core: Mirror power and slide
    Mirror.{h,cpp}: single-owner state machine skeleton (ARCHITECTURE.md
    section 4 / 8.1). This slice covers power_/slide_: powerOn()/powerOff()
    internal ops, tick() steps 1 (gate_.tick) and 3 (slide render + finished
    transitions SLIDE_ON->ON / SLIDE_OFF->OFF with applyDefaults() +
    gate_.onOffReached()), and onButton() Click(1) dispatch.
    Table 4.1 rows covered: powerOn() Off/SlideOff cells, powerOff(manual)
    SlideOn/On cells, "slide finished" row (both cells, pending-effect start
    deferred to the next slice since startEffect() isn't implemented yet).
    Also covers power_on_during_slide_off_reverses (radius continues, frame
    never goes fully dark on reversal).
    Co-Authore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
    [test_main.cpp]
2026-09-21 core: Mirror button, PIR, commands
    Fills in startEffect(), onButton() (Click 1/2/3/>=4, HoldStart/Tick/End),
    onPir(), apply() (Light/Automation/Makeup/NightMode/RandomEffect), and
    tick() steps 4 (temporary-effect stepping) and 5 (static base fill).
    Table 4.1 "startEffect(id)" + "effect finished" rows, all four cells of
    the "—" (no-op) powerOn/powerOff cells (via Light state, the one path
    that calls them unconditionally), table 4.3 (button gestures) including
    bug A (hold started in night mode only clears night mode — must not
    power on or dim), dim_bounces_5_255, apply_defaults_only_after_slide_off,
    brightness_zero_turns_off, color_switches_to_solid, R9 (enabling
    automation never auto-off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
    [test_main.cpp]
2026-09-21 core: Mirror automation and snapshot
    Fills in tick() step 2 (idle-driven automation: auto-off after 15 min,
    auto-effect after 4-5 min, both gated on gate_.automationActive() &&
    power_==On, strict >), snapshot(), and a correct takeFrameDirty()
    (previously stubbed to always return false).
    Covers auto_off_after_15min_idle, no_auto_off_when_automation_off,
    auto_effect_only_in_solid, enabling_automation_does_not_auto_off_immediately
    (R9's idle-timer form — automation flag on always re-marks activity),
    snapshot_reports_running_effect_name (including pending_ staying hidden),
    frame_dirty_only_on_change, frame_brightness_applied, and isolates the 2s
    PIR blackout after slide-out (auto-off is manua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
    [test_main.cpp]
2026-09-21 test: strengthen Mirror tests (bug A, activity, table 4.1 cells)
    Fix round 1 from mutation-tested review of Task 5. Test-only changes;
    Mirror.{h,cpp} production behaviour is unchanged (verified against
    git HEAD throughout — every mutant below was applied, tested, then
    reverted with `git checkout`).
    1. Bug A regression (test_hold_in_night_mode_only_clears_night_mode):
    the old version never left power_==OFF during the hold, so
    HoldTick's own `power_ == On` guard blocked dimming regardless of
    holdLocked_ — deleting `holdLocked_ = true;` passed all 42 tests.
    Now drives power to ON *during* the same hold (PIR after night mode
    clears) and asserts brightness stays untouched for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
    [test_main.cpp]
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2026-09-21 test: pin Protocol clamp/sentinel cases; drop stale comment
    Fix round 1 from review of Task 6.
    1. firmware/test/test_protocol/test_main.cpp:7 named task-6-report.md,
    which lives in git-ignored .superpowers/ and is forbidden to reference
    from source comments (readers outside this session cannot resolve it).
    Reworded the header comment without naming the file. Grepped
    Topics.*/Protocol.*/the test for further task-/.superpowers
    references: none found elsewhere.
    2. Added test_light_non_integer_brightness_and_color_ignored: pins the
    named clamp risk explicitly for brightness ("128" string, 1e9
    exponential, 5000000000 int32-overflow) and for a colour component
    ("r": "200"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
    [test_main.cpp]
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2026-09-21 firmware: Network task and new main.cpp
    Replaces the v27 monolith main.cpp with the v1 Core 1 loop (setup/loop,
    cmdQueue/snapQueue, static Mirror/Button/LedDriver) and adds Network.cpp:
    the Core 0 NetworkTask (WiFi, MQTT, watchdog, publishing) per
    ARCHITECTURE.md 3.3/3.4/5.1. Network.cpp only ever sees Command/
    StateSnapshot crossing the two queues; it does not include Mirror.h,
    LedDriver.h, Button.h, Frame.h or effects/* (rule #2), so it cannot
    reach the Core 1 objects even at compile time.
    [main.cpp]
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2026-09-21 fix: publish latest snapshot on reconnect; apply hostname before WiFi.mode
    1. publishAll(latest) on MQTT (re)connect could publish a stale retained
    snapshot (link-drop or boot time) — the real one only followed ~1 loop
    later via publishChanged, causing a visible false transition for
    subscribers (e.g. pir/state ON->OFF, a phantom motion event). Drain the
    length-1 snapQueue mailbox right before publishAll so it always sends
    the newest snapshot. Also reset lastPublish/lastStatePublish from a
    fresh millis() taken after the blocking mqtt.connect() and 1 s green
    flash, not the `now` captured before them, so the rate limit and
    heartbeat don't restart early.
    2. WiFi.setHos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
2026-09-21 fix: audit — remove stale task-file references from firmware comments
    Task 8 audit (rule R13): grep for superpowers/task-N-*.md references in
    firmware/ found four comments in Mirror.cpp, Mirror.h and
    test_mirror/test_main.cpp pointing at gitignored planning docs
    (task-5-report.md, task-5-context.md). Reworded them to describe the
    code without referencing files outside the repo.
    [test_main.cpp]
2026-09-21 docs: README and ARCHITECTURE for v1.0.0
    Task 8 (audit + docs). ARCHITECTURE.md: mark spec approved/implemented
    (refactor/v1, Stage 3), replace the placeholder platform version in §9
    with the pinned versions from platformio.ini, add the v27-vs-v1.0.0
    Flash/RAM size table, and reconcile §4/§7/§8.1/§12 text with what the
    code actually does per rulings R3 (SlideAnimation API), R4 (Route/Topics
    live in Topics.h, not Protocol.h), R7 (Countdown::update/MotionGate::tick),
    R9 (activity rules), R10 (auto-off can interrupt a running effect), R11
    (hostname set before WiFi.mode), and R12 (new "Известные риски" note on
    the inherited Adafruit NeoPixel RMT race).
    README.md: drop stale c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
2026-09-21 docs: correct RAM growth explanation
    Review finding: §9.1's explanation blamed the FreeRTOS queues and the
    StatusLed object for the +1808 B static RAM growth, but xQueueCreate()
    and Adafruit_NeoPixel's pixel buffer are both heap-allocated and don't
    appear in PlatformIO's static (.data+.bss) figure at all. The real
    source is two new file-scope static objects: `Topics topics` in
    Network.cpp (12 × char[96] = 1152 B) and the `Frame` member inside
    Mirror (168 × sizeof(Rgbw) = 672 B) — together ~1824 B, matching the
    measured delta.
2026-09-21 fix: night-mode hold starts PIR cooldown
    A hold that clears night mode now also starts the 15 s PIR cooldown
    (same as a manual OFF), so a user standing in front of the mirror no
    longer relights it via the PIR in the same loop iteration, during the
    hold or right after release. The bug-A dimming lock is kept and is now
    proven with a Light state:1 command mid-hold instead of the PIR.
    [test_main.cpp]
2026-09-21 refactor: generic temporary effect requests
    EffectRequest no longer mirrors EffectId: a named temporary effect is
    EffectRequest::Temporary plus LightCommand::effectId, resolved through
    the registry (effectIdFromName / effectInstance). Protocol and Mirror
    lose their per-effect switch tables, so adding an effect is exactly:
    the effect class + test, an EffectId value + kEffects[] row, and the
    name in the HA effect_list. LightCommand documents its clamp/-1
    precondition. Structs stay trivially copyable.
    [test_main.cpp]
2026-09-21 fix: status LED blinks only on heartbeat; skip PIR-only state publishes
    publishState() takes a blink flag: only the 10 s heartbeat blinks the
    status LED, so its NeoPixel show() calls no longer scale with the
    snapshot change rate (PIR edges, effects, dimming) — R12 exposure back
    to v27 level. publishChanged() republishes the retained state JSON only
    when a field that appears in it changed (new stateJsonDiffers(), which
    ignores pir); a PIR-only change goes out on pir/state alone.
    [test_main.cpp]
2026-09-21 fix: slide-off from radius 0 stays dark
    SlideAnimation::startOff() now resets to SLIDE_MAX_RADIUS only when the
    radius is outside [0, SLIDE_MAX_RADIUS) (slide-on finished, or slide-out
    already ended). Switching off before the slide-on rendered its first
    step keeps radius 0: the slide-out stays dark and reaches OFF in one
    step instead of lighting all 168 pixels and playing a full slide-out.
    Slide tests that meant "from ON" now complete a slide-on first; golden
    frame values are unchanged.
    [test_main.cpp]
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2026-09-21 fix: redundant night-mode OFF no longer cancels the PIR cooldown (R18)
    motion_disable/set OFF now cancels the 15 s PIR cooldown only when it
    actually clears night mode. A repeated OFF (night mode already off, e.g. a
    Node-RED flow re-sending it right after a night-mode button hold) used to
    reopen the PIR and let it relight the mirror at the person holding the
    button. Tests cover the gate (redundant OFF keeps cooldown, real OFF still
    clears it) and the Mirror scenario from the final review.
    [test_main.cpp]
2026-09-21 fix: redundant automation ON no longer cancels the PIR cooldown
    Same rule as R18 for night mode: motion/set ON now cancels the 15 s PIR
    cooldown only when it actually turns automation back on. A repeated ON
    (automation already on) no longer reopens the PIR, e.g. right after a
    night-mode button hold. Enabling automation still marks activity (R9).
    The Mirror regression test for both redundant commands shares one helper.
    [test_main.cpp]
2026-09-22 docs: статус v1.0.0 — проверена на железе
    Прошивка v1.0.0 собрана, прошита в зеркало и работает так же, как v27.
    ARCHITECTURE.md: статус в шапке (ветка refactor/v1 слита в main,
    проверка на железе 22.09.2026). README.md: итог проверки на железе,
    история версий (main вместо ветки refactor/v1, 129 тестов, исправления
    паузы PIR при повторных motion_disable/set OFF и motion/set ON).
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2026-09-23 fix: медленный MQTT-брокер больше не перезагружает зеркало
    PubSubClient ждёт ответа брокера на подключение (CONNACK) и остаток
    пакета в пустом цикле, не отдавая процессор задаче простоя ядра 0.
    Task watchdog ядра Arduino следит за ней с таймаутом 5 с и паникует,
    а таймаут сокета библиотеки по умолчанию — 15 с. Медленный брокер
    (подвисший Mosquitto, хост HA на медленной SD-карте, пара потерянных
    TCP-сегментов на слаб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
2026-09-23 fix: лента гасится первой строкой setup(), без 3 с ожидания USB
    SK6812 держат последний кадр при сбросе ESP, а их линии данных висят
    в воздухе, пока драйвер не инициализирован. Раньше лента чистилась
    только после ожидания USB-Serial (до 3 с), а в ванной USB-хоста нет,
    так что эти 3 с проходили на каждой загрузке. После любой перезагрузки
    (сетевой watchdog, паника, просадка питания) на кольце 3+ секунды
    висел ст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
    [main.cpp]
2026-09-23 fix: общая блокировка RMT для ленты и статус-светодиода (R12)
    Adafruit NeoPixel 1.15.5 на ESP-IDF 4.4 на каждый show() заново
    настраивает канал RMT, ставит драйвер, передаёт кадр и снимает драйвер.
    Лента (ядро 1) и статус-светодиод (ядро 0) делали это без взаимной
    блокировки. Окно гонки оказалось не «несколько инструкций», а десятки
    микросекунд: снятие последнего драйвера выключает и сбрасывает модуль
    RMT, стир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
    [main.cpp]
2026-09-23 fix: watchdog на ядре 1 — зависший loop() перезагружает, а не замораживает
    Ядро Arduino по умолчанию не подписывает задачу loop() на task
    watchdog, а sdkconfig следит только за задачей простоя ядра 0. Зависни
    отправка кадра на ленту (например, потерянное прерывание RMT) или сам
    loop() — зеркало замерло бы навсегда: лента на последнем кадре, кнопка
    и PIR не работают, а ядро 0 продолжает слать heartbeat, и HA видит
    «всё в пор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
    [main.cpp]
2026-09-23 fix: текущий кадр переотправляется на ленту раз в 2 с
    SK6812 держат то, что последним защёлкнули, а кадр уходил на ленту
    только при изменении. Кадр, испорченный помехой на линии данных или
    сбоем RMT, оставался до следующего изменения — в выключенном зеркале
    хоть всю ночь (несколько светящихся точек на «выключенном» зеркале).
    Теперь loop() отправляет текущий кадр и без изменений, если с прош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
    [main.cpp]
2026-09-23 fix: команда из HA/Алисы при горящем зеркале — активность
    Раньше таймер автовыключения сбрасывали только PIR, кнопка, включение
    и смена режима. Команда «Алиса, яркость зеркала 80 %» из душа, где PIR
    не видит человека, не снимала предупреждающее затухание, и через минуту
    свет гас — хотя документация и описание пункта 9 обещали, что затухание
    снимает любая активность, включая команды.
    Тепе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
    [test_main.cpp]
2026-09-23 fix: сетевой watchdog не гасит горящее зеркало и не реагирует на брокер
    Раньше 5 минут суммарного простоя WiFi или MQTT вели к немедленной
    перезагрузке. Если HA обновлялся полчаса, зеркало гасло каждые ~5,5 мин
    прямо во время использования и сбрасывало ночной режим и автоматику,
    хотя мёртвый брокер перезагрузка не лечит.
    Теперь (решение владельца, «умный» вариант):
    - 5 минут без WiFi -> перезагрузк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
    [test_main.cpp]
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2026-09-23 fix: адрес брокера ищется потокобезопасно, подключение — по IP
    Брокер задан в secrets.h именем хоста, поэтому PubSubClient на каждой
    попытке подключения звал WiFi.hostByName() из Arduino-ESP32 2.0.17. Тот
    вызывает dns_gethostbyname() без блокировки ядра lwIP (гонка с таймером
    DNS) и бросает ожидание по своему таймауту. Если DNS-серверы молчат
    дольше, запоздалый ответ записывал 4 байта в кадр стека, которого уже
    нет, — порча па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
2026-09-23 fix: настоящее состояние публикуется до availability=online
    При переподключении порядок был: «online» → секундная вспышка
    статус-светодиода → публикация состояния. HA при появлении доступности
    показывает закешированное состояние до следующего сообщения, поэтому
    после перезагрузки или обрыва связи он секунду видел, например, старое
    «вкл», а потом настоящее «выкл» — ложный фронт для автомат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
2026-09-23 fix: выбор solid/makeup в HA останавливает идущий эффект
    В списке эффектов HA рядом с временными эффектами стоят базовые режимы
    solid и makeup. Выбор solid во время «свечи» только менял базовый режим:
    эффект доигрывал до 20 с, state.effect продолжал сообщать candle, и
    список в HA отпрыгивал обратно.
    Теперь выбор solid или makeup сразу снимает идущий и отложенный эффект
    и плавно переводит кольцо в выбранный режим. Из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
    [test_main.cpp]
2026-09-23 fix: глитч не стартует посреди цветового перехода и затухания
    Цветовой переход и предупреждающее затухание перерисовывают кадр каждые
    20 мс, а статическая заливка между шагами снимает флаг перерисовки.
    Глитч, чей момент выпадал на тик между шагами, стартовал и тут же
    обрывался следующим шагом: вспышка на 15–20 мс (ядро гасло на мгновение),
    и эта минута глитча пропадала.
    Теперь glitchAllowed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
    [test_main.cpp]
2026-09-23 fix: при нехватке памяти state и diag не публикуются урезанными
    ArduinoJson при отказе в выделении памяти молча отбрасывает поля и всё
    равно сериализует остаток — например, «{}». Такой документ проходил
    проверку размера и уходил в MQTT как retained <base>/state: HA получал
    пустое состояние и держал его до следующей публикации.
    Теперь buildStateJson и buildDiagJson проверяют doc.overflowed() и
    возвращают 0, как при нехватке буф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
    [test_main.cpp]
2026-09-23 fix: проверка создания очередей и сетевой задачи при старте
    Результаты xQueueCreate и xTaskCreatePinnedToCore не проверялись. Если
    при старте не хватало памяти, первое же xQueueReceive(nullptr) роняло
    прошивку по assert, а несозданная сетевая задача оставляла зеркало без
    сети навсегда — и ничто этого не замечало.
    Теперь network::start() возвращает результат, а setup() при любой
    неудаче делает esp_restart(). На свежей куче при ст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
    [main.cpp]
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2026-09-23 fix: переподключение WiFi не обрывает ожидание адреса от DHCP
    При потере WiFi задача делала disconnect()+begin() и ждала до 10 с. Но
    после ассоциации с точкой доступа статус остаётся WL_IDLE_STATUS, пока
    DHCP не выдаст адрес. После перезагрузки роутера DHCP бывает медленнее
    10 с, и каждая попытка обрывалась за мгновение до успеха — зеркало
    оставалось без сети до сетевого watchdog, и так по кругу.
    Теперь в состоянии W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
2026-09-23 chore: версия прошивки 1.2.1
    Ревизия надёжности поверх 1.2.0: watchdog на обоих ядрах, блокировка
    RMT, повтор кадра, «умный» сетевой watchdog, флаги в RTC-памяти, защита
    от залипших кнопки и PIR и другие исправления этой ветки. Поле fw в
    state и diag теперь 1.2.1.
    [test_main.cpp]
2026-09-23 fix: сетевой watchdog ждёт 30 с тишины и переподключает WiFi при мёртвом MQTT
    Ревью ветки нашло ошибку в предыдущем исправлении. Горящее зеркало
    ждало выключения, но latest.on гаснет уже в начале slide-out, а без
    WiFi проход задачи длится ~10 с. Перезагрузка случалась в первые
    секунды после выключения и стирала 15-секундный кулдаун PIR: человек
    нажал «выкл», уходит, а через секунду зеркало загорается у него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
    [test_main.cpp]
2026-09-23 fix: ожидание DHCP определяется по битам связи и ограничено 60 с
    Ревью ветки нашло дыру в недавнем исправлении ожидания DHCP. Попытка
    подключения не перезапускалась, пока статус WL_IDLE_STATUS, но ядро
    Arduino 2.0.17 ставит его и после LOST_IP (через 120 с после обрыва),
    когда связи с точкой доступа уже нет. Если перед этим авто-переподключение
    ядра сдалось (AUTH_FAIL, ASSOC_LEAVE), begin() больше никто не вызывал,
    и зерка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
2026-09-23 fix: перезагрузка, если блокировку RMT держат дольше 2 с
    Ревью ветки нашло изъян в блокировке RMT. Adafruit NeoPixel на IDF 4.4
    ждёт конца передачи без таймаута. Если так зависнет show()
    статус-светодиода на ядре 0, он держит блокировку вечно: лента на ядре 1
    каждый раз отказывается от кадра через 50 мс, но loop() продолжает
    крутиться и кормит watchdog. За ядром 0 watchdog следит только через
    задачу простоя, а она при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
    [main.cpp]
2026-09-23 fix: кнопка, нажатая уже при загрузке, не считается нажатием
    Первый опрос кнопки воспринимался как фронт нажатия, если уровень уже
    высокий. После каждой перезагрузки залипшая кнопка через 500 мс давала
    HoldStart: включала свет или снимала ночной режим, только что
    восстановленный из RTC-памяти, — защита от залипания срабатывала заново
    лишь через минуту.
    Теперь первый опрос только задаёт и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
    [test_main.cpp]
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2026-09-23 docs: сводка v1.2.1 — ревизия надёжности
    размеры прошивки (Flash 732185 Б, RAM 47488 Б; +2,3 КБ и +56 Б к
    1.2.0), намеренные изменения поведения 20–24, описание набора test_soak
    и 233 тестов, пункты 13–18 чек-листа проверки на железе.
    В «Известные риски» добавлено то, что сознательно не исправлялось: нет
    ограничителя тока лент (нужно измерение; просадки видны в HA как
    BRO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
2026-09-23 feat: края глитча 4–6 светодиодов, градиент по CIE 1931
    Владелец: градиент краёв почти незаметен. Причина двойная: краёв было
    всего 2–3 светодиода, а переход шёл линейно в ШИМ — 25/50/75 %, что
    для глаза 57/76/89 %: сразу за тёмным ядром почти полная яркость.
    Теперь краёв 4–6 (GLITCH_EDGE_MIN..MAX), и переход идёт равными для
    глаза шагами от яркости ядра до полной: при погасшем ядре край из 4
    светодиодов — 20/40/60/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
    [test_main.cpp]
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2026-09-23 docs: примеры кода в ARCHITECTURE и комментарий в ha_mirror.yaml догоняют v1.3.0
    При обновлении графа разбор документов нашёл примеры, отставшие от кода:
    - §7: пример kEffects[] перечислял только dark/rainbow/wave — теперь все
    шесть эффектов и пометка, что candle убран в v1.3.0;
    - §8.1: EffectId без breathe/embers/comet, CommandType и Route без
    Glitch, StateSnapshot без glitch и lastEffect, Topics без glitchSet,
    glitchState и diag, в Protocol не было DiagInfo, buildDiagJson,
    resetReasonName и нового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

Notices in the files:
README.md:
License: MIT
